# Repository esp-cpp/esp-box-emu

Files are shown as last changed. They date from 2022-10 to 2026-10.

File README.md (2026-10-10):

# esp-box-emu

<table style="padding:10px">
    <tr>
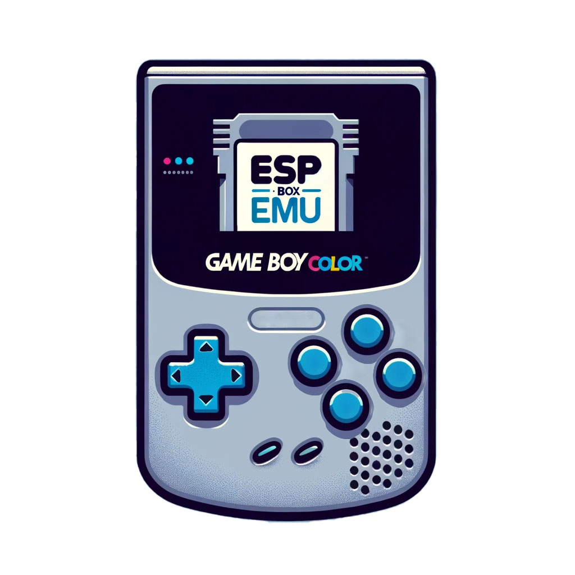
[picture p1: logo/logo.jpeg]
        <td></td>
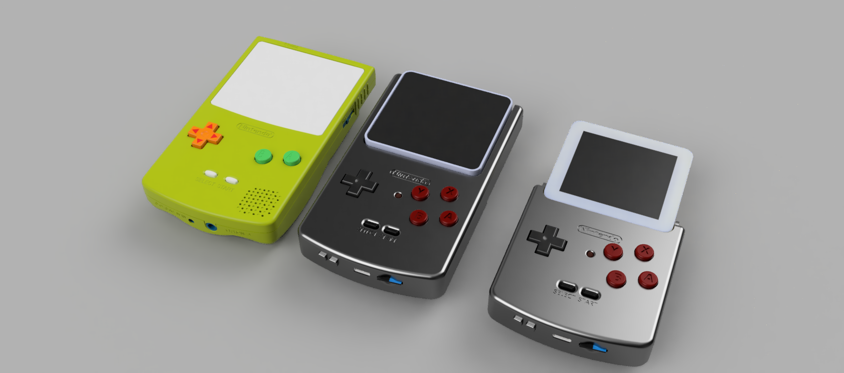
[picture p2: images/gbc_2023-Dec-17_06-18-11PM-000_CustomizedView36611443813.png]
Rendering
        <td></td>
    </tr>
</table>





> A pocket-sized, Game Boy-style retro **emulation handheld** built around the
> ESP32-S3-BOX. Drop in a micro-SD card of ROMs and play NES, Game Boy / Color,
> Sega, MSX, and Genesis games — plus a full-speed port of **Doom** — on hardware
> you can 3D print and build yourself.



https://github.com/user-attachments/assets/2d3da6ea-2e80-42c3-bbd6-5a2c59601201

<!-- markdown-toc start - Don't edit this section. Run M-x markdown-toc-refresh-toc -->
**Table of Contents**

- [esp-box-emu](#esp-box-emu)
  - [Overview](#overview)
  - [Emulators](#emulators)
  - [Gallery](#gallery)
  - [Quick Start — Play It](#quick-start--play-it)
  - [Build the Hardware](#build-the-hardware)
  - [Build the Firmware](#build-the-firmware)
  - [ROMs and SD Card Setup](#roms-and-sd-card-setup)
    - [Boxart images](#boxart-images)
    - [metadata.csv format](#metadatacsv-format)
  - [Features and Roadmap](#features-and-roadmap)
  - [References and Inspiration](#references-and-inspiration)
  - [License](#license)

<!-- markdown-toc end -->

## Overview

The ESP-BOX-EMU turns an [ESP32-S3-BOX or
ESP32-S3-BOX-3](https://github.com/espressif/esp-box) into a handheld retro game
console. A custom add-on board and 3D-printed shell wrap the BOX in a Game Boy
Color form factor — real d-pad and buttons, battery, haptics, and a micro-SD
slot — and the firmware runs a stack of emulators behind a polished LVGL
interface with boxart, save states, and settings.

**Highlights**

- 🎮 **Six systems + Doom** — NES, Game Boy / Color, Sega Master System / Game
  Gear, Sega Genesis, and MSX 1/2 emulators, plus a full-speed **Doom** port —
  all with sound.
- 🧬 **Full-speed Genesis** — a custom **dual-core** port of gwenesis splits the
  emulation across both of the ESP32-S3's cores (CPU + video on one, the sound
  unit on the other) for full-speed Sega Genesis / Mega Drive *with* audio.
- ⚡ **No reboots** — every core and game loads on demand right from the menu, so
  you can jump between titles and even different systems without ever restarting
  the device.
- 🕹️ **Real controls** — d-pad, A/B/X/Y, Start/Select and volume buttons in a
  familiar Game Boy Color layout; the emulator is auto-selected from the ROM
  file extension.
- 💾 **Load from SD** — keep ROMs, boxart, and save states on a micro-SD card,
  and mount the card over USB-C as a mass-storage drive (TinyUSB MSC).
- 💤 **Save anywhere** — up to 5 save slots per game, each with an
  auto-generated screenshot shown in the load menu.
- 🔋 **Portable** — 1000 mAh LiPo battery with USB-C charging.
- 📳 **Haptics** — LRA haptic feedback (DRV2605), including in-game effects in
  Doom (weapon fire, taking damage, pickups, and more).
- 🖼️ **Polished UI** — LVGL menus for ROM select (with boxart) and settings
  (sound, brightness, display scaling, haptics), designed in Squareline Studio.
- 🛠️ **Fully open hardware** — 3D-printable GBC-style case and an open PCB
  (Fusion/Eagle **and** [atopile](https://atopile.io) + [KiCad](https://kicad.org)),
  all included in this repo.

## Emulators

The right emulator is chosen automatically from each ROM's file extension, and
games load on demand **straight from the menu — no reboot required**. Pick a
title, play, then drop back to the menu and launch a different game (or a
completely different system) without ever restarting the device. Every core runs
with audio, and several offer an **Unlocked mode** (toggle with the **X** button)
that removes the frame-rate cap for maximum speed.

| System | Core | Unlocked mode | Notes |
| --- | --- | :---: | --- |
| NES | [nofrendo](https://github.com/espressif/esp32-nesemu) | ✅ | D-Pad / A / B / Start / Select |
| Game Boy / Color | [gnuboy](https://github.com/rofl0r/gnuboy) | ✅ | D-Pad / A / B / Start / Select |
| Sega Master System / Game Gear | [smsplus](https://github.com/ekeeke/smsplus-gx) | ✅ | D-Pad / A / B / Start / Select |
| Sega Genesis / Mega Drive | [gwenesis](https://github.com/bzhxx/gwenesis) | — | Full speed with sound; 6-button pad (A→B, B→A, C→Y) |
| MSX 1 / 2 | [fmsx](https://fms.komkon.org/fMSX/) | — | D-Pad / A / B / Start / Select |
| Doom | [prboom](https://prboom.sourceforge.net/) | — | Full speed with audio **and haptic feedback** |
| Dark Forces | [The Force Engine](https://theforceengine.github.io/) (via [BSzili's Amiga port](https://github.com/BSzili/TheForceEngine/tree/amiga)) | — | Software renderer, iMuse sound effects and OPL3 music; see [Dark Forces setup](#dark-forces-setup) |
| PICO-8 | [femto8](https://github.com/benbaker76/femto8) | — | `.p8` and `.p8.png` carts; D-Pad, A/Y = O, B/X = X, START = PICO-8 pause menu; save states; cartdata saves to `pico8/cdata/`; see [PICO-8 setup](#pico-8-setup) |

> 🧬 **Full-speed Genesis on the S3.** The Genesis core ships with a custom
> **dual-core** modification of gwenesis that spreads the workload across both of
> the ESP32-S3's CPU cores: **core 0** runs the 68000 CPU and VDP (video), while
> **core 1** runs the sound unit (Z80 + YM2612 FM synth + PSG). Sound-chip writes
> are queued and applied in order on core 1, which lets Genesis / Mega Drive
> games run at full speed *with* audio — something a single core can't keep up
> with.

<details>
<summary><strong>Doom controls and haptics</strong></summary>

**Controls:** **A** fire / enter · **B** strafe / backspace · **X** use ·
**Y** weapon toggle · **START** escape · **SELECT** map.

**Haptic feedback** is triggered when you fire a weapon (varies by weapon), take
damage (scaled to the health/armor lost), interact with something (e.g. a door),
or pick up a weapon, ammo, health, armor, a power-up, or a key / card.
</details>

<details>
<summary><strong>Dark Forces controls</strong></summary>

**In a mission:** **D-pad** move / turn · **A** fire · **B** jump · **X** use ·
**Y** next weapon · **START** escape menu. Hold **SELECT** as a modifier:
**SELECT + Left/Right** strafe · **SELECT + Down** crouch · **SELECT + Up**
automap · **SELECT + A** secondary fire · **SELECT + B** headlamp ·
**SELECT + X** gas mask · **SELECT + Y** previous weapon · **SELECT + START**
night vision. Running is always on.

**Menus, briefings and cutscenes:** the **D-pad** moves a virtual mouse cursor,
**A** clicks, **START** is Enter, **B** is Escape (skips cutscenes) and **Y** is
Space. Quitting from the game's escape menu returns to the emulator menu.

**Typing an agent name:** hold **SELECT**: **Right** adds a letter, **Up/Down**
change the last letter, **Left** deletes it; release SELECT and press **START**
to confirm.

The emulator's own pause menu (touch button or START+SELECT) still works for
video scaling and save slots; save slots only work while in a mission.
</details>

## Gallery







https://github.com/esp-cpp/esp-box-emu/assets/213467/3b77f6bd-4c42-417a-9eb7-a648f31b4008

https://github.com/esp-cpp/esp-box-emu/assets/213467/a3d18d03-c6a1-4911-89d1-e18119e8cc03

## Quick Start — Play It

Already have the add-on hardware (or an ESP32-S3-BOX you want to flash)? You
don't need to build anything from source — a prebuilt one-time **programmer** is
published with every release.

1. Download the `programmer` for your OS (`windows`, `macos`, or `linux`) from
   the latest [releases page](https://github.com/esp-cpp/esp-box-emu/releases).
2. Unzip it.
3. Run it: double-click the `.exe` on Windows, or run it from a terminal on
   macOS / Linux, e.g.:

   ```sh
   ./esp-box-emu_programmer_v1.0.0_macos.bin
   ```

   (The version in the filename matches the release you downloaded.)

Then [set up a micro-SD card](#roms-and-sd-card-setup) with your ROMs and you're
ready to play.

## Build the Hardware

The add-on is designed to match the Game Boy Color form factor and reuse GBC
button plastics and silicone membranes for an authentic feel. The shell is meant
to be 3D printed (PLA or PETG on a Prusa i3 mk3+) and assembled with M3 screws.

**Case / mechanical** — printable files are in [./mcad](./mcad) or on
[Printables](https://www.printables.com/model/396931-esp-box-emu). CAD is on
[Fusion 360 (free viewer)](https://a360.co/3le5oCQ):

Fusion 360 CAD (https://a360.co/3le5oCQ)

**Electronics** — schematic and layout files are in [./ecad](./ecad), provided
as both Fusion/Eagle files and [atopile](https://atopile.io) +
[KiCad](https://kicad.org) sources. You can also order the board directly:

<a href="https://www.pcbway.com/project/shareproject/ESP_BOX_EMU_92551d33.html">PCB from PCBWay</a>

**GBC replacement buttons / membranes** used for a good play feel:

- [Silicone pads for Game Boy Color (1)](https://funnyplaying.com/collections/product/products/gbc-replacement-silicone-pads)
- [Silicone pads for Game Boy Color (2)](https://www.retromodding.com/products/game-boy-color-silicone-pads)
- [Game Boy Color button plastics](https://funnyplaying.com/collections/product/products/cgb-custom-buttons?variant=39333911920701)

## Build the Firmware

This repo uses submodules, so clone it recursively:

```sh
git clone --recurse-submodules git@github.com:esp-cpp/esp-box-emu
```

If you already cloned it non-recursively (or forgot the flag), pull the
submodules with:

```sh
git submodule update --init --recursive
```

Then build, flash, and open the serial monitor with [ESP-IDF](https://docs.espressif.com/projects/esp-idf/en/latest/esp32s3/get-started/index.html):

```sh
idf.py -p PORT flash monitor
```

Replace `PORT` with your board's serial port. To exit the monitor, type
`Ctrl-]`.

## ROMs and SD Card Setup

Format a micro-SD card as **FAT** and add your ROMs (`.nes`, `.gb`, `.gbc`, …),
boxart images (`.jpg`), and a `metadata.csv` file (see the example
[metadata.csv](./metadata.csv)).

### Boxart images

Boxart displays best at 100 px wide. The
[./boxart/source/resize.bash](./boxart/source/resize.bash) script resizes every
`.jpg` in `boxart/source` to 100 px wide (preserving aspect ratio) and writes the
results to the `boxart` folder. Copy those onto the SD card and reference them
from your metadata file.

### Dark Forces setup

Dark Forces is played with the original (purchased) game data; the engine does
not include it. Copy the DOS install files onto the SD card into a single
folder, for example `darkforces/`:

```
darkforces/DARK.GOB
darkforces/SOUNDS.GOB
darkforces/SPRITES.GOB
darkforces/TEXTURES.GOB
darkforces/LFD/*.LFD       (menus, briefings and cutscenes)
```

Then reference `DARK.GOB` from `metadata.csv`:

```csv
darkforces/DARK.GOB, boxart/darkforces.jpg, Star Wars: Dark Forces
```

Settings (`settings.ini`) and agent / save files are written to the same folder.

### PICO-8 setup

PICO-8 carts are plain `.p8` text files or `.p8.png` cartridge images. Put them
in a folder on the card (for example `pico8/`) and reference them from
`metadata.csv`:

```csv
pico8/celeste.p8, boxart/celeste.jpg, Celeste Classic
```

Carts that use `cartdata()` save to `pico8/cdata/`. The 128x128 screen shows
1:1 in the "original" video mode and scaled to 240x240 in "fit". Multi-cart
games that `load("#id")` their other carts work when those carts sit in the
same folder as `id.p8.png` / `id.p8`.

What to expect: the Lua interpreter runs at roughly 1.3M instructions per
second on the S3 (its heap lives in PSRAM), enough for carts of Celeste's
weight at full speed, but CPU-heavy carts close to PICO-8's limit run at a
few frames per second. Save states work (the cart's Lua heap and PICO-8
RAM are snapshotted between frames); carts' own `cartdata()` saves are kept
separately; there is no mouse or keyboard.

### metadata.csv format

Each line maps a ROM to its boxart and display name:

```csv
<rom filename>, <rom boxart filename>, <rom display name>
```

Example:

```csv
mario.nes, boxart/mario.jpg, Mario Bros.
super_mario_1.nes, boxart/super_mario_bros_1.jpg, Super Mario Bros.
super_mario_3.nes, boxart/super_mario_bros_3.jpg, Super Mario Bros. 3
zelda.nes, boxart/zelda1.jpg, The Legend of Zelda
zelda_2.nes, boxart/zelda2.jpg, The Legend of Zelda 2: the Adventure of Link
mega_man.nes, boxart/megaman1.jpg, MegaMan
metroid.nes, boxart/metroid1.jpg, Metroid
pokemon_blue.gb, boxart/pokemon_blue.jpg, Pokemon Blue
pokemon_red.gb, boxart/pokemon_red.jpg, Pokemon Red
pokemon_yellow.gbc, boxart/pokemon_yellow.jpg, Pokemon Yellow
links_awakening.gb, boxart/tloz_links_awakening.jpg, The Legend of Zelda: Link's Awakening
links_awakening.gbc, boxart/tloz_links_awakening_dx.jpg, The Legend of Zelda: Link's Awakening DX
```

## Features and Roadmap

A checklist of what's implemented and what's still in progress.

**Emulation**

- [x] Auto-select emulator by ROM extension: NES, GB/GBC, SMS/GG, MSX, Genesis, Doom, Dark Forces, PICO-8
- [x] On-demand core loading — every emulator and game loads at runtime with no reboot needed to switch games or systems
- [x] Custom **dual-core Genesis** (gwenesis): 68000 + VDP on one ESP32-S3 core, sound unit (Z80 + YM2612 + PSG) on the other, for full-speed audio and gameplay
- [x] Doom haptic feedback :rocket:
- [x] Save state (with automatic save-screenshot creation to the SD card)
- [x] Load state — up to 5 slots per game, with save-screenshot previews
- [x] Shared-memory system so many emulators can be built in together while keeping their hot state in fast internal RAM
- [x] Dark Forces (The Force Engine port; software renderer with sound and music)
- [ ] SNES emulator (WIP)

**User interface**

- [x] LVGL ROM-select menu with boxart and title, navigable by controller
- [x] LVGL settings menu (volume, video, haptics) and in-game pause menu
- [x] GUI data (titles + boxart) loaded from the [metadata file](./metadata.csv)
- [x] Squareline Studio source for the LVGL boilerplate ([SLS files](./squareline), [generated files](./components/gui/generated))

**Video and audio**

- [x] Emulator framebuffers in SPIRAM, with queued screen transfers for maximum draw speed
- [x] Video scaling with ORIGINAL, FIT, and FILL display modes
- [x] Audio output over I2S via the es8311 codec ([codec component](./components/codec))
- [x] Mute button toggles audio while a ROM is running
- [x] Haptic feedback via a DRV2605-driven LRA
- [ ] Decorative graphics in the black borders during NES / GB/C emulation (WIP)

**Storage and input**

- [x] micro-SD (FAT) filesystem over SPI
- [x] TinyUSB MSC device to expose the SD card to an attached USB host
- [x] Memory-mapping of the selected ROM from storage into a raw data partition (SPI flash)
- [x] D-pad + A/B/X/Y + Start/Select input (MCP23x17 on v0 hardware, AW9523 on v1)
- [x] Touchscreen input ([tt21100 component](./components/tt21100))

**Hardware**

- [x] Control-board schematic / layout: joystick / d-pad / buttons (via I²C I/O expander + ADC), battery, charger, DRV2605 haptics, micro-SD, boost converter, and USB 2.0 passthrough from USB-C
- [x] Case CAD in the GBC footprint: USB-C port, micro-SD slot, Start/Select, ABXY, and D-pad in familiar locations

## References and Inspiration

**Other NES emulators**

* https://github.com/nesemu/NESemu
* https://github.com/NiwakaDev/NIWAKA_NES
* https://github.com/kanathan/plainNES
* https://github.com/blagalucianflorin/lbnes
* https://github.com/daniel5151/ANESE
* https://github.com/Grandduchy/YaNES

**Other Genesis emulators**

* https://github.com/h1romas4/m5stack-genplus
* https://github.com/libretro/blastem

**Useful background / information**

* https://github.com/alnacle/awesome-emulators
* https://www.zophar.net/nes.html
* https://yizhang82.dev/nes-emu-overview
* https://www.gridbugs.org/zelda-screen-transitions-are-undefined-behaviour/
* https://bgb.bircd.org/pandocs.htm
* https://github.com/pebri86/esplay-gb
* https://github.com/hex007/esp32-gnuboy
* https://github.com/rofl0r/gnuboy
* https://github.com/zid/gameboy
* https://github.com/Jean-MarcHarvengt/MCUME
* https://github.com/OtherCrashOverride/go-play
* [SNES signal reference](https://gamefaqs.gamespot.com/snes/916396-super-nintendo/faqs/5395)
* [NES signal reference](https://wiki.nesdev.com/w/index.php/Standard_controller)
* [Genesis signal reference](https://www.raspberryfield.life/2019/03/25/sega-mega-drive-genesis-6-button-xyz-controller/)
* [DIY Game Boy](https://learn.adafruit.com/pigrrl-raspberry-pi-gameboy/overview)

## License

This project is licensed under the terms in [LICENSE](./LICENSE).

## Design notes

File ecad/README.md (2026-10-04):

# ESP-BOX-EMU ecad

This folder contains the electronic design of the ESP-BOX-EMU.

The ESP-BOX-EMU contains a single circuit board with the following components:
- USB-C connector
- Conductive / Membrane switches for d-pad, abxy, and start/select buttons which mate with GBC membranes and buttons
- Tactile switches for Volume +/-
- RED LED for charging indication
- DRV2605L haptic driver
- JST-PH connector for the LiPo battery
- AW9523 I/O expander
- MCP73831 LiPo charger
- MAX17048 LiPo state-of-charge monitor (I2C)
- MicroSD card slot
- TPS63020 5V buck-boost converter (battery -> 5V for the box)

These features are supported in two different versions of the electronics, targeting:
- ESP32-S3-Box
- ESP32-S3-Box-3

## Layout of this folder

- `elec/src/` - atopile sources (modern atopile >= 0.15 syntax)
- `elec/src/parts/` - atomic parts (auto-generated from LCSC plus local
  custom parts for the GBC membranes/buttons, board outlines and edge fingers)
- `elec/layout/` - KiCad layouts, one folder per build (netlist-synced by
  `ato build`; placement/routing edits are preserved)
- `scripts/` - layout automation (MCAD position export, scripted placement,
  base/connector layout sync)
- `Box Electronics v*.sch/brd`, `Box-3 Electronics v*.sch/brd` - the
  Fusion 360 / Eagle design the boards were actually manufactured from

The pre-migration atopile 0.2 sources, the old shared footprint library and
the old routed KiCad-6 boards were removed after the 0.15 migration; they
are available in git history (pre-2026-07) if ever needed.

## Setup

``` sh
# one time steps on your machine (any of these; uv shown)
uv tool install --python 3.14 atopile
```

Dependencies (e.g. `atopile/ti-tps63020`) are fetched automatically into
`.ato/modules/` on first build; `ato add <package>` adds new ones.

## Build

``` sh
# build everything
ato build

# build for ESP32-S3-BOX
ato build -b box-emu

# build for ESP32-S3-BOX-3
ato build -b box-3-emu
```

### Offline build (atopile 0.16 service migration)

As part of atopile's 0.16 platform migration (services moving from
`*.atopileapi.com` / `packages.atopile.io` to `app.atopile.io`), the hosted
components-picker API used by the 0.15.x CLI
(`components.atopileapi.com`) was taken offline, and no public replacement
endpoint exists for the CLI yet. Until atopile publishes a CLI that speaks
to the new services, build via the local stand-in server, which answers
picker queries from the part data already pinned in this repo:

``` sh
scripts/ato-build-offline.sh                 # all targets
scripts/ato-build-offline.sh -b box-emu-base # one target
```

Two caveats:

- Footprints/symbols still come from `build/cache/parts/easyeda/` (or the
  still-alive EasyEDA API). If the cache is stale (>1 day old), refresh the
  `atopile_queried_at` stamps inside the cached `C*.json` files rather than
  hammering EasyEDA's rate limiter with re-downloads.
- The stand-in returns no part *attributes*, so builds rewrite the hidden
  parameter annotations in the layouts to the design constraints (e.g. a
  resistor annotated `10kΩ ±1%` from the real part data becomes `±5%` from
  the design). The picked LCSC parts, BOM and copper are unchanged; a
  normal online build will restore the exact annotations once the service
  returns.

## Continuous integration

`.github/workflows/atopile.yml` (official `atopile/setup-atopile@v2` action)
builds every target from the checked-in sources with
`ato build --keep-picked-parts --keep-net-names --keep-designators`, then
runs `scripts/canonicalize-boards.py --all` and fails if `git diff` shows
any change to `elec/layout` or `elec/src` -- i.e. the checked-in design
must be exactly reproducible. (We don't use `ato build --frozen`: atopile
0.15.x writes KiCad group member lists in nondeterministic order, which
makes frozen flaky; the canonicalize+diff check gives the same guarantee
robustly.) It then exports gerbers, pick & place, BOM, STEP, GLB and a
rendered PNG for `box-emu` and `box-3-emu` (`-t all -t 3d-image`), plus
top/bottom PDFs via the kicad-cli bundled in the atopile container.
Artifacts are uploaded per board and attached to releases as zips.

Two reproducibility rules this relies on:

- **Parts are pinned.** None of the part `.ato` files carry the
  `is_auto_generated` trait: atopile would otherwise re-download every
  picked part from the EasyEDA API on each build and *replace* the
  checked-in part directory whenever the API response differs (which it
  does between regions, over time, and during their frequent partial
  outages). Without the trait, atopile logs "not overwriting" and the
  repo stays the source of truth. To intentionally update a part, delete
  its directory and re-run `ato create part --search <LCSC>`.
- **After local layout sessions**, run `ato build` +
  `python3 scripts/canonicalize-boards.py --all` and commit the result,
  so CI's rebuild matches byte-for-byte.

The LCSC/EasyEDA API has multi-hour outages; build steps retry, but a
run during a hard outage will still fail at part picking -- just re-run
it later.

## Ordering / manufacturing notes

**Surface finish: order ENIG, not HASL.** The GBC button footprints expose
bare-copper interdigitated fingers that the carbon membrane pucks press
against. With HASL those fingers come back coated in solder (uneven, prone
to oxidation) and the buttons work poorly; with ENIG they come back flat
gold, which is the standard finish for carbon-contact keypads. This is a
per-order fab option (JLCPCB: "Surface Finish" -> "ENIG") and cannot be
enforced from the design files.

Related, already handled in the footprints: the buttons' four corner
connection pads are tented (copper-only, no paste, no mask opening), so
PCBA assembly applies no solder anywhere on the button contact areas. If
you regenerate or edit `GBC_*_BUTTON` footprints, keep the pads
`(layers "F.Cu")` only.

## Working on the KiCad layouts

Each build owns one board file: `elec/layout/<build>/<build>.kicad_pcb`
(KiCad 9+ format; there is no `.kicad_pro` — open the `.kicad_pcb` directly
in KiCad's PCB Editor). The `fp-lib-table` next to each board resolves all
footprints from the atomic parts in `elec/src/parts/`, so the boards are
self-contained as long as the repo layout is intact.

The `.ato` sources are the source of truth for everything electrical;
KiCad is only for placement and routing:

``` sh
# build a target and open its layout in KiCad in one step
ato build -b box-3-emu --open

# or open it manually
open "elec/layout/box-3-emu/box-3-emu.kicad_pcb"
```

The edit loop:

1. Change schematics by editing the `.ato` files (never add/remove
   components or change connectivity in KiCad — the next build will
   revert it).
2. Run `ato build -b <build>`. This syncs footprints and nets into the
   board file. Footprints are matched by their `atopile_address` property,
   so your existing placement and routing are preserved; new components
   appear stacked near the origin for you to place.
3. Place/route in KiCad and save. **Close the board (or at least save it)
   before the next `ato build`** — atopile rewrites the file on disk, and
   KiCad's PCB editor will not auto-reload; reopen the file after each
   build. A stale `~<name>.kicad_pcb.lck` file means KiCad still has it
   open.

Useful flags when iterating on layout: `--keep-designators`,
`--keep-net-names`, and `--keep-picked-parts` take those from the existing
PCB instead of regenerating them, and `--frozen` fails the build if the
PCB would change at all (good for CI).

Recovering from common accidents:

- **Deleted a footprint in KiCad?** Harmless to the design -- the `.ato`
  source is the source of truth, and the next `ato build -b <build>`
  re-adds it (near the origin; its placement is lost, its part gets
  re-picked). Restore known positions with `place-parts.py apply` if it
  was a mechanically-placed part. It's worth running
  `place-parts.py dump` into `positions.json` after every good layout
  session (and committing it) so *every* part's placement has a snapshot.
- **"Duplicate designators found in layout"?** Historical cause: the
  custom KiCad-6-era footprints carried hidden legacy
  `(fp_text reference "U5")` blocks, and KiCad 9 migrates those over the
  Reference field on every load -- so any save reset references to
  library defaults. Fixed 2026-07 by stripping the legacy blocks from all
  custom part footprints and boards. If it ever recurs (e.g. from a
  re-imported old footprint):
  `python3 scripts/fix-duplicate-refs.py <board.kicad_pcb>` then
  `ato build -b <build>` to renumber.
- **Deleted tracks** are only recoverable from git -- commit layout
  checkpoints often.

### Layout reuse (shared button clusters)

Every module instance becomes a KiCad *group* in the board, and the child
builds (`gbc-a-b`, `gbc-dpad`, ...) exist so their layouts can be reused by
the parents. When a parent build adds a sub-module group whose footprints
are all new, atopile pulls that group's placement from the child build's
board. So do the layouts bottom-up, running `ato build` between levels:

* box-3-emu / box-emu (top-level: connector position, final routing)
  * box-3-connector / box-connector
  * box-emu-base (most of the placement/routing work)
    * gbc-dpad
    * gbc-start-select
    * gbc-a-b-x-y
      * gbc-a-b

i.e. lay out `gbc-a-b` first, then `gbc-a-b-x-y` (which pulls the a-b
group), then the other button boards, then `box-emu-base`, and finally the
two top-level variants. The automatic pull only happens when the group
first appears in the parent, so later tweaks to a child layout are not
force-propagated over a parent you've already edited.

To re-pull an updated child layout into a parent on demand, either use the
"Pull Group" toolbar button in the PCB editor (select the group first;
atopile installs the plugin into `~/Documents/KiCad/<ver>/scripting/plugins/`
-- as of atopile 0.15.x only up to KiCad 9.0, so for KiCad 10 copy the
`atopile.py` loader from the `9.0` folder into `10.0` and Tools > External
Plugins > Refresh), or run the same thing from the CLI:

``` sh
ato kicad-ipc layout-sync --legacy \
    --board elec/layout/box-3-emu/box-3-emu.kicad_pcb \
    --include-group connector      # omit to just sync group membership
```

### Shared base layout across the two variants

`BoxEmuBase` is one module, so it is one group (`box`) in both top-level
boards, and its layout — placement *and* routing — lives in exactly one
place: `elec/layout/box-emu-base/box-emu-base.kicad_pcb`. The intended
workflow:

1. Place and route everything except the connector in the **box-emu-base**
   build (use `positions.json` + the placement script below for the
   mechanically-constrained parts, then route by hand).
2. Push it into both variants:

   ``` sh
   ./scripts/sync-base-layout.sh   # pulls groups "box" and "connector"
                                   # into box-emu and box-3-emu, then snaps
                                   # the connector group to the base group
                                   # so the two outline pieces close exactly
                                   # (scripts/align-base-connector.py)
   ```

3. In `box-emu` / `box-3-emu`, only route the connector-bound signals --
   group placement and outline closure are handled by the sync script.
   The relative outline offsets were calibrated by fitting all outline
   footprints against the Eagle board outlines (0.000 mm rms) and live in
   `scripts/align-base-connector.py`.

If you drag the `box` or `connector` group while editing a top-level board
(fine for repositioning on the sheet), the two outlines separate -- re-run
`python3 scripts/align-base-connector.py` (safe standalone; it snaps the
connector group back to the base group, prints an outline-closure
verification, and refuses to run while the board is open in KiCad so a
later KiCad save can't silently undo it). Reopen the board in KiCad after
running it.

The connector footprints themselves (TE dock connector on box-3, PMOD /
power edge fingers on box) are placed within their boards from the STEP
assemblies via `elec/layout/box-connector/cad_map.json` and
`elec/layout/box-3-connector/cad_map.json`, same flow as the base board
(export -> place-parts apply -> build). Note the box-3 dock connector's
r=180 is meaningful: it puts pad A1 on the side that mates with the box,
matching the manufactured Eagle board.

Pulls replace the contents of the pulled group, so keep variant-specific
routing (base-to-connector tracks) outside the `box` group — tracks you
draw in the parent are not group members by default, so this is the
natural behavior; just don't add them to the group.

### Scripted placement from MCAD

Mechanically-constrained parts (buttons, membranes, USB-C, uSD, battery
connector, volume switches) have known positions that come from the
enclosure CAD. Those live in `elec/layout/box-emu-base/positions.json`,
keyed by each footprint's stable `atopile_address` (e.g.
`dpad.up_button.btn`, `usb_c.conn`, `uSD.card`) so they survive rebuilds
and designator changes. When the MCAD/STEP changes, update the numbers and
re-apply:

``` sh
# apply positions to the board (position, rotation, front/back side)
python3 scripts/place-parts.py apply \
    elec/layout/box-emu-base/box-emu-base.kicad_pcb \
    elec/layout/box-emu-base/positions.json

ato build -b box-emu-base       # re-sync the board
./scripts/sync-base-layout.sh   # push into both variants
```

`scripts/place-parts.py dump <board>` regenerates the JSON from the
board's current state (useful to bootstrap the file or to capture manual
edits back into it). The optional `transform` block (`dx`/`dy`/`flip_y`)
converts CAD coordinates into KiCad's frame (KiCad y points down). Parts
not listed in the JSON are never touched.

### Generating positions.json from the Fusion 360 assembly

Instead of typing coordinates by hand, positions are extracted from the
STEP exports of the enclosure assemblies (`mcad/esp-box-emu.step` and
`mcad/esp-box-emu-3.step`; the PCB must be present as a component in the
assembly). After re-exporting from Fusion 360:

``` sh
# 1. discover occurrence names in the STEP (only needed when the
#    assembly structure / names change)
uv run scripts/export-positions-from-step.py list ../mcad/esp-box-emu.step

# 2. update elec/layout/box-emu-base/cad_map.json if needed:
#    - board.occurrence: the PCB component's name
#    - board.axes / kicad_origin: the CAD->KiCad frame (already calibrated)
#    - each part's "cad" name (+ one-time r_offset rotation calibration)

# 3. extract placements into positions.json
uv run scripts/export-positions-from-step.py export \
    ../mcad/esp-box-emu.step \
    elec/layout/box-emu-base/cad_map.json \
    elec/layout/box-emu-base/positions.json

# 4. apply / rebuild / propagate as usual
python3 scripts/place-parts.py apply \
    elec/layout/box-emu-base/box-emu-base.kicad_pcb \
    elec/layout/box-emu-base/positions.json
ato build -b box-emu-base
./scripts/sync-base-layout.sh
```

The script is self-contained (`uv run` fetches its OCP dependency on first
use). Front/back side is detected from the part's frame orientation and
can be overridden per entry with `"side"`; `"r_offset"` absorbs the
difference between footprint and CAD 0-degree orientations; `"offset"`
(anchor-frame mm) places bodiless parts relative to a CAD neighbor (used
for the a/b/x/y/start/select carbon pads, anchored to their membranes).
Re-run steps 3-4 whenever the MCAD changes.

All three `cad_map.json` files (box-emu-base, box-connector,
box-3-connector) are fully calibrated (2026-07): the Fusion board
components use the Eagle brd coordinate frames verbatim, all outline
footprints match the Eagle outlines exactly (0.000 mm rms), and the
anchor-convention differences between the old board parts and the new
LCSC parts (uSD, USB-C, battery JST, volume switches) are encoded in each
entry's `"offset"`/`"r_offset"`. Re-exports of the STEPs therefore produce
correct placements with no further calibration unless a part is swapped
for a different physical component.

### KiCad 10 file-format warning

atopile 0.15.x reads/writes the KiCad 9 board format (`version 20241229`).
**KiCad 10 silently upgrades any board it saves to `version 20260206`,
which atopile cannot parse** -- builds of that target fail and layout
pulls silently skip the group ("Group ... not found in layout maps").
Until atopile ships KiCad 10 support, after editing a board in KiCad 10
run:

``` sh
python3 scripts/downgrade-kicad10-pcb.py elec/layout/<build>/<build>.kicad_pcb
ato build -b <build>   # normalizes the file back to atopile's format
```

(or do layout work in KiCad 9, which reads and writes the format natively).

Note: the boards in `elec/layout/` were regenerated during the atopile
0.15 migration. Mechanically-constrained placement is scripted from the
MCAD STEP files (see above); routing must be redone by hand. The old
routed boards (atopile 0.2 era, KiCad 6 format) are in git history
(pre-2026-07) if a routing reference is ever wanted.

## Differences from the manufactured (Fusion 360) boards

The atopile design intentionally deviates from the Eagle/Fusion `v36`/`v11`
boards in a few places, mostly to reduce battery drain when the board sits
idle (see git history for details):

- battery sense divider is 1M + 1M with a 100nF sampling cap (was 10k + 10k,
  which drained ~200uA from the battery continuously)
- 5V rail comes from a TPS63020 buck-boost in power-save (PFM) mode with
  VINA/EN properly tied to VIN and PS/SYNC tied low
- DRV2605L gets its datasheet-required 1uF REG bypass and a VDD decoupler
- the AW9523 interrupt line is routed to the box (IO21) on both variants

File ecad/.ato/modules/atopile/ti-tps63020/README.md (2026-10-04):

# Texas Instruments TPS63020 High Efficiency Single Inductor Buck-boost Converter

## Overview

The TPS63020 is a high-efficiency, single-inductor buck-boost converter with 4-A switches. It provides a power supply solution with a 1.8V to 5.5V input voltage range and delivers output voltages between 1.2V to 5.5V. This makes it ideal for battery-powered applications where the input voltage can be above, below, or equal to the output voltage.

## Key Features

- Input voltage range: 1.8V to 5.5V
- Output voltage range: 1.2V to 5.5V (adjustable)
- Output current: up to 3A (buck mode), 2A (boost mode)
- Switching frequency: 2.4MHz typical
- Efficiency: up to 95%
- Small solution size with integrated switches
- Power good output

## Usage

```ato

import ElectricPower

from "atopile/ti-tps63020/ti-tps63020.ato" import TPS63020_driver

module Usage:
    """
    Example usage of the TPS63020 buck-boost converter
    """

    # Power rails
    power_in = new ElectricPower
    power_3v3 = new ElectricPower

    # Configure input power (e.g., from battery)
    assert power_in.voltage within 2.5V to 5V

    # Configure output power
    assert power_3v3.voltage within 3.3V +/- 5%

    # Create buck-boost converter
    converter = new TPS63020_driver

    # Connect power
    power_in ~> converter ~> power_3v3
```

## Implementation Details

This package includes:
- Automatic calculation of feedback resistor values
- Proper decoupling capacitors on input and output
- Inductor selection with appropriate current rating
- Power good pullup resistor
- Compensation network calculations

The module automatically handles:
- Right half-plane zero frequency verification for stable operation
- Peak inductor current calculations
- Proper component sizing based on voltage and current requirements

## Contributing

Contributions to this package are welcome via pull requests on the GitHub repository.

## License

This atopile package is provided under the [MIT License](https://opensource.org/license/mit/).

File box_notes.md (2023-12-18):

### ESP32 S3 Box Info:

It uses GPIO_NUM_46 to control power to the speaker, so if you do not set that
as output HIGH, then you will never hear anything T.T

The ESP32 S3 Box has two PMOD headers, PMOD1 and PMOD2, which have the following
pins:

* PMOD1
  * IO40 (I2C_SCL)
  * IO41 (I2C_SDA)
  * IO38
  * IO39
  * IO42
  * IO21
  * IO19 (USB_D-, U1RTS, ADC2_CH8)
  * IO20 (USB_D+, U1CTS, ADC2_CH9)
* PMOD2
  * IO09 (FSPIHD, TOUCH9, ADC1_CH8)
  * IO10 (FSPICS0, TOUCH10, ADC1_CH9)
  * IO11 (FSPID, TOUCH11, ADC2_CH0)
  * IO12 (FSPICLK, TOUCH12, ADC2_CH1)
  * IO13 (FSPIQ, TOUCH13, ADC2_CH2)
  * IO14 (FSPIWP, TOUCH14, ADC2_CH3)
  * IO44 (U0RXD)
  * IO43 (U0TXD)

#### LCD

The LCD is a ST7789 320x240 BGR display connected via SPI.

ESP32s3 LCD Pinout:

| LCD Function | ESP I/O Pin |
|---|---|
| Data / Command | 4 |
| Chip Select | 5 |
| Serial Data | 6 |
| Serial Clock | 7 |
| Reset | 48 |
| Backlight | 45 |

#### Touch

The ESP32S3 Box uses a capacitive touch controller connected via I2C. On the
ESP32-S3-BOX it is a TT21100, and on the ESP32-S3-BOX-3 it is a GT911.

#### Audio

The ESP32s3 Box has a few audio codec coprocessors connected simultaneously to
I2S (data) and I2C (configuration). It uses an encoder codec chip (ES7210) for
audio input from the multiple mics on-board, and a decoder chip (es8311) for
audio output to the speaker (output power controlled by GPIO 46). It also uses

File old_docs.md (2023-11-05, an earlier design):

# esp-box-emu
Emulator(s) running on ESP BOX with custom pcb and 3d printed enclosure :)

https://user-images.githubusercontent.com/213467/236730090-56c3bd64-86e4-4b9b-a909-0b363fab4fc6.mp4

https://user-images.githubusercontent.com/213467/220791336-eb24116d-0958-4ab7-88bd-f6a5bd6d7eb1.mp4

## Description

This project is a little retro game emulation system running on ESP32-S3-BOX. It
is built using the following:

- [ESPP](http://github.com/esp-cpp/espp)
- [LVGL](http://github.com/lvgl/lvgl)
- [Squareline Studio](http://squareline.io) (for designing and generating LVGL)
- Nofrendo (NES emulator)
- GNUBoy (GB / GBC emulator)

## Videos

### Gameboy Color

This video shows settings page (with audio control and video scaling control), and then Links Awakening DX. While running the ROMs, the video scaling can be toggled through the three options (Original, Fit, and Fill) using the BOOT button on the side of the ESP-S3-BOX and the audio output can be toggled on / off using the MUTE button on the top.

https://user-images.githubusercontent.com/213467/202577104-da104296-c888-47f4-bb69-e1dcac7f3a08.mp4

### NES (Super Mario Bros. and Zelda, turning audio up for zelda :) )

https://user-images.githubusercontent.com/213467/200666734-d5fdd27e-d335-462b-9f27-c93c5750de01.mp4

https://user-images.githubusercontent.com/213467/201548463-9870a1c1-886c-4540-b1c6-c7ed3b49d8a5.mp4

### Gameboy (Pokemon and Links Awakening)

https://user-images.githubusercontent.com/213467/200667103-71425aa6-3e77-41b1-83d1-c2072a1a0ecb.mp4

Older Videos:
* [heavily compressed](https://user-images.githubusercontent.com/213467/200664203-46058c44-3025-4e81-973f-27ada573d5d2.mp4)
* [just zelda](https://user-images.githubusercontent.com/213467/199843965-1bf38a5f-2cc6-4ff0-adba-bbd67b366bc3.mp4)

## Images

<table style="padding:10px">
    <tr>
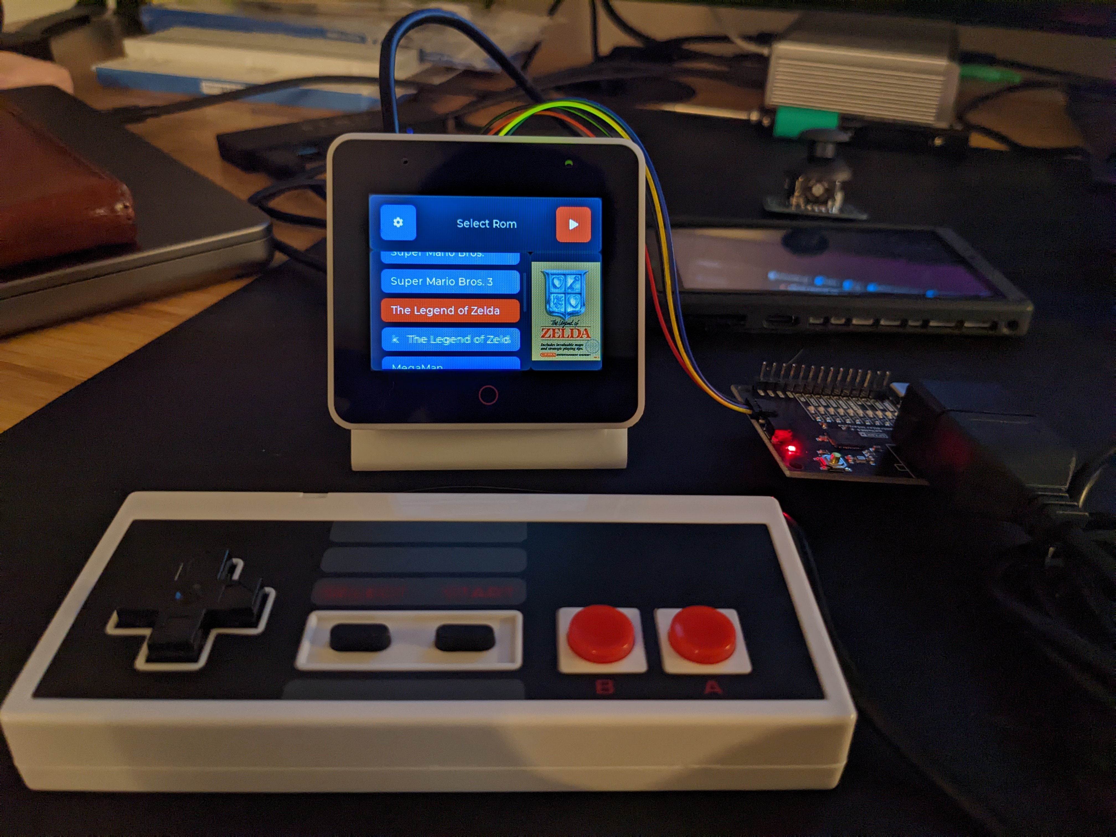
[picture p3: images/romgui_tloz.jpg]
Rom GUI: Zelda (NES)
        <td></td>
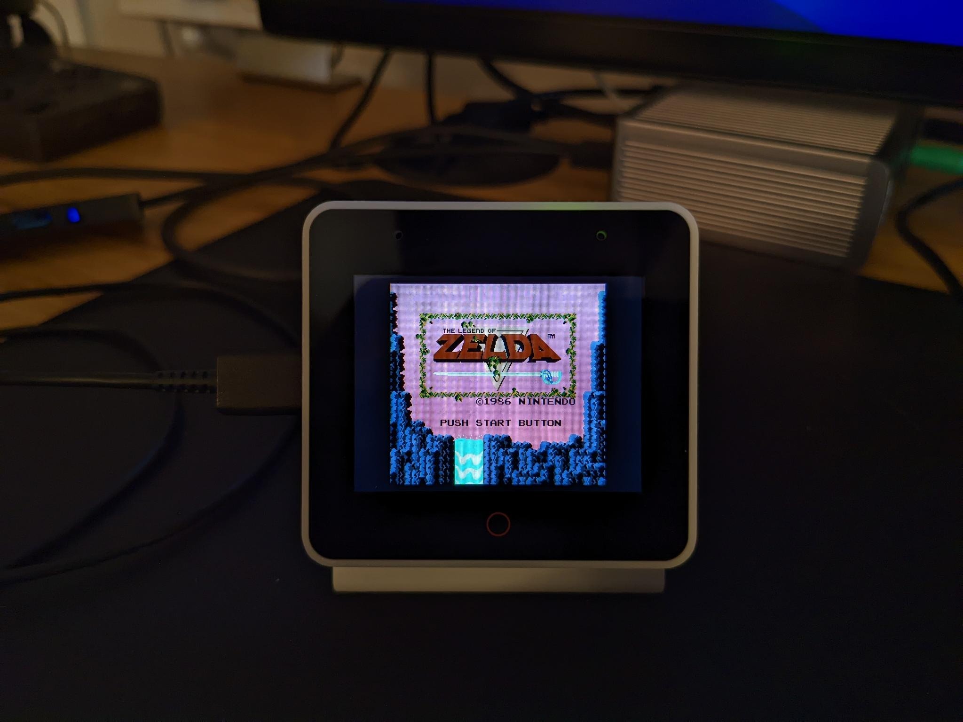
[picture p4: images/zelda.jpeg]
Zelda (NES) emulated
        <td></td>
    </tr>
    <tr>
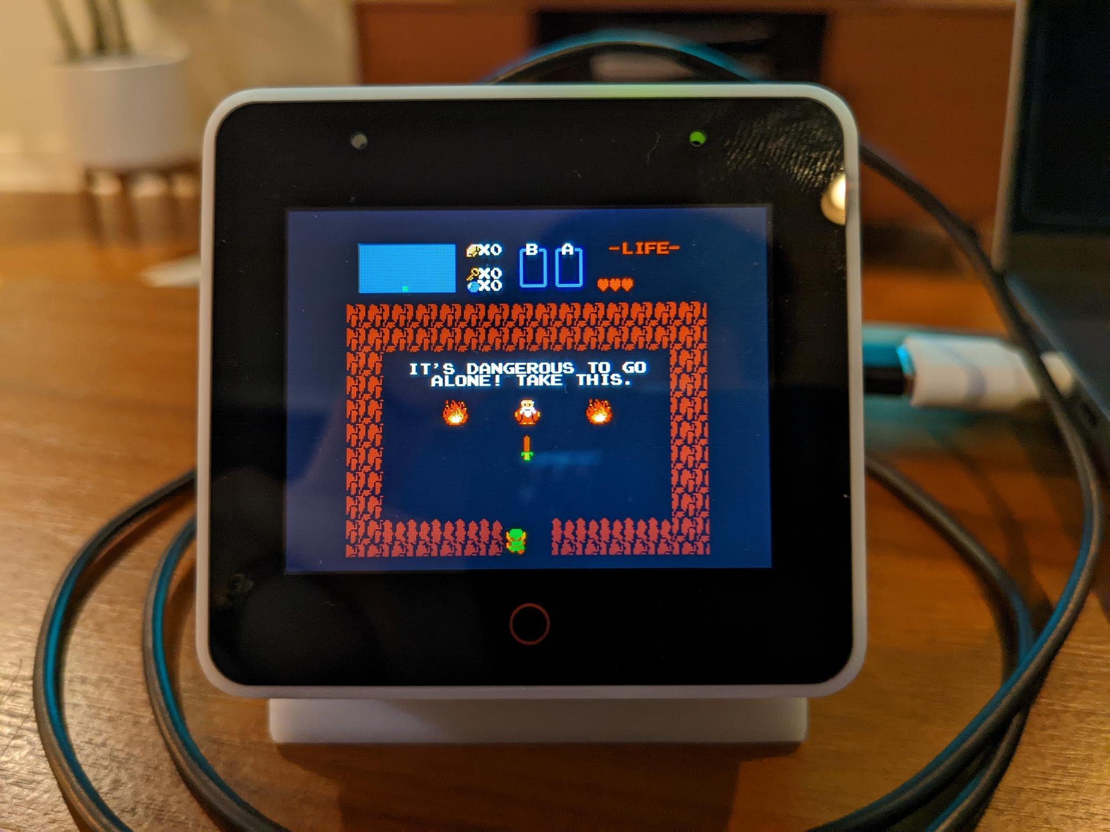
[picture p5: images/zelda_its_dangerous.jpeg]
It's Dangerous To Go Alone, Take This!
        <td></td>
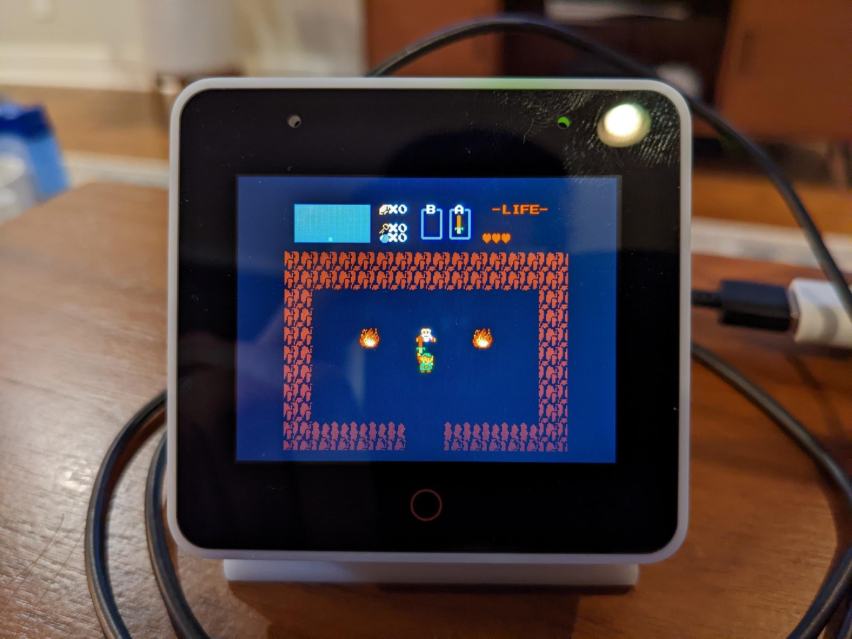
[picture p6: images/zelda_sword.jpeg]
Zelda (NES) Get Sword
        <td></td>
    </tr>
    <tr>
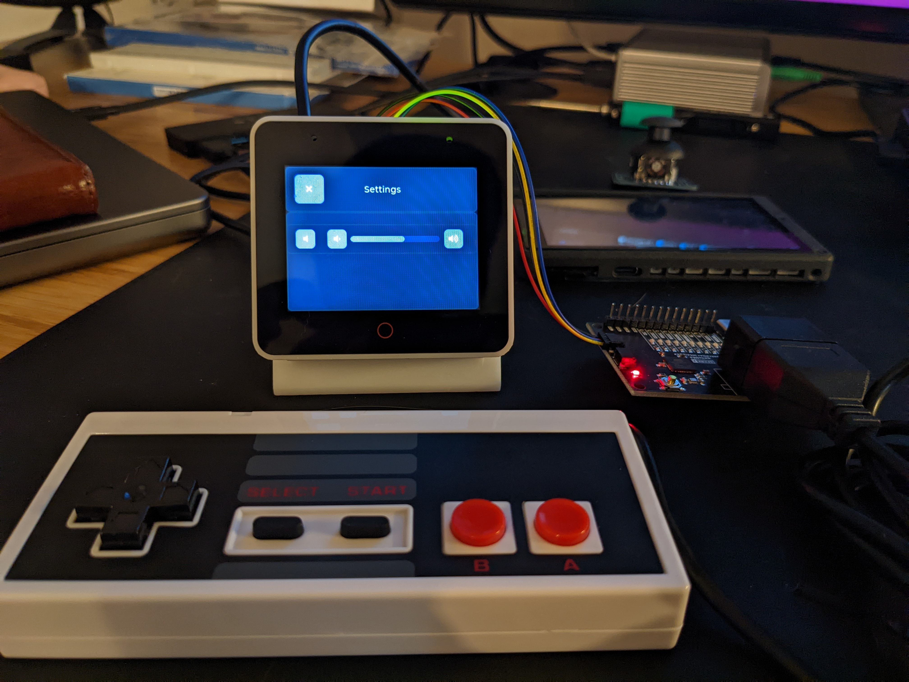
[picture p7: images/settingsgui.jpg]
Settings Screen (Audio Volume for now)
        <td></td>
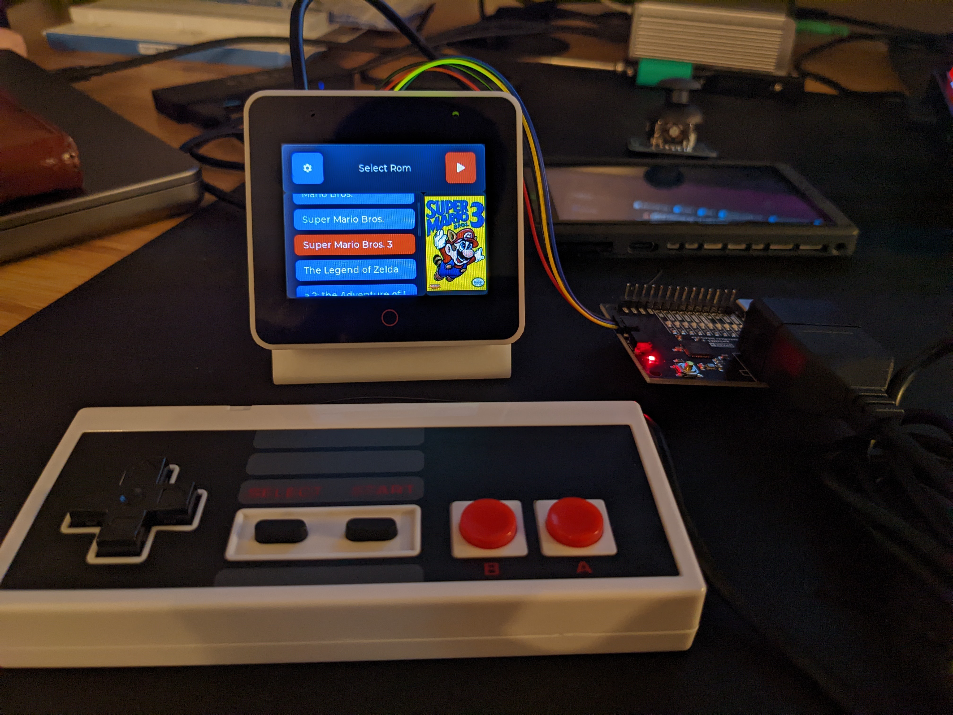
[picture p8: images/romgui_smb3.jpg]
Super Mario Bros. 3 (NES)
        <td></td>
    </tr>
    <tr>
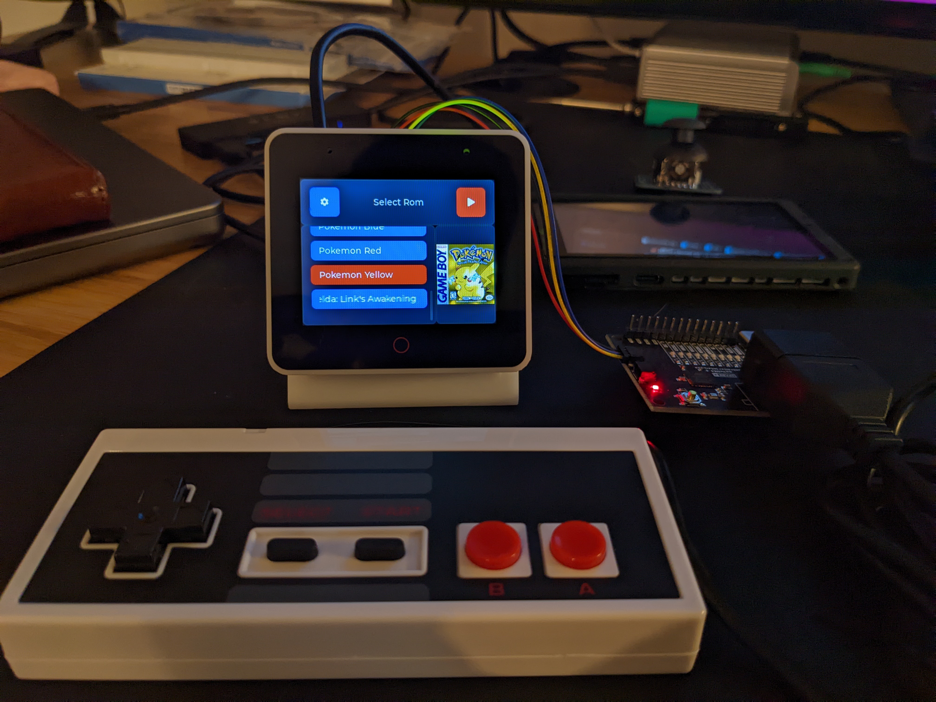
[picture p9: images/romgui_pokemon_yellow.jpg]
Pokemon Yellow (GBC)
        <td></td>
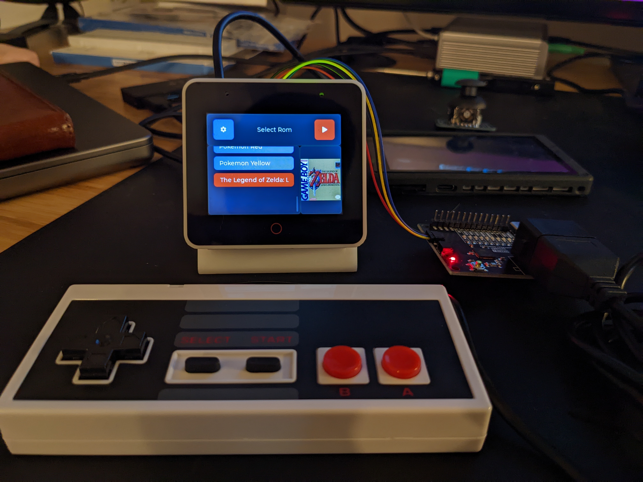
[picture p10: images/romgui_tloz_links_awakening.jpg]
Link's Awakening (GB)
        <td></td>
    </tr>
    <tr>
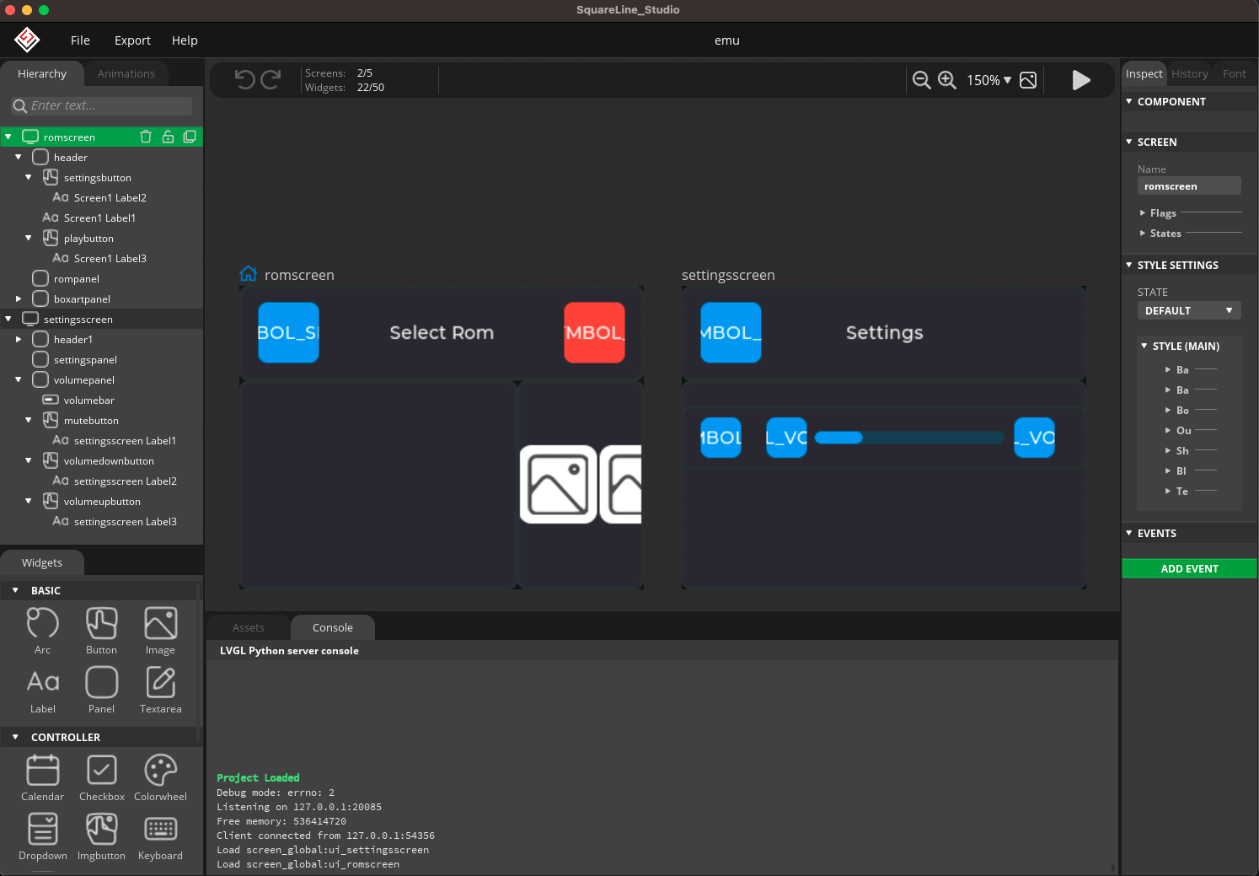
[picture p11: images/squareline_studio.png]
Squareline Studio Design
        <td></td>
    </tr>
</table>

## Features

Note: for the ECAD + MCAD I'm using the free version of Fusion360.
<table style="padding:10px">
    <tr>
        <td>Prototype</td>
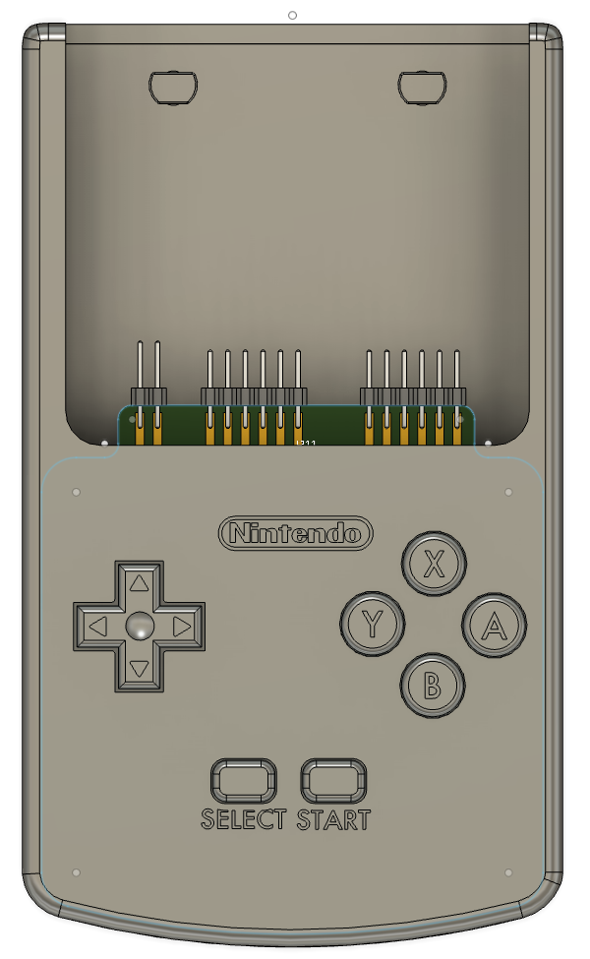
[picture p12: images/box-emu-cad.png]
CAD
        <td></td>
    </tr>
</table>

Link to Fusion 360 CAD:
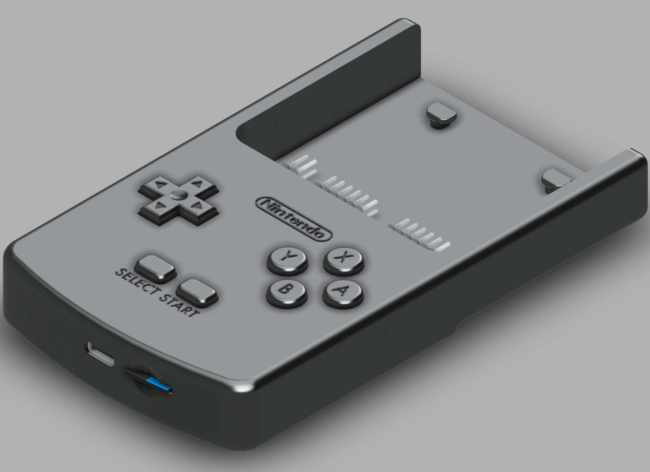
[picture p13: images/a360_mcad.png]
a360_mcad (https://a360.co/3le5oCQ)


The printable files can be found in the [./mcad](./mcad) folder or can be downloaded from [printables](https://www.printables.com/model/396931-esp-box-emu).

This project has the following features (still WIP): 

 - [x] Squareline Studio design files for generating boilerplate LVGL ([SQS files](./squareline), [Generated files](./components/gui/generated))
 - [x] LVGL gui for selecting emulators / roms (showing boxart and name)
 - [x] LVGL gui for controlling settings (such as volume) (using [gui component](./components/gui))
 - [x] Loading of gui data (rom titles and boxart) from metadata file (example [here](./metadata.csv))
 - [x] Audio output (using I2S + es8311 audio codec, [es8311 component](./components/codec))
 - [x] Interaction with [QwiicNes NES gamepad](https://www.sparkfun.com/products/18038)
 - [x] Interaction with analog joystick + buttons (using [controller component](./components/controller))
 - [x] Interaction with d-pad + buttons (using [controller component](./components/controller))
 - [x] Interaction with touchscreen (using [tt21100 component](./components/tt21100))
 - [x] Navigation of LVGL rom menu with controller (up,down,start)
 - [ ] Runnable emulators (automatically selected by rom extension):
   - [x] NES emulator (~100 FPS running Legend of Zelda)
   - [x] GB/GBC emulator (~100 FPS running Link's Awakening DX (GBC))
   - [ ] SNES emulator
   - [ ] SMS / Genesis emulator
 - [x] LittleFS file system for local storage of roms and metadata
 - [x] Support for uSD (FAT) filesystem over SPI
 - [x] Memory mapping of selected rom data from storage (littlefs or uSD) into
       raw data partition (SPIFLASH)
 - [X] Emulator framebuffers on SPIRAM 
 - [x] Some hacky support for BT Gamepad input (see note below regarding wifi use.) 
 - [x] Refactor to have a blit function which queues up transfers for screen into a task
 - [x] Scaling of GB/GBC display to support original, fit, and fill video scaling modes
 - [x] Scaling for NES display to support original (which is fit) and fill video scaling modes
 - [x] Use mute button to toggle volume output while running the roms
 - [x] Use boot button to switch between video scaling modes while running the roms
 - [x] Feedback through tiny haptic motor (DRV2605)
 - [x] Save state
 - [x] Load state
 - [ ] Feedback through BLDC haptic motor (see
       https://github.com/scottbez1/smartknob)
 - [x] State management (UI to select state when loading roms, ui/buttons for
       saving/loading states while running)
 - [ ] Favorites menu?
 - [ ] Recently played menu?
 - [ ] Show emulator with rom for easy sorting / finding
 - [ ] Graphics in black borders next to rom display during NES / GB/C emulation
 - [x] Schematic / Layout for control board peripheral containing
   - [x] joystick / D-Pad / Button inputs (via i2c I/O expander / ADC)
   - [x] Battery
   - [x] Charger circuit
   - [x] DRV2605 haptic motor (LRM / ECM)
   - [x] uSD card
   - [x] boost converter
   - [x] usb 2.0 passthrough from usb-c
   - [ ] TMC BLDC driver chip
   - [ ] ABI magnetic encoder chip
   - [ ] BLDC motor (haptics)
 - [x] CAD for control board peripheral case in the same footprint as GBC
   - [x] USB-C Port for programming / charging
   - [x] uSD card slot for roms
   - [x] start / select buttons (same location as GBC)
   - [x] ABXY buttons (basically same size / location as GBC)
   - [x] Directional Pad (same size / location as GBC)
 - [ ] Use same audio + video tasks for both NES and GB/C emulation
 - [ ] FTP Client for browsing remote FTP server of roms and displaying their
       data in LVGL
    
### Support for dynamically loading emulators (TBD)

 Down the line I'd like to add the ability to load the emulator cores from the
 FTP server (which would be pre-compiled ESP32 libraries) so that they wouldn't
 take up as much space on the ESP32 itself. Right now that's not a huge concern
 though because the ESP (S3 module in the ESP BOX especially) has more than
 enough flash for the emulators so assuming their RAM can be managed it won't be
 much of an issue.
 
 Info for loading elf files at runtime:
 https://github.com/niicoooo/esp32-elfloader.
 [Here](https://github.com/joltwallet/jolt_wallet/tree/master/jolt_os/jelf_loader)
 is another implementation.

## Filsystem / Storage

The emu-box supports both on-board FLASH storage through LittleFS (limited to
the 16 MB flash chip in the S3 in the box) as well as support for external FAT
filesystems on a uSD card connected via SPI (this is the DEFAULT option):

| uSD SPI | ESP32 GPIO (exposed via PMOD header) |
|---|---|
| CS | 10 |
| MOSI | 11 |
| MISO | 13 |
| SCLK | 12 |

The storage can be changed via `menuconfig`.

### Using LittleFS (Internal FLASH):

You will need to set up a `flash_data/` folder which contains your roms (.nes,
.gb, .gbc), images (.jpg), and metadata.csv. (See next section for more info
about Rom Images and the metadata file). The contents of this folder will be
flashed into the `littlefs` partition.

At least once, you'll need to update the
[./main/CMakeLists.txt](./main/CMakeLists.txt) to uncomment the line that has
`FLASH_IN_PROJECT` as part of the `littlefs_create_partition_image` command -
this will flash all files in your `flash_data/` folder onto the `littlefs`
partition on the embedded FLASH chip. Alternatively, you can use the
`esptool.py`, `parttool.py` as mentioned in [the SPIFFS
docs](https://docs.espressif.com/projects/esp-idf/en/latest/esp32/api-reference/storage/spiffs.html).

### Using FAT (external uSD card):

Format your uSD card as a FAT filesystem and add your roms (.nes, .gb, .gbc),
images (.jpg), and metadata.csv. (See next section for more info about Rom
Images and the metadata file). Make sure the uSD card is plugged into the socket
and the wires are properly connected to the pins (including 3.3V and GND) listed
above.

## ROM Images

For ease of use, there is a
[./boxart/source/resize.bash](./boxart/source/resize.bash) script which will
resize all `jpg` images in the `boxart/source` folder to be 100x px wide (keep
aspect ratio but make width 100 px) and put the resized versions in the `boxart`
folder. You can then copy them onto your sd card and update your metadata file
appropriately.

### Metadata.csv format

``` csv
<rom filename>, <rom boxart filename>, <rom display name>
```

Example:

``` csv
mario.nes, boxart/mario.jpg, Mario Bros.
super_mario_1.nes, boxart/super_mario_bros_1.jpg, Super Mario Bros.
super_mario_3.nes, boxart/super_mario_bros_3.jpg, Super Mario Bros. 3
zelda.nes, boxart/zelda1.jpg, The Legend of Zelda
zelda_2.nes, boxart/zelda2.jpg, The Legend of Zelda 2: the Adventure of Link
mega_man.nes, boxart/megaman1.jpg, MegaMan
metroid.nes, boxart/metroid1.jpg, Metroid
pokemon_blue.gb, boxart/pokemon_blue.jpg, Pokemon Blue
pokemon_red.gb, boxart/pokemon_red.jpg, Pokemon Red
pokemon_yellow.gbc, boxart/pokemon_yellow.jpg, Pokemon Yellow
links_awakening.gb, boxart/tloz_links_awakening.jpg, The Legend of Zelda: Link's Awakening
links_awakening.gbc, boxart/tloz_links_awakening_dx.jpg, The Legend of Zelda: Link's Awakening DX
```

## References and Inspiration:

### ESP32 S3 Box Info:

It uses GPIO_NUM_46 to control power to the speaker, so if you do not set that
as output HIGH, then you will never hear anything T.T

The ESP32 S3 Box has two PMOD headers, PMOD1 and PMOD2, which have the following
pins:

* PMOD1
  * IO40 (I2C_SCL)
  * IO41 (I2C_SDA)
  * IO38
  * IO39
  * IO42
  * IO21
  * IO19 (USB_D-, U1RTS, ADC2_CH8)
  * IO20 (USB_D+, U1CTS, ADC2_CH9)
* PMOD2
  * IO09 (FSPIHD, TOUCH9, ADC1_CH8)
  * IO10 (FSPICS0, TOUCH10, ADC1_CH9)
  * IO11 (FSPID, TOUCH11, ADC2_CH0)
  * IO12 (FSPICLK, TOUCH12, ADC2_CH1)
  * IO13 (FSPIQ, TOUCH13, ADC2_CH2)
  * IO14 (FSPIWP, TOUCH14, ADC2_CH3)
  * IO44 (U0RXD)
  * IO43 (U0TXD)

#### LCD

The LCD is a ST7789 320x240 BGR display connected via SPI.

ESP32s3 LCD Pinout:

| LCD Function | ESP I/O Pin |
|---|---|
| Data / Command | 4 |
| Chip Select | 5 |
| Serial Data | 6 |
| Serial Clock | 7 |
| Reset | 48 |
| Backlight | 45 |

#### Touch

The ESP32S3 Box uses a capacitive touch controller connected via I2C.

The touch driver can be either the TT21100 or Ft5x06 chip.

NOTE: it appears the one I have (regular ESP32 S3 BOX) which has the red circle
at the bottom of the display (the `HOME` button) uses the TT21100 chip.

#### Audio

The ESP32s3 Box has a few audio codec coprocessors connected simultaneously to
I2S (data) and I2C (configuration). It uses an encoder codec chip (ES7210) for
audio input from the multiple mics on-board, and a decoder chip (es8311) for
audio output to the speaker (output power controlled by GPIO 46).

ESP32s3 Audio Pinout:

| Audio Function | ESP I/O Pin |
|---|---|
| I2S MCLK | 2 |
| I2S SCLK | 17 |
| I2S LRCK | 47 |
| I2S Data Out | 15 |
| I2S Data In | 16 |
| Speaker Power  | 46 |
| Mute Button | 1 |

I2C Pinout (shared with touchscreen chip above):

| I2C Function | ESP I/O Pin |
|---|---|
| SCL | 18 |
| SDA | 8 |

### Controllers

#### Sparkfun QwiicNES

The Sparkfun QwiicNES ([product page](https://www.sparkfun.com/products/18038),
[library](https://github.com/sparkfun/SparkFun_QwiicNES_Arduino_Library)) is a
NES controller adapter that supports direct GPIO and I2C. The
[controller](./components/controller) component we have supports direct GPIO
configuration if you choose to use it (find the configuration in the
[./components/box-emu-hal/src/input.cpp](./components/box-emu-hal/src/input.cpp)).

It also however has a ATmega 32u4 which allows it to act as a USB gamepad and
exposes the NES gamepad over I2C as well. For ease of use, the I2C functionality
has been wrapped into a [qwiicnes component](./components/qwiicnes). There is an
example of using this qwiicnes component in the component's example folder.

#### Joy bonnet

The [joy bonnet](https://pinout.xyz/pinout/joy_bonnet) was designed as a
raspberry pi hat which has abxy, start/select, analog joystick, and player 1 /
player 2 buttons. It's useful for prototyping input / hardware and testing how
well the emulators run (by playing them of course ;) )

The joystick is routed out via an ADS1015 I2C ADC chip (addr 0x48), with the
__Y-axis__ mapped to __channel 0__, and the __X-axis__ mapped to __channel 1__.
[see
here](https://github.com/adafruit/Adafruit-Retrogame/blob/master/joyBonnet.py)

Pinout (pin number is w.r.t. header, not pi GPIO):

| Button  | Joy Bonnet Header Pin Number |
|---|---|
| A | 32 |
| B | 31 |
| X | 36 |
| Y | 33 |
| Start | 37 |
| Select  | 38 |
| Ground  | 6, 9, 14, 20, 25, 30, 34, 39 |
| 5V | 2, 4 |
| 3V3 | 1, 17 |
| I2C SDA | 3 |
| I2C SCL | 5 |

### Other NES Emulators
* https://github.com/nesemu/NESemu
* https://github.com/NiwakaDev/NIWAKA_NES
* https://github.com/kanathan/plainNES
* https://github.com/blagalucianflorin/lbnes
* https://github.com/daniel5151/ANESE
* https://github.com/Grandduchy/YaNES

### Useful Background / Information
* https://www.zophar.net/nes.html
* https://yizhang82.dev/nes-emu-overview
* https://www.gridbugs.org/zelda-screen-transitions-are-undefined-behaviour/
* https://bgb.bircd.org/pandocs.htm
* https://github.com/pebri86/esplay-gb
* https://github.com/hex007/esp32-gnuboy
* https://github.com/rofl0r/gnuboy
* https://github.com/zid/gameboy
* https://github.com/Jean-MarcHarvengt/MCUME
* https://github.com/OtherCrashOverride/go-play
* [SNES Signal Reference](https://gamefaqs.gamespot.com/snes/916396-super-nintendo/faqs/5395)
* [NES Signal Reference](https://wiki.nesdev.com/w/index.php/Standard_controller)
* [Genesis Signal Reference](https://www.raspberryfield.life/2019/03/25/sega-mega-drive-genesis-6-button-xyz-controller/)
* [DIY Gameboy](https://learn.adafruit.com/pigrrl-raspberry-pi-gameboy/overview)

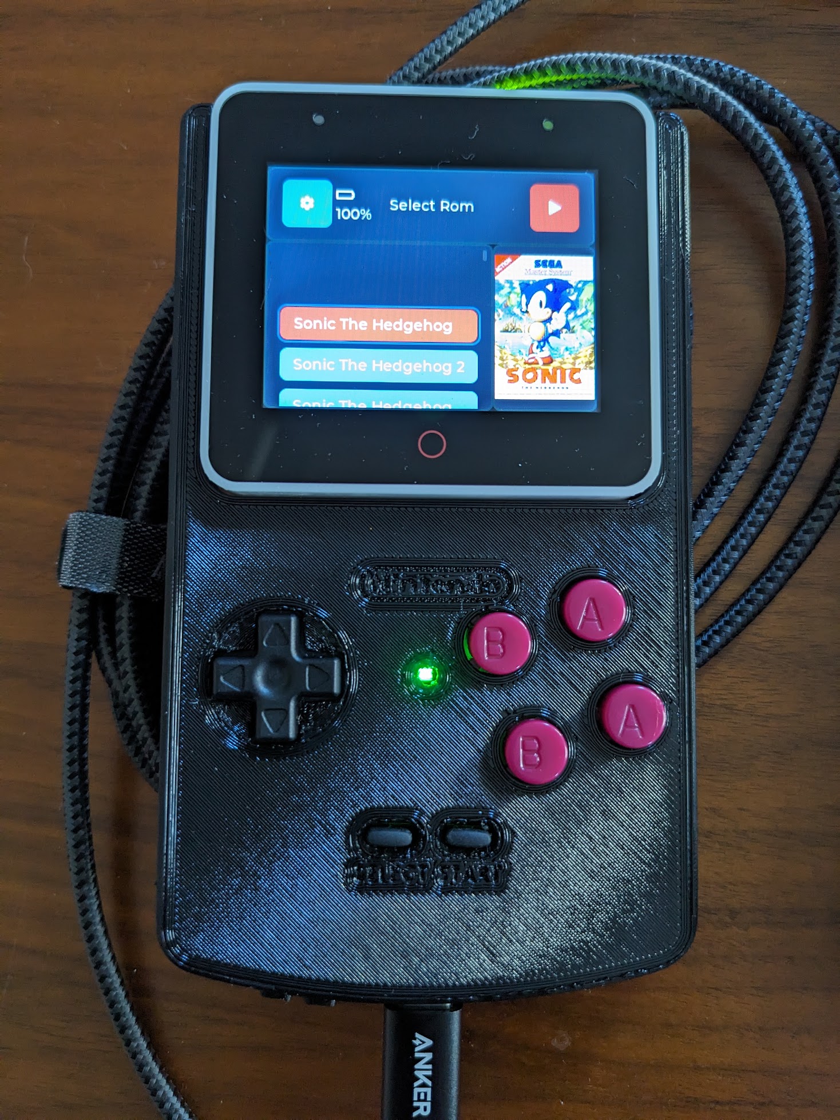
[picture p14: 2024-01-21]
images/electronics-2.jpg

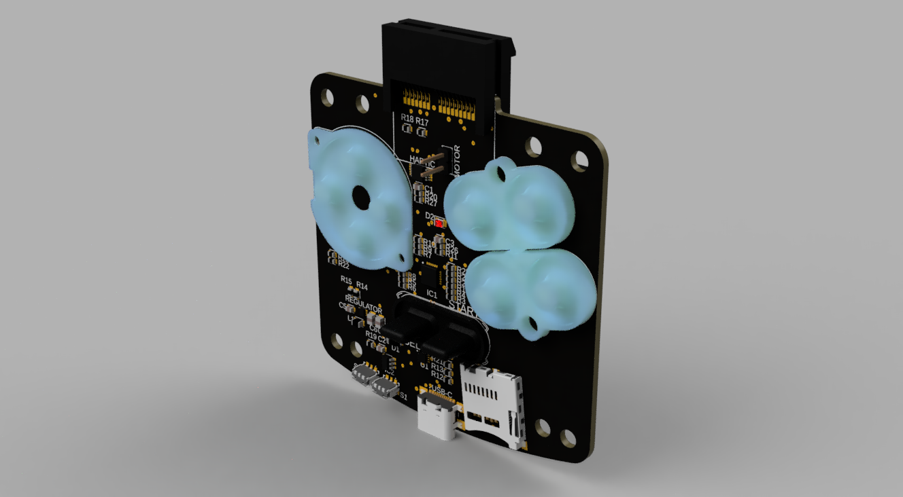
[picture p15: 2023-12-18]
images/Electronics_Design_for_BOX_2023-Dec-17_08-39-33PM-000_CustomizedView18198426044.png

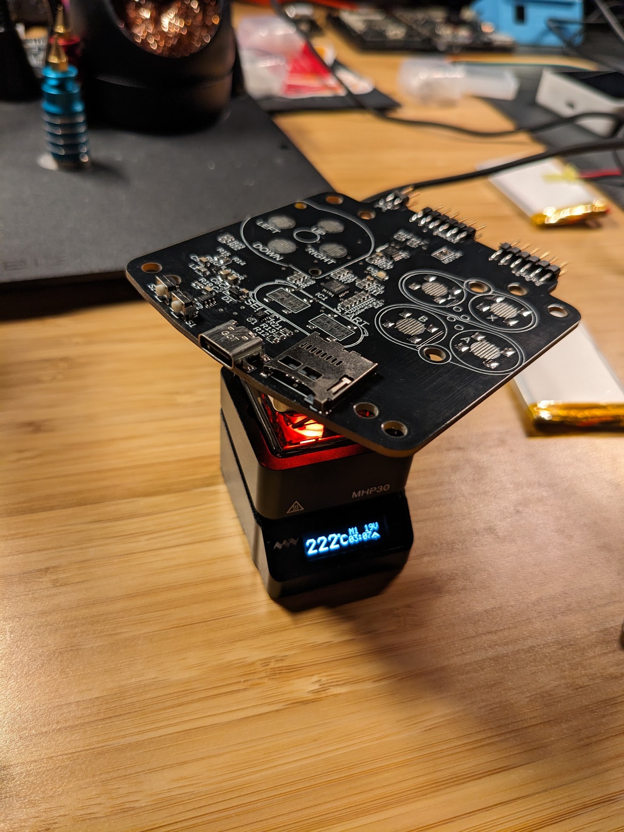
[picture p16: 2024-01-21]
images/electronics-3-reflow-max17048.jpg

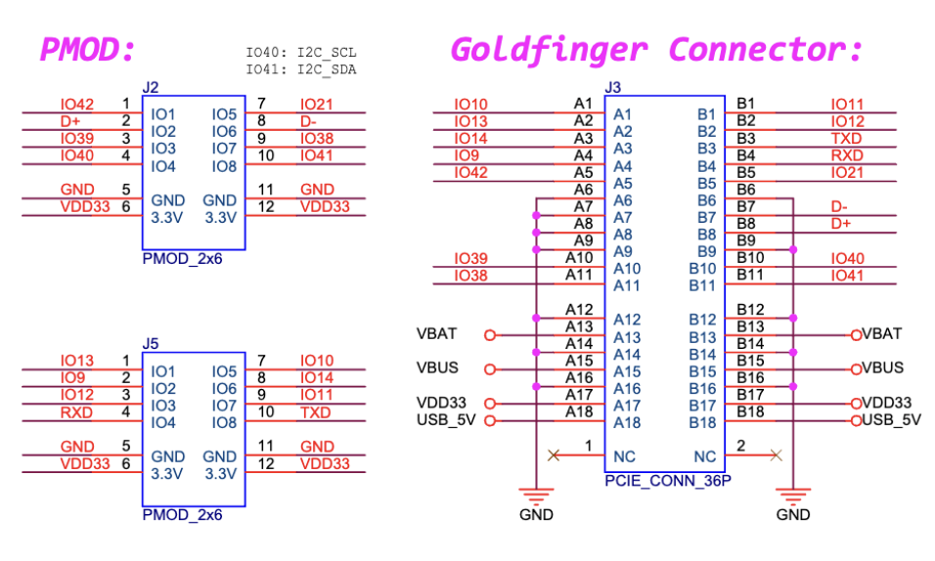
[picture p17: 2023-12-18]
images/esp32-s3-box-3-dock-connector-pinout.png

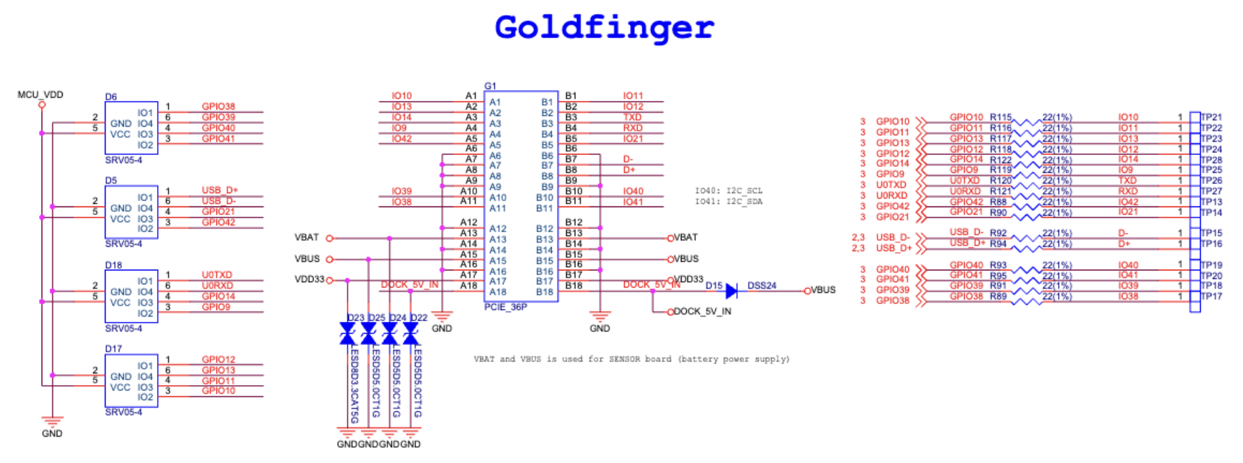
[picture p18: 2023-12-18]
images/esp32-s3-box-3-mb-connector-pinout.png

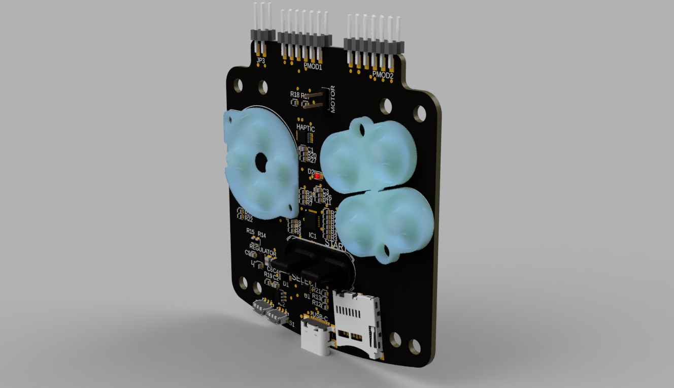
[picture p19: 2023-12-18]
images/Electronics_Design_for_BOX-3_2023-Dec-17_08-43-23PM-000_CustomizedView34032089160.png

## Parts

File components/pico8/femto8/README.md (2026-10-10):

# femto8

femto8 is an open-source reimplementation of the [PICO-8](https://www.lexaloffle.com/pico-8.php) fantasy console, designed specifically for embedded systems with smaller CPUs and less memory. It provides a platform to play PICO-8 games on devices with resource constraints, making it ideal for environments with limited hardware capabilities.

## Acknowledgment

This project has been significantly influenced by the work of [Jacopo Santoni](https://github.com/Jakz) on [retro8](https://github.com/Jakz/retro8), a PICO-8 emulator designed for desktop platforms. We would like to express our gratitude to Jacopo Santoni for his contributions and efforts on retro8, which has been an invaluable resource for the development of femto8.

## Key Features

- Written in C for optimal performance on embedded systems.
- Compact and resource-efficient design, suitable for devices with smaller CPUs and limited memory.

## Screenshots







## Building

To build femto8 (desktop):

1. Clone the repository: `git clone https://github.com/benbaker76/femto8.git`
2. Navigate to the femto8 directory: `cd femto8`
3. Install SDL2 development files for your platform:
	- Debian/Ubuntu: `sudo apt install libsdl2-dev pkg-config`
	- Fedora: `sudo dnf install SDL2-devel pkgconfig`
	- macOS (Homebrew): `brew install sdl2 pkg-config`
	- MSYS2 (Windows): install `mingw-w64-*-SDL2` and `pkgconf` via pacman
4. Build a local binary: `make`

## Credits

- [benbaker76](https://github.com/benbaker76) - Author and maintainer of [femto8](https://github.com/benbaker76/femto8)
- [Jacopo Santoni](https://github.com/Jakz) - Author of [retro8](https://github.com/Jakz/retro8)
- [Lexaloffle](https://www.lexaloffle.com/) - Creator of PICO-8
- [atomice1](https://github.com/atomice1) - For updates and improvements

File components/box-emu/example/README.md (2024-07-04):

# Box-Emu Example

This example shows how to use the `BoxEmu` component to initialize the hardware
for the BoxEmu, automatically detecting the version of the BoxEmu hardware and
initializing the appropriate hardware (sdcard, memory, gamepad, battery, video).
It uses the `espp::EspBox` component to similarly automatically detect the
version of the EspBox it is running on and intialize its hardware (display,
touch, audio) appropriately.

## How to use example

### Hardware Required

This example is designed to run on the ESP32-S3-BOX or ESP32-S3-BOX-3 in
conjunction with a BoxEmu V0 or BoxEmu V1 gamepad.

Note: Only BoxEmu V1 supports ESP32-S3-BOX-3 (referred to as EspBox-3 here).

### Build and Flash

Build the project and flash it to the board, then run monitor tool to view
serial output:

```
idf.py -p PORT flash monitor
```

(Replace PORT with the name of the serial port to use.)

(To exit the serial monitor, type ``Ctrl-]``.)

See the Getting Started Guide for full steps to configure and use ESP-IDF to build projects.

## Example Output

EspBox-3 BoxEmu V1:
CleanShot 2024-07-03 at 08 07 46

EspBox BoxEmu V1:
CleanShot 2024-07-03 at 08 10 53

EspBox BoxEmu V0:
CleanShot 2024-07-03 at 08 23 05

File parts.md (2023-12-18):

# Parts

These are the parts / sources I'm using for stock / replacement GBC membranes
and buttons.

- [Silicone pads for gameboy color (1)](https://funnyplaying.com/collections/product/products/gbc-replacement-silicone-pads)
- [Silicone pads for gameboy color (2)](https://www.retromodding.com/products/game-boy-color-silicone-pads)
- [Gameboy Color Button Plastics](https://funnyplaying.com/collections/product/products/cgb-custom-buttons?variant=39333911920701)

I found these parts (and others) on this excellent resource:
[List of places to get buttons and membranes
(consolemods.org)](https://consolemods.org/wiki/Game_Boy:Buttons_and_Membranes#GameBoy_Color_(CGB-001))

I Explored using Joycon buttons / membranes, but they are unfortunately too
short to match well with the height of the ESP32-S3-BOX and BOX-3:

- [Joycon ABXY Button switches](https://www.aliexpress.us/item/4001296524057.html)
- [Joycon R silicone membranes](https://handheldlegend.com/products/nintendo-switch-silicone-membranes-right-joy-con)

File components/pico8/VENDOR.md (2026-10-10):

# Vendored sources

`femto8/` is **femto8**, Ben Baker's PICO-8 reimplementation for embedded
systems (C, a fixed-point Lua 5.x fork, lodepng for `.p8.png` carts and the
Lexaloffle `.p8.png` code decompressor).

- Upstream: https://github.com/benbaker76/femto8 (MIT, `femto8/LICENSE`)
- Commit: `f9e5097c882d0c9203616689f3de5531e0597c43`
- Bundled: `src/lua` (Lua, MIT), `src/lodepng` (zlib, `lodepng/LICENSE`),
  `src/lexaloffle` (Lexaloffle Games, zlib-style notice in the files)

Everything under `femto8/src/` except `main.c` (the desktop/SDL entry point).

## Changes made for esp-box-emu

A third platform, `FEMTO8_ESPBOX`, next to upstream's SDL and Renesas
DA1470x (`__DA1470x__`) targets. The emulator supplies video, audio and input
through `src/platform/p8_espbox.h`, implemented in `src/pico8.cpp`:

- `p8_emu.h`: `FEMTO8_ESPBOX` selects `OS_FREERTOS` (FreeRTOS clock/sleep)
  and `ENABLE_AUDIO`; the DA1470x heap redirection no longer applies to every
  FreeRTOS target.
- `p8_emu.c`: FreeRTOS headers from `freertos/`; the generic renderer (the one
  the SDL build uses, with the screen transforms and high-colour modes) also
  serves the box, writing 5-bit palette indices into a frame the emulator
  provides (`p8_espbox_frame_begin/end`) instead of ARGB pixels; no on-screen
  fps counter; the LCD controller and DA1470x renderer are guarded.
- `p8_input.c`: buttons come from `p8_espbox_buttons()`; `p8_pump_events()`
  (femto8's Lua instruction hook) calls `p8_espbox_pump()`, where the emulator
  menu pauses the cart and a quit from the menu unwinds it through `p8_quit()`.
- `linker.lf`: femto8's statics go to PSRAM and are bracketed by SURROUND
  symbols so `src/pico8.cpp` can reset them between launches (femto8 was
  written to run once per process).
- `CARTDATA_PATH` / `DEFAULT_CARTS_PATH` are set to `/sdcard/pico8/...` at
  build time.
- PICO-8 compatibility (also fixed in the desktop build, which is the
  reference used to verify them): a cart that overrides `_ENV`
  (`for _ENV in all(objs) do circfill(...) end`, `function f(_ENV)`) still
  reaches the API through a fallback in `lua/lvm.c` (the same approach as
  fake-08's z8lua); `split()` accepts a non-string; `load("#bbs_id")`
  resolves to a sibling `bbs_id.p8.png` / `.p8` so multi-cart games work when
  their carts sit next to each other; `load()` resolves against the cart's
  own folder (no working directory on the ESP-IDF VFS); `p8_wait_for_any_key`
  accepts a gamepad button.
- Performance (`p8_lua_helper.h`): `sspr()` only walks the destination pixels
  inside the clip rectangle (a cart scaling a sprite to thousands of pixels
  looked hung); `circfill`/`ovalfill` draw each scanline once; `draw_hline`
  writes screen nibbles directly in the common case; `cls` is a memset. All
  verified pixel-identical against the previous code with a test cart.
- `p8_lua.c`: the Lua state uses the pooled allocator in
  `src/platform/p8_lua_alloc.c` (small objects from internal SRAM first, then
  PSRAM); `lvm`/`ltable`/`lstring` run from IRAM (`linker.lf`); a
  `PICO8_PROFILE` build wraps every API function with a cycle counter.

## Status and limits

Measured on the BOX-3: the interpreter executes ~1.3M Lua instructions/s
with its heap in PSRAM (GC ~1%, the drawing API ~5-15% of a frame), which
runs Celeste at its full 30 fps but leaves CPU-heavy carts near PICO-8's
limit (e.g. Cattle Crisis, Mossmoss) at a few fps. Known: Pico Ball shows a
blank screen in upstream femto8 as well; no mouse/keyboard.

## Save states

`src/platform/p8_state.c`: PICO-8 RAM, the overlay, the frame counters, the
audio channels and the cart's Lua heap. The heap is serialized with **Eris**
(`femto8/src/lua/eris.c`, MIT, Florian Nuecke; the Lua 5.2.4 version as
carried in fake-08's z8lua, with the fixed-point number I/O and the
`populateperms` helper for this Lua). Everything the cart created or
replaced in `_G` is persisted as a graph; the API functions and library
tables recorded before the cart ran (`p8_state_init`) are permanents
referenced by name, as are the registry, `_G` and the main thread. The
menu's request is carried out by the cart task at its next frame boundary
(`p8_espbox_frame_boundary()` in `p8_main_loop`), where no cart code is on
the Lua stack; the cart's own `cartdata()` file is untouched.

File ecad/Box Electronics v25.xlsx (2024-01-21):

Qty | Value | Device | Package | Parts | Description | Purchase Link | Alternate Part Number (PCBWay Preferred)
3 | .1uF | C_CHIP-0603(1608-METRIC) | CAPC1608X85 | C1, C3, C7 | Capacitor - Generic | https://www.mouser.com/ProductDetail/KYOCERA-AVX/06035C104KAT2A | 06035C104KAT2A
1 | 100k | R-US_CHIP-0603(1608-METRIC) | RESC1608X60 | R15 | Resistor Fixed - ANSI | https://www.mouser.com/ProductDetail/279-CRG0603F100K | CRG0603F100K
18 | 10k | R-US_CHIP-0603(1608-METRIC) | RESC1608X60 | R1, R2, R3, R4, R5, R6, R7, R8, R9, R10, R11, R20, R21, R22, R23, R24, R25, R26 | Resistor Fixed - ANSI | https://www.mouser.com/ProductDetail/603-RC0603FR-0710KL | RC0603FR-0710KL
2 | 10uF | C_CHIP-0603(1608-METRIC) | CAPC1608X85 | C2, C5 | Capacitor - Generic | https://www.mouser.com/ProductDetail/KYOCERA-AVX/06036D106MAT2A?qs=SnLCPPi%2FUkQWQ97wPZ%2F8XA%3D%3D | 06036D106MAT2A
2 | 1k | R-US_CHIP-0603(1608-METRIC) | RESC1608X60 | R17, R18 | Resistor Fixed - ANSI | https://www.mouser.com/ProductDetail/652-CR0603FX-1001ELF | CR0603-FX-1001ELF
1 | 1uH | L_CHIP-0805(2012-METRIC) | INDC2009X120 | L1 | Inductor Fixed - Generic | https://www.mouser.com/ProductDetail/TDK/MLZ2012N1R0LT000?qs=%2FPzWLGNeQ%252Biv0k32PagunQ%3D%3D | CMI201209U1R0KT, $0.134/pcs
1 | 2.0k | R-US_CHIP-0603(1608-METRIC) | RESC1608X60 | R19 | Resistor Fixed - ANSI | https://www.mouser.com/ProductDetail/603-RC0603FR-072KL | RC0603FR-072KL
2 | 22uF | C_CHIP-0805(2012-METRIC) | CAPC2012X110 | C4, C6 | Capacitor - Generic | https://www.mouser.com/ProductDetail/81-GRMJN7R61C206ME5D | CL21A226MQQNNNF
3 | 5.1k | R-US_CHIP-0603(1608-METRIC) | RESC1608X60 | R12, R13, R27 | Resistor Fixed - ANSI | https://www.mouser.com/ProductDetail/71-CRCW0603J-5.1K-E3 | CRCW06035K10JNEA
1 | 629722000214 | 629722000214SMD | USB4110GFA | USB-C | WR-COM USB 2.0 Type C Plug Vertical SMT | https://www.mouser.com/ProductDetail/640-USB4110-GF-A | USB4110-GF-A
1 | 732k | R-US_CHIP-0603(1608-METRIC) | RESC1608X60 | R14 | Resistor Fixed - ANSI | https://www.mouser.com/ProductDetail/603-AC0603FR-07732KL | AC0603FR-07732KL
1 | AW9523BTQR | AW9523BTQR | QFN50P400X400X80-25N | IC1 | 16 MULTI-FUNCTION LED DRIVER AND GPIO CONTROLLER WITH I2C INTERFACE
1 | DRV2605L | DRV2605L | VSSOP-10 | HAPTIC | TI DRV2605 Haptic Motor Driver | https://www.mouser.com/ProductDetail/Texas-Instruments/DRV2605LDGST?qs=asCBFxFfL1TjvcNdZsR2BA%3D%3D | DRV2605LDGST
1 | JSTPH2 | JSTPH2 | JSTPH2 | BATT | JST-PH 2-Pin Receptacle | https://www.mouser.com/ProductDetail/Adafruit/1769?qs=GURawfaeGuBbgoGtf2XstA%3D%3D | DNP
1 | LED_RED | CHIP-FLAT-R_0805 | LEDC2012X110N_FLAT-R | D2 | RED LED SMD | https://www.mouser.com/ProductDetail/Wurth-Elektronik/150080GS75000?qs=2kOmHSv6VfQRoTEZVk1mGA%3D%3D | 150080GS75000
1 | MAX17048G+T1021-0168E_T822-3_MXM | MAX17048G+T1021-0168E_T822-3_MXM | 21-0168E_T822-3_MXM | U1 | Battery Management 3 A 1-Cell/2-Cell Fuel Gauge with ModelGauge | https://www.mouser.com/ProductDetail/Analog-Devices-Maxim-Integrated/MAX17048G%2bT10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
1 | MBR0520LT1G | SCHOTTKY_MBR0520LT1GDO-219 | SODFL3718X115 | D1 | Schottky Diode - Popular parts | https://www.mouser.com/ProductDetail/833-MBR0520-TP
1 | MCP73831/OT | MCP73831/OT | SOT23-5L | IC2 | MCP73831/2 | https://www.mouser.com/ProductDetail/Microchip-Technology/MCP73831T-2ACI-OT?qs=yUQqVecv4qvbBQBGbHx0Mw%3D%3D | MCP73831T-2ACI/OT
1 | MICRO-SD_CARD_SOCKET | MICRO-SD_CARD_SOCKET | MICRO-SD-SOCKET | J2 | microSD Socket for Transflash | https://www.mouser.com/ProductDetail/GCT/MEM2051-00-195-00-A?qs=KUoIvG%2F9Ilat7yfJRNWXUQ%3D%3D | MEM2051-00-195-00-A
1 | PINHD-2X2REVERSED | PINHD-2X2REVERSED | 2X02/EDGE_REVERSED | JP3 | PIN HEADER | https://www.mouser.com/ProductDetail/Amphenol-FCI/77313-118-04LF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
2 | PINHD-2X6REVERSED | PINHD-2X6REVERSED | 2X06/EDGE_REVERSED | PMOD1, PMOD2 | PIN HEADER | https://www.mouser.com/ProductDetail/Amphenol-FCI/67997-212HLF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
2 | TL3340AF160QG | TL3340AF160QG | TL3340 | S1, S2 | E-SWITCH - TL3340AF160QG. - SWITCH, TACTILE SPST 50mA, SMD GULL WING | https://www.mouser.co.uk/ProductDetail/E-Switch/TL3340AF160QG?qs=Cv1v43EOJpo402rrfE5MlQ%3D%3D
1 | TPS61070 | TPS61023 | SOT563 | REGULATOR | Synchronous Boost Converter With 600-mA Switch | https://www.mouser.com/ProductDetail/595-TPS61023DRLT | TPS61023DRLR

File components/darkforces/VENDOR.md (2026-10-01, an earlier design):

# Vendored sources

`tfe/` is a subset of **The Force Engine** (TFE), taken from BSzili's Amiga port
branch, which had already stripped the desktop-only subsystems (OpenGL, SDL,
ImGui front end, editor, mods) and added low-spec code paths.

- Upstream: https://github.com/luciusDXL/TheForceEngine (GPL-2.0)
- Branch used: https://github.com/BSzili/TheForceEngine/tree/amiga
- Commit: `d116b7a9efc29e8c9223db19d5e5ad743c8f8372` (based on TFE v1.09.410)

The file list mirrors `Makefile.amiga` from that branch (minus the Amiga
platform files under `amiga/`). Changes made for the ESP32 port:

- `__AMIGA__` platform guards were renamed to `TFE_ESPBOX` (defined by the
  component's CMakeLists).
- `TFE_System/system.cpp` and `TFE_System/log.cpp` were rewritten for
  `esp_timer` / serial logging.
- `TFE_Jedi/Renderer/virtualFramebuffer.cpp`: the 320x200 8-bit framebuffer is
  supplied by the platform (`vfb_setPlatformBuffer()`).
- `TFE_Audio/*`: MIDI devices render 16-bit integer samples (`MidiSample`),
  `midiPlayer.cpp` sleeps between iMuse updates, and the AHI left/right channel
  swap in `imDigitalSound.cpp` was removed.
- `TFE_Jedi/Task/task.cpp`: smaller task context stacks (8KB x 16 per chunk).
- `TFE_FileSystem/fileutil-posix.cpp`: no cwd / executable directory.
- `TFE_Game/saveSystem.h`: save thumbnails disabled (4x4).
- `TFE_DarkForces/darkForcesMain.cpp`: state reset restored in `exitGame()`.
- Loaders (`level.cpp`, `rtexture.cpp`, `infSystem.cpp`, `spriteAsset_Jedi.cpp`,
  `modelAsset_jedi.cpp`, `vueAsset.cpp`): `espbox_free_*_scratch()` hooks release
  the static read buffers at shutdown.
- `TFE_Asset/modelAsset_jedi.cpp`: no GPU drawId free after the level region is cleared.
- `TFE_Game/saveSystem.cpp`: absolute save paths; buffers nulled on shutdown.
- `TFE_Jedi/Renderer/RClassic_Fixed/rclassicFixedSharedState.*`: the state is a
  platform allocated pointer instead of a 320KB static.
- Large statics (stream/parser/settings/save buffers, OPL3 chip, MIDI buffers,
  palettes, ...) are pointers allocated from BoxEmu's 4MB ROM block through
  per-file `espbox_shared_*()` hooks (`TFE_System/espboxShared.h`).
- Shutdown-only `espbox_release_*_caches()` hooks (settings, paths, MIDI player,
  renderer, 3D object, texture, sprite and model caches) release static STL
  container storage so nothing is left in the ROM block between sessions.
- `TFE_DarkForces/sound.cpp`: level sounds are registered at startup but read
  from the card the first time they play (`vocFileExists()` in `lsound.cpp`).
- `TFE_DarkForces/GameUI/escapeMenu.cpp`: the escape / confirmation menu frames
  are loaded when the menu opens and freed when it closes.
- `TFE_Archive/gobArchive.cpp`: directory reads are validated.
- `TFE_Audio/MidiSynth/opl3.c`: lookup tables placed in internal RAM (`DRAM_ATTR`).
- `TFE_System/parser.cpp`: `initFromFile()` parses through a 64KB sliding window
  of an open file (`FileStream::reselect()` makes the stream's archive entry
  current again before each refill); the level, objects, goals and INF loaders
  use it instead of reading the whole file into memory.
- `TFE_DarkForces/Landru/cutscene_player.cpp`: a scene's sounds are released
  when it ends (not only when skipped); `cutscenePlayer_abort()` stops a running
  sequence when a game is loaded.
- `TFE_DarkForces/GameUI/escapeMenu.cpp`: the confirmation frames load on demand
  and all frames are released whenever the menu closes.

All allocations made by this library go to the 4MB ROM block while the game
runs: see `../src/platform/esp_alloc.cpp` and `../alloc_redirect.syms`.

`SDL_endian.h` is the Amiga branch's little-endian shim for `TFE_System/endian.h`.

The ESP32 platform implementations live in `../src/platform/`.

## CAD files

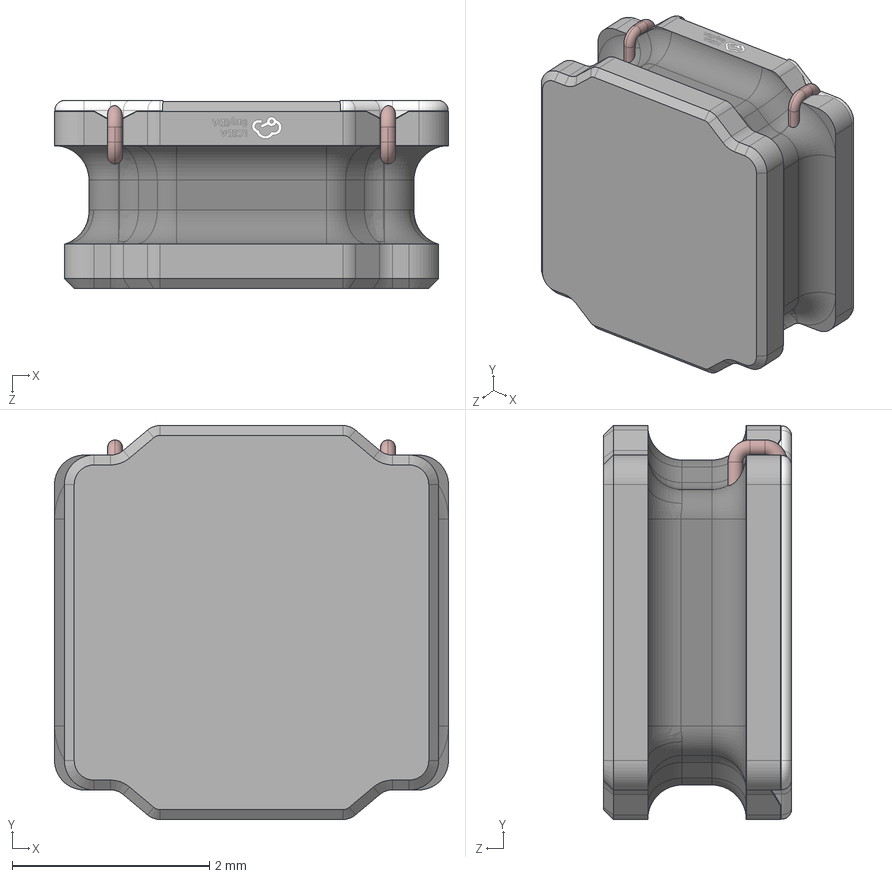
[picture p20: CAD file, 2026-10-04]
ecad/.ato/modules/atopile/ti-tps63020/parts/cjiang_FHD4020S_1R0MT/IND-SMD_L4.0-W4.0-H1.9.STEP
4.00 x 4.00 x 1.91 mm

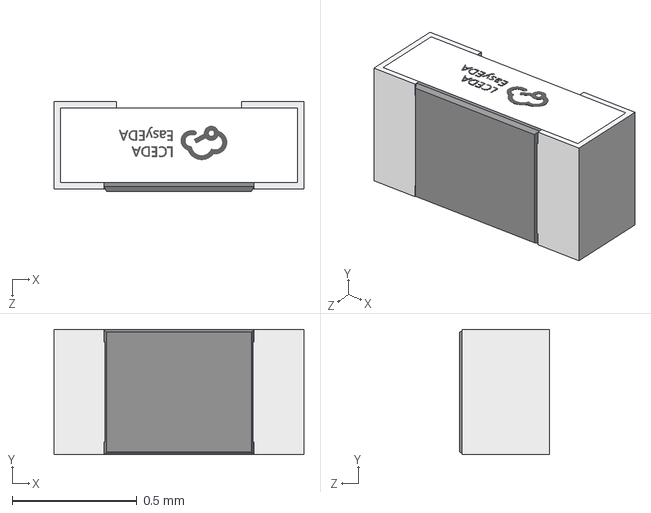
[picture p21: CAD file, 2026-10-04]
ecad/.ato/modules/atopile/ti-tps63020/parts/FOJAN_FRC0402F1023TS/R0402_L1.0-W0.5-H0.4.step
1.00 x 0.501 x 0.36 mm

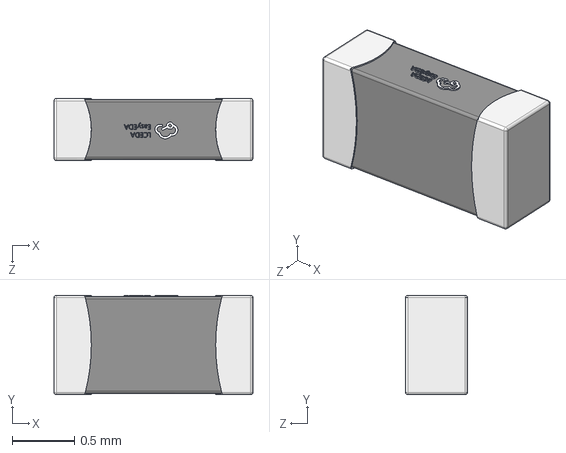
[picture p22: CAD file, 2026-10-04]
ecad/.ato/modules/atopile/ti-tps63020/parts/Murata_Electronics_LQM18FN100M00D/L0603_L1.6-W0.8-H0.5_BEAD.step
1.60 x 0.8 x 0.5 mm

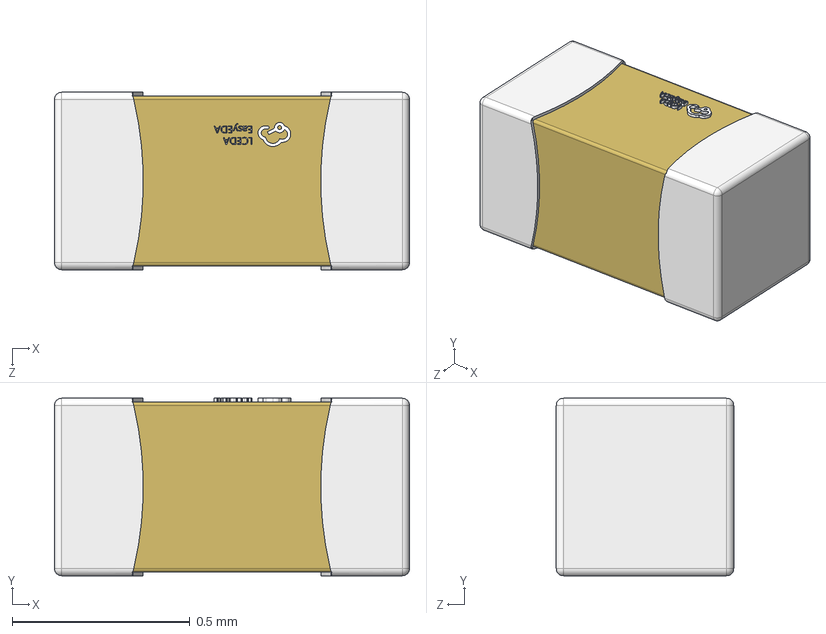
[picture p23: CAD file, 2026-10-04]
ecad/.ato/modules/atopile/ti-tps63020/parts/Samsung_Electro_Mechanics_CL05B104KO5NNNC/C0402_L1.0-W0.5-H0.5.step
1.00 x 0.5 x 0.5 mm

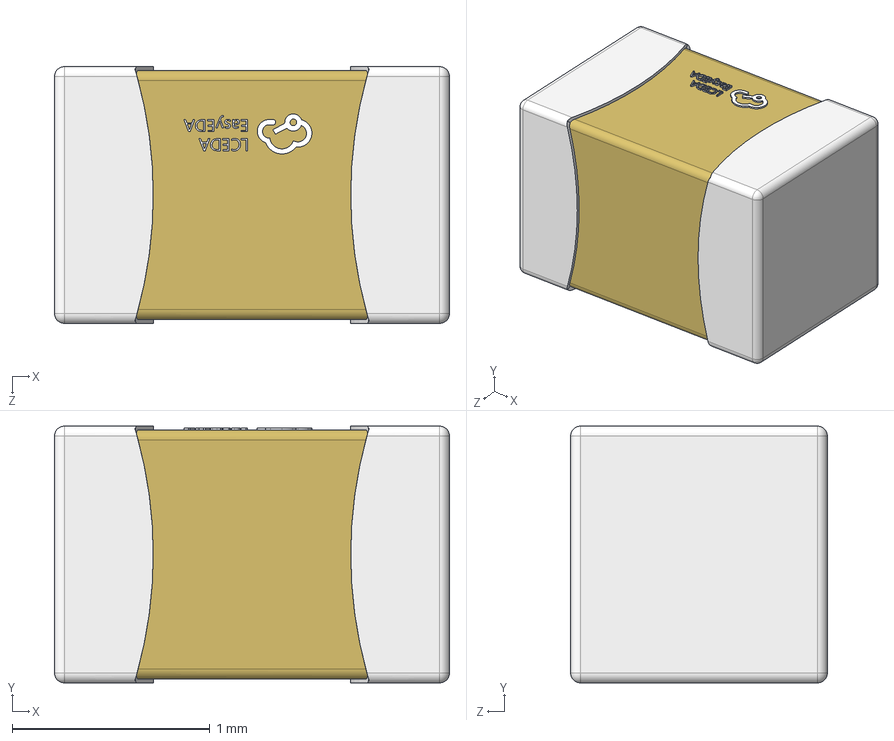
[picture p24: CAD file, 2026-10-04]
ecad/.ato/modules/atopile/ti-tps63020/parts/Samsung_Electro_Mechanics_CL21A106KAYNNNE/C0805_L2.0-W1.3-H1.3.step
2.00 x 1.30 x 1.30 mm

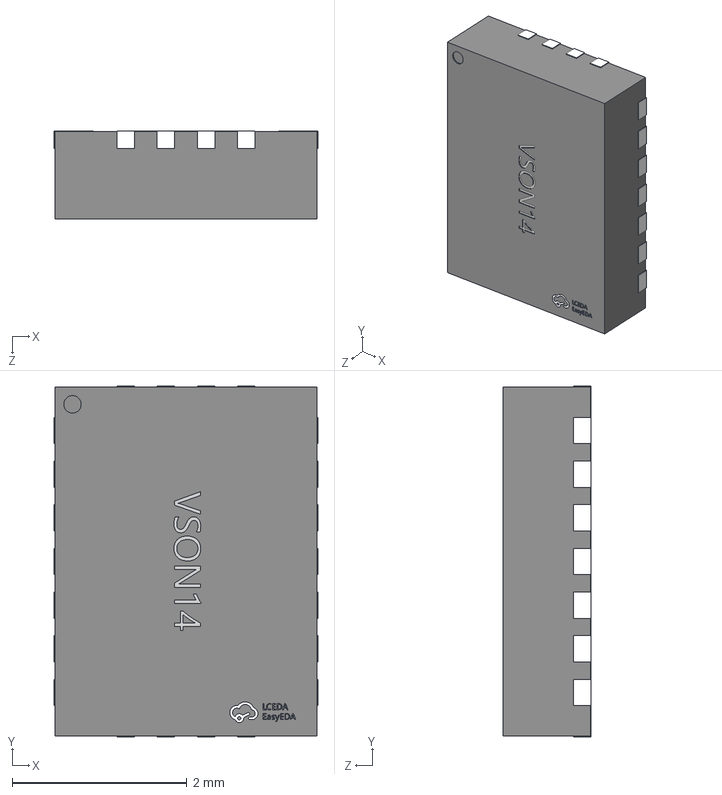
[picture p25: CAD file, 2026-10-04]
ecad/.ato/modules/atopile/ti-tps63020/parts/Texas_Instruments_TPS63020DSJR/VSON-14_L4.0-W3.0-H1.0-P0.50.step
3.02 x 4.02 x 1.01 mm

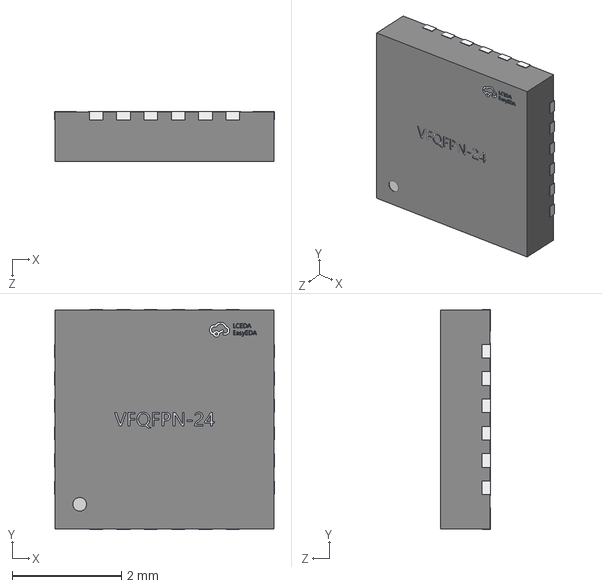
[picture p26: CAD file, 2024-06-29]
ecad/elec/src/parts/AWINIC_AW9523BTQR/VFQFPN-24_L4.0-W4.0-H0.9-P0.50.step
4.02 x 4.02 x 0.911 mm

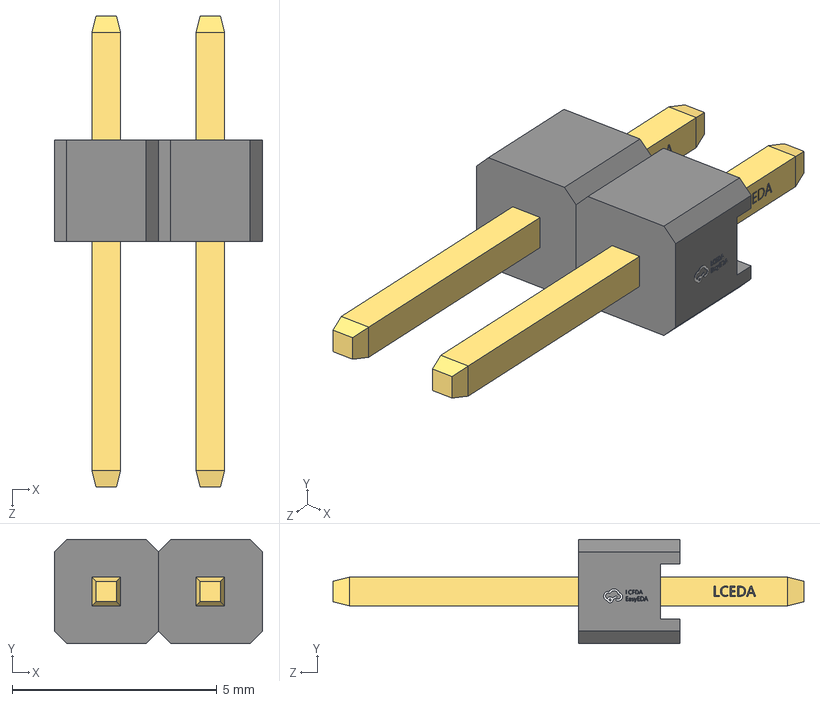
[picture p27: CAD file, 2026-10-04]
ecad/elec/src/parts/Ckmtw_B_2100S02P_A110/HDR-M-2.54_1X2.step
5.09 x 2.54 x 11.5 mm

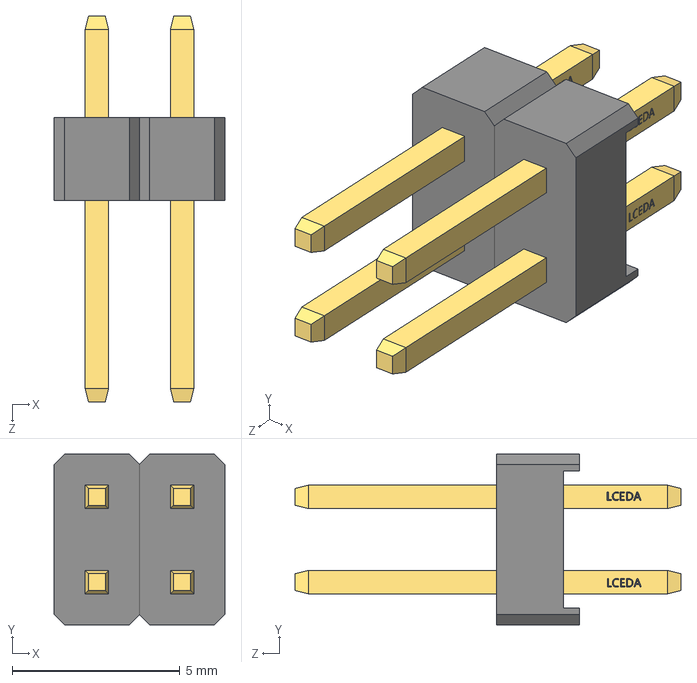
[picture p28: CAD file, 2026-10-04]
ecad/elec/src/parts/DEALON_DZ254R_22_04_63/HDR2.54-M-LI-2x2P.step
5.08 x 5.08 x 11.5 mm

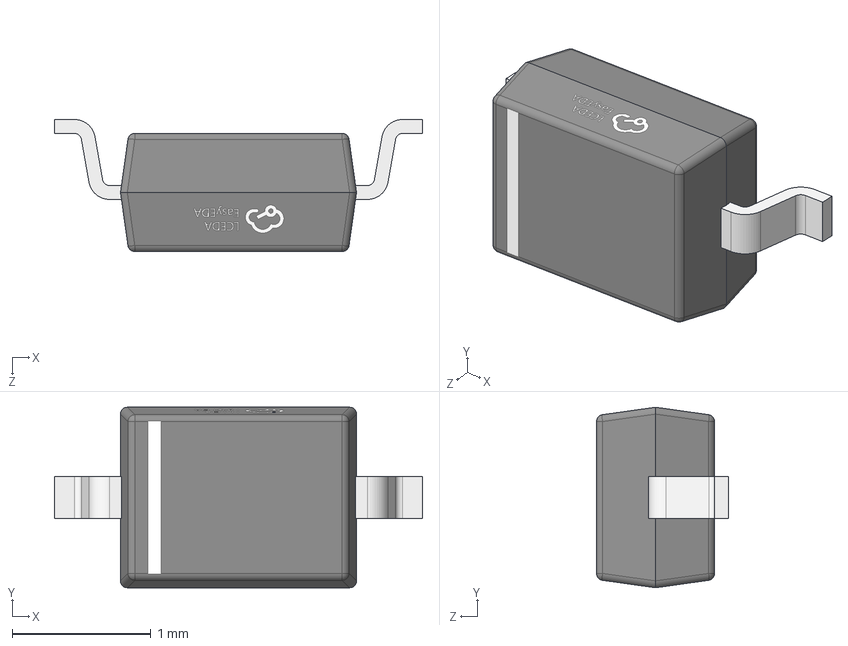
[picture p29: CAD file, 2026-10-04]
ecad/elec/src/parts/Guangdong_Hottech_1N5819WS/2.STEP
2.65 x 1.30 x 0.95 mm

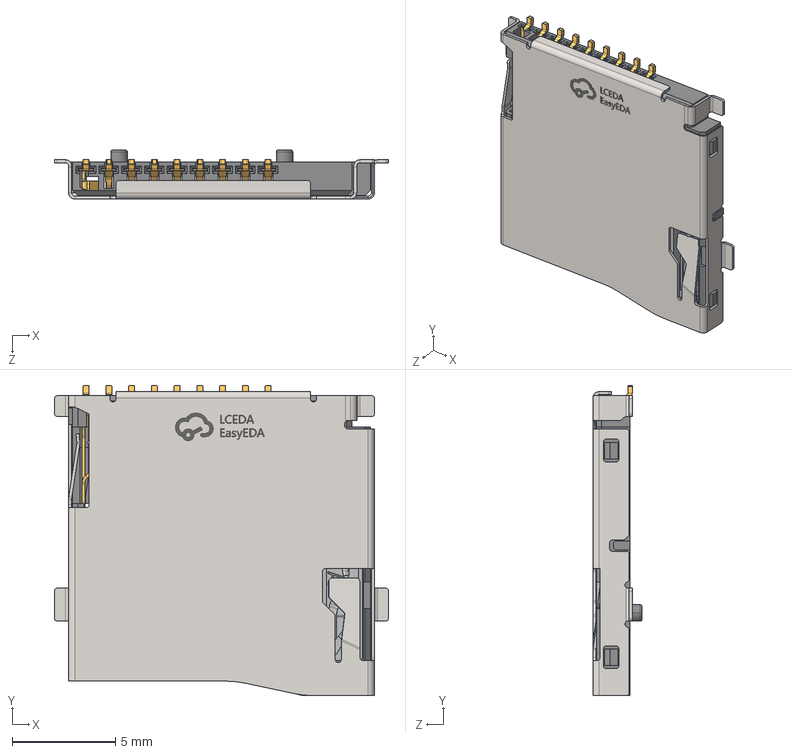
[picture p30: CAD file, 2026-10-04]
ecad/elec/src/parts/HOAUC_HYCW118_TF09_200B/SIM-SMD_C9900007362.STEP
16.2 x 15.0 x 2.39 mm

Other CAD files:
ecad/elec/src/parts/FOJAN_FRC0402F8203TS/R0402_L1.0-W0.5-H0.4.step
ecad/elec/src/parts/JST_Sales_America_S2B_PH_SM4_TB_LF__SN/CONN-SMD_P2.00_S2B-PH-SM4-TB-LF-SN.step
ecad/elec/src/parts/JST_Sales_America_SM04B_SRSS_TB_LF__SN/CONN-SMD_SR1.00-WS-4P.step
ecad/elec/src/parts/Maxim_Integrated_MAX17048G_T10/TDFN-8_L2.0-W2.0-P0.50-BL-EP1.2.STEP
ecad/elec/src/parts/Microchip_Tech_MCP73831T_2ACI_OT/SOT-23-5_L2.9-W1.6-H1.1-LS2.8-P0.95.step
ecad/elec/src/parts/SHOU_HAN_TS24CA/SW-SMD_2P-TS24CA.STEP
ecad/elec/src/parts/Samsung_Electro_Mechanics_CL05A105KA5NQNC/C0402_L1.0-W0.5-H0.5.step
ecad/elec/src/parts/Samsung_Electro_Mechanics_CL05A475KP5NRNC/C0402_L1.0-W0.5-H0.5.step
ecad/elec/src/parts/Samsung_Electro_Mechanics_CL05B104KO5NNNC/C0402_L1.0-W0.5-H0.5.step
ecad/elec/src/parts/Samsung_Electro_Mechanics_CL21A106KAYNNNE/C0805_L2.0-W1.3-H1.3.step
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

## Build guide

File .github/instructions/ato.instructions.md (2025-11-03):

---
description: ato is a declarative DSL to design electronics (PCBs) with.
applyTo: *.ato, ato.yaml
---

ato is a declarative DSL to design electronics (PCBs) with.
It is part of the atopile project.
Atopile is run by the vscode/cursor/windsurf extension.
The CLI (which is invoked by the extension) actually builds the project.

# Not available in ato

- if statements
- while loops
- functions (calls or definitions)
- classes
- objects
- exceptions
- generators

# Ato Syntax

ato sytax is heavily inspired by Python, but fully declarative.
ato thus has no procedural code, and no side effects.

## Examples of syntax

```ato
#pragma text
#pragma func("X")
# enable for loop syntax feature:
#pragma experiment("FOR_LOOP)

# --- Imports ---
# Standard import (newline terminated)
import ModuleName

# Import with multiple modules (newline terminated)
import Module1, Module2.Submodule

# Import from a specific file/source (newline terminated)
from "path/to/source.ato" import SpecificModule

# Multiple imports on one line (semicolon separated)
import AnotherModule; from "another/source.ato" import AnotherSpecific

# Deprecated import form (newline terminated)
# TODO: remove when unsupported
import DeprecatedModule from "other/source.ato"

# --- Top-level Definitions and Statements ---

pass
pass;

"docstring-like statement"
"docstring-like statement";

top_level_var = 123

# Compound statement
pass; another_var = 456; "another docstring"

# Block definitions
component MyComponent:
    # Simple statement inside block (newline terminated)
    pass

    # Multiple simple statements on one line (semicolon separated)
    pass; internal_flag = True

module AnotherBaseModule:
    pin base_pin
    base_param = 10

interface MyInterface:
    pin io

module DemoModule from AnotherBaseModule:
    # --- Declarations ---
    pin p1              # Pin declaration with name
    pin 1               # Pin declaration with number
    pin "GND"           # Pin declaration with string
    signal my_signal    # Signal definition
    a_field: AnotherBaseModule      # Field declaration with type hint

    # --- Assignments ---
    # Newline terminated:
    internal_variable = 123

    # Semicolon separated on one line:
    var_a = 1; var_b = "string"

    # Cumulative assignment (+=, -=) - Newline terminated
    value = 1
    value += 1; value -= 1

    # Set assignment (|=, &=) - Newline terminated
    flags |= 1; flags &= 2

    # --- Connections ---
    p1 ~ base_pin
    mif ~> bridge
    mif ~> bridge ~> bridge
    mif ~> bridge ~> bridge ~> mif
    bridge ~> mif
    mif <~ bridge
    mif <~ bridge <~ bridge
    mif <~ bridge <~ bridge <~ mif
    bridge <~ mif

    # Semicolon separated on one line:
    p_multi1 ~ my_signal; p_multi2 ~ sig_multi1

    # --- Retyping ---
    instance.x -> AnotherBaseModule

    # --- Instantiation ---
    instance = new MyComponent
    container = new MyComponent[10]
    templated_instance_a = new MyComponent
    templated_instance_b = new MyComponent<int_=1>
    templated_instance_c = new MyComponent<float_=2.5>
    templated_instance_d = new MyComponent<string_="hello">
    templated_instance_e = new MyComponent<int_=1, float_=2.5, string_="hello">
    templated_instance_f = new MyComponent<int_=1, float_=2.5, string_="hello", bool_=True>

    # Semicolon separated instantiations (via assignment):
    inst_a = new MyComponent; inst_b = new AnotherBaseModule

    # --- Traits ---
    trait trait_name
    trait trait_name<int_=1>
    trait trait_name<float_=2.5>
    trait trait_name<string_="hello">
    trait trait_name<bool_=True>
    trait trait_name::constructor
    trait trait_name::constructor<int_=1>

    # Semicolon separated on one line:
    trait TraitA; trait TraitB::constructor; trait TraitC<arg_=1>

    # --- Assertions ---
    assert x > 5V
    assert x < 10V
    assert 5V < x < 10V
    assert x >= 5V
    assert x <= 10V
    assert current within 1A +/- 10mA
    assert voltage within 1V +/- 10%
    assert resistance is 1kohm to 1.1kohm

    # Semicolon separated on one line:
    assert x is 1V; assert another_param is 2V

    # --- Loops ---
    for item in container:
        item ~ p1

    # For loop iterating over a slice
    for item in container[0:4]:
        pass
        item.value = 1; pass

    # For loop iterating over a list literal of field references
    for ref in [p1, x.1, x.GND]:
        pass

    # --- References and Indexing ---
    # Reference with array index assignment
    array_element = container[3]

    # --- Literals and Expressions ---
    # Integer
    int_val = 100
    neg_int_val = -50
    hex_val = 0xF1
    bin_val = 0b10
    oct_val = 0o10
    # Float
    float_val = 3.14
    # Physical quantities
    voltage: V = 5V
    resistance: ohm = 10kohm
    capacitance: F = 100nF
    # Bilateral tolerance
    tolerance_val = 1kohm +/- 10%
    tolerance_abs = 5V +/- 500mV
    tolerance_explicit_unit = 10A +/- 1A
    # Bounded quantity (range)
    voltage_range = 3V to 3.6V
    # Boolean
    is_enabled = True
    is_active = False
    # String
    message = "Hello inside module"

    # Arithmetic expressions
    sum_val = 1 + 2
    diff_val = 10 - 3ohm
    prod_val = 5 * 2mA
    div_val = 10V / 2kohm # Results in current
    power_val = 2**3
    complex_expr = (5 + 3) * 2 - 1
    flag_check = state | MASK_VALUE

    # Comparisons
    assert voltage within voltage_range
    assert length <= 5mm
    assert height >= 2mm

# --- Multi-line variations ---
pass; nested_var=1; another=2

complex_assignment = (
    voltage + resistance
    * capacitance
)

```

## G4 Grammar

```g4
parser grammar AtoParser;

options {
	superClass = AtoParserBase;
	tokenVocab = AtoLexer;
}

file_input: (NEWLINE | stmt)* EOF;

pragma_stmt: PRAGMA;

stmt: simple_stmts | compound_stmt | pragma_stmt;
simple_stmts:
	simple_stmt (SEMI_COLON simple_stmt)* SEMI_COLON? NEWLINE;
simple_stmt:
	import_stmt
	| dep_import_stmt
	| assign_stmt
	| cum_assign_stmt
	| set_assign_stmt
	| connect_stmt
	| directed_connect_stmt
	| retype_stmt
	| pin_declaration
	| signaldef_stmt
	| assert_stmt
	| declaration_stmt
	| string_stmt
	| pass_stmt
	| trait_stmt;

compound_stmt: blockdef | for_stmt;

blockdef: blocktype name blockdef_super? COLON block;
// TODO @v0.4 consider ()
blockdef_super: FROM type_reference;
// TODO @v0.4 consider removing component (or more explicit code-as-data)
blocktype: (COMPONENT | MODULE | INTERFACE);
block: simple_stmts | NEWLINE INDENT stmt+ DEDENT;

// TODO: @v0.4 remove the deprecated import form
dep_import_stmt: IMPORT type_reference FROM string;
import_stmt: (FROM string)? IMPORT type_reference (
		COMMA type_reference
	)*;

declaration_stmt: field_reference type_info;
field_reference_or_declaration:
	field_reference
	| declaration_stmt;
assign_stmt: field_reference_or_declaration '=' assignable;
cum_assign_stmt:
	field_reference_or_declaration cum_operator cum_assignable;
// TODO: consider sets cum operator
set_assign_stmt:
	field_reference_or_declaration (OR_ASSIGN | AND_ASSIGN) cum_assignable;
cum_operator: ADD_ASSIGN | SUB_ASSIGN;
cum_assignable: literal_physical | arithmetic_expression;

assignable:
	string
	| new_stmt
	| literal_physical
	| arithmetic_expression
	| boolean_;

retype_stmt: field_reference ARROW type_reference;

directed_connect_stmt
	: bridgeable ((SPERM | LSPERM) bridgeable)+; // only one type of SPERM per stmt allowed. both here for better error messages
connect_stmt: mif WIRE mif;
bridgeable: connectable;
mif: connectable;
connectable: field_reference | signaldef_stmt | pindef_stmt;

signaldef_stmt: SIGNAL name;
pindef_stmt: pin_stmt;
pin_declaration: pin_stmt;
pin_stmt: PIN (name | number_hint_natural | string);

new_stmt: NEW type_reference ('[' new_count ']')? template?;
new_count: number_hint_natural;

string_stmt:
	string; // the unbound string is a statement used to add doc-strings

pass_stmt:
	PASS; // the unbound string is a statement used to add doc-strings

list_literal_of_field_references:
	'[' (field_reference (COMMA field_reference)* COMMA?)? ']';

iterable_references:
	field_reference slice?
	| list_literal_of_field_references;

for_stmt: FOR name IN iterable_references COLON block;

assert_stmt: ASSERT comparison;

trait_stmt
	: TRAIT type_reference (DOUBLE_COLON constructor)? template?; // TODO: move namespacing to type_reference
constructor: name;
template: '<' (template_arg (COMMA template_arg)* COMMA?)? '>';
template_arg: name ASSIGN literal;

// Comparison operators --------------------
comparison: arithmetic_expression compare_op_pair+;

compare_op_pair:
	lt_arithmetic_or
	| gt_arithmetic_or
	| lt_eq_arithmetic_or
	| gt_eq_arithmetic_or
	| in_arithmetic_or
	| is_arithmetic_or;

lt_arithmetic_or: LESS_THAN arithmetic_expression;
gt_arithmetic_or: GREATER_THAN arithmetic_expression;
lt_eq_arithmetic_or: LT_EQ arithmetic_expression;
gt_eq_arithmetic_or: GT_EQ arithmetic_expression;
in_arithmetic_or: WITHIN arithmetic_expression;
is_arithmetic_or: IS arithmetic_expression;

// Arithmetic operators --------------------

arithmetic_expression:
	arithmetic_expression (OR_OP | AND_OP) sum
	| sum;

sum: sum (PLUS | MINUS) term | term;

term: term (STAR | DIV) power | power;

power: functional (POWER functional)?;

functional: bound | name '(' bound+ ')';

bound: atom;

// Primary elements ----------------

slice:
	'[' (slice_start? COLON slice_stop? (COLON slice_step?)?)? ']'
	// else [::step] wouldn't match
	| '[' ( DOUBLE_COLON slice_step?) ']';
slice_start: number_hint_integer;
slice_stop: number_hint_integer;
slice_step: number_hint_integer;

atom: field_reference | literal_physical | arithmetic_group;

arithmetic_group: '(' arithmetic_expression ')';

literal_physical:
	bound_quantity
	| bilateral_quantity
	| quantity;

bound_quantity: quantity TO quantity;
bilateral_quantity: quantity PLUS_OR_MINUS bilateral_tolerance;
quantity: number name?;
bilateral_tolerance: number_signless (PERCENT | name)?;

key: number_hint_integer;
array_index: '[' key ']';

// backwards compatibility for A.1
pin_reference_end: DOT number_hint_natural;
field_reference_part: name array_index?;
field_reference:
	field_reference_part (DOT field_reference_part)* pin_reference_end?;
type_reference: name (DOT name)*;
// TODO better unit
unit: name;
type_info: COLON unit;
name: NAME;

// Literals
literal: string | boolean_ | number;

string: STRING;
boolean_: TRUE | FALSE;
number_hint_natural: number_signless;
number_hint_integer: number;
number: (PLUS | MINUS)? number_signless;
number_signless: NUMBER;
```

# Most used library modules/interfaces (api of them)

```ato
interface Electrical:
    pass

interface ElectricPower:
    hv = new Electrical
    lv = new Electrical

module Resistor:
    resistance: ohm
    max_power: W
    max_voltage: V
    unnamed = new Electrical[2]

module Capacitor:
    capacitance: F
    max_voltage: V
    unnamed = new Electrical[2]

interface I2C:
    scl = new ElectricLogic
    sda = new ElectricLogic
    frequency: Hz
    address: dimensionless

interface ElectricLogic:
    line = new Electrical
    reference = new ElectricPower
```

For the rest use the atopile MCP server 
- `get_library_interfaces` to list interfaces
- `get_library_modules` to list modules
- `inspect_library_module_or_interface` to inspect the code

# Ato language features

## experimental features

Enable with `#pragma experiment("BRIDGE_CONNECT")`
BRIDGE_CONNECT: enables `p1 ~> resistor ~> p2` syntax
FOR_LOOP: enables `for item in container: pass` syntax
TRAITS: enables `trait trait_name` syntax
MODULE_TEMPLATING: enables `new MyComponent<param=literal>` syntax

## modules, interfaces, parameters, traits

A block is either a module, interface or component.
Components are just modules for code-as-data.
Interfaces describe a connectable interface (e.g Electrical, ElectricPower, I2C, etc).
A module is a block that can be instantiated.
Think of it as the ato equivalent of a class.
Parameters are variables for numbers and they work with constraints.
E.g `resistance: ohm` is a parameter.
Constrain with `assert resistance within 10kohm +/- 10%`.
It's very important to use toleranced values for parameters.
If you constrain a resistor.resistance to 10kohm there won't be a single part found because that's a tolerance of 0%.

Traits mark a module to have some kind of functionality that can be used in other modules.
E.g `trait has_designator_prefix` is the way to mark a module to have a specific designator prefix that will be used in the designator field in the footprint.

## connecting

You can only connect interfaces of the same type.
`resistor0.unnamed[0] ~ resistor0.unnamed[0]` is the way to connect two resistors in series.
If a module has the `can_bridge` trait you can use the sperm operator `~>` to bridge the module.
`led.anode ~> resistor ~> power.hv` connects the anode in series with the resistor and then the resistor in series with the high voltage power supply.

## for loop syntax

`for item in container: pass` is the way to iterate over a container.

# Ato CLI

## How to run

You run ato commands through the MCP tool.

## Packages

Packages can be found on the ato registry.
To install a package you need to run `ato add <PACKAGE_NAME>`.
e.g `ato install atopile/addressable-leds`
And then can be imported with `from "atopile/addressable-leds/sk6805-ec20.ato" import SK6805_EC20_driver`.
And used like this:

```ato
module MyModule:
    led = new SK6805_EC20_driver
```

## Footprints & Part picking

Footprint selection is done through the part choice (`ato create part` auto-generates ato code for the part).
The `pin` keyword is used to build footprint pinmaps so avoid using it outside of `component` blocks.
Preferrably use `Electrical` interface for electrical interfaces.
A lot of times it's actually `ElectricLogic` for things like GPIOs etc or `ElectricPower` for power supplies.

Passive modules (Resistors, Capacitors) are picked automatically by the constraints on their parameters.
To constrain the package do e.g `package = "0402"`.
To explictly pick a part for a module use `lcsc = "<LCSC_PART_NUMBER>"`.

# Creating a package

Package generation process:

Review structure of other pacakges.

1. Create new Directory in 'packages/packages' with naming convention '<vendor>-<device>' eg 'adi-adau145x'
2. create an ato.yaml file in the new directory with the following content:

```yaml
requires-atopile: '^0.9.0'

paths:
    src: '.'
    layout: ./layouts

builds:
    default:
        entry: <device>.ato:<device>_driver
    example:
        entry: <device>.ato:Example
```

3. Create part using tool call 'search_and_install_jlcpcb_part'
4. Import the part into the <device>.ato file
5. Read the datasheet for the device
6. Find common interfaces in the part eg I2C, I2S, SPI, Power

7. Create interfaces and connect them

power interfaces:
power*<name> = new ElectricPower
power*<name>.required = True # If critical to the device
assert power\*<name>.voltage within <minimum*operating_voltage>V to <maximum_operating_voltage>V
power*<name>.vcc ~ <device>.<vcc pin>
power\_<name>.gnd ~ <device>.<gnd pin>

i2c interfaces:
i2c = new I2C
i2c.scl.line ~ <device>.<i2c scl pin>
i2c.sda.line ~ <device>.<i2c sda pin>

spi interfaces:
spi = new SPI
spi.sclk.line ~ <device>.<spi sclk pin>
spi.mosi.line ~ <device>.<spi mosi pin>
spi.miso.line ~ <device>.<spi miso pin>

8. Add decoupling capacitors

looking at the datasheet, determine the required decoupling capacitors

eg: 2x 100nF 0402:

power_3v3 = new ElectricPower

# Decoupling power_3v3

power_3v3_caps = new Capacitor[2]
for capacitor in power_3v3_caps:
capacitor.capacitance = 100nF +/- 20%
capacitor.package = "0402"
power_3v3.hv ~> capacitor ~> power_3v3.lv

9. If device has pin configurable i2c addresses

If format is: <n x fixed address bits><m x pin configured address bits>
use addressor module:

- Use `Addressor<address_bits=N>` where **N = number of address pins**.
- Connect each `address_lines[i].line` to the corresponding pin, and its `.reference` to a local power rail.
- Set `addressor.base` to the lowest possible address and `assert addressor.address is i2c.address`.

10. Create a README.md

# <Manufacturer> <Manufacturer part number> <Short description>

## Usage

```ato
<copy in example>

```

## Contributing

Contributions to this package are welcome via pull requests on the GitHub repository.

## License

This atopile package is provided under the [MIT License](https://opensource.org/license/mit/).

11. Connect high level interfaces directly in example:

eg:

i2c = new I2C
power = new ElectricPower
sensor = new Sensor

i2c ~ sensor.i2c
power ~ sensor.power_3v3

# Additional Notes & Gotchas (generic)

- Multi-rail devices (VDD / VDDIO, AVDD / DVDD, etc.)

    - Model separate `ElectricPower` interfaces for each rail (e.g. `power_core`, `power_io`).
    - Mark each `.required = True` if the device cannot function without it, and add voltage assertions per datasheet.

- Optional interfaces (SPI vs I²C)

    - If the device supports multiple buses, pick one for the initial driver. Leave unused bus pins as `ElectricLogic` lines or expose a second interface module later.

- Decoupling guidance

    - If the datasheet shows multiple caps, model the **minimum required** set so the build passes; you can refine values/packages later.

- File / directory layout recap
    - `<vendor>-<device>/` – package root
    - `ato.yaml` – build manifest (include `default` **and** `example` targets)
    - `<device>.ato` – driver + optional example module
    - `parts/<MANUFACTURER_PARTNO>/` – atomic part + footprint/symbol/step files

These tips should prevent common "footprint not found", "pin X missing", and build-time path errors when you add new devices.

# Vibe coding a project

If the user gives you high level description of the project, use the following guide:

# How LLMs can design electronics:

#1 Rule: USE THE TOOLS. If the tools dont work, dont freak out, you are probably using them wrong. Ask for help if you get stuck.

Top level design

1. Research available packages relevant to the user requests using 'find_packages'
2. Inspect promising packages using 'inspect_package'
3. Propose packages to use for project and architucture to user, revise if needed
4. Install needed packages using 'install_package'
5. Import packages into main file
6. Create instances of packages in main module

## Power

1. Review for each package the required voltage and current (current may not be provided, use judement if nessesary)
2. Determine the power rails that need to be generated and a suitable tollerance (typically ~3-5% is acceptable)
3. Determine the input power source, typically a battery, USB connector or other power connector (eg XT30) and install relevant package
4. Find suitable regulators:
   a) if input voltage > required voltage and current is low, use an LDO package
   b) if input voltage > required voltage and current is high, use buck converter
   c) if input votlage < required voltage, use a boost converter
   d) if input voltage can be both less than or greater than input voltage, use buck boost (eg battery powered device that needs 3v3)
5. If battery powered, add charger package

Typical power architucture example with LDO:

- USB input power
- Low current output (eg microcontroller)

from "atopile/ti-tlv75901/ti-tlv75901.ato" import TLV75901_driver
from "atopile/usb-connectors/usb-connectors.ato" import USBCConn

module App:

    # Rails
    power_5v = new Power
    power_3v3 = new Power

    # Components
    ldo = new TLV75901_driver
    usb_connector = new USBCConn

    # Connections
    usb_connector.power ~ power_vbus
    power_vbus ~> ldo ~> power_3v3

## Communicaions

1. Review packages required interfaces, typically i2c, spi or ElectricLogics
2. Find suitable pins on the controller, typically a microcontroller or Linux SOC
3. Connect interfaces eg micro.i2c[0] ~ sensor.i2c

## Development process notes

- After making changes, be sure to use 'build_project' to update the PCB
- Builds will often generate errors/warnings, these should be reviewed and fixed
- Prioritize pacakges from 'atopile' over other packages

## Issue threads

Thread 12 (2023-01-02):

GBC video task (SPI transmit) failure after NES emulation

finger563, 2023-01-02:
**Describe the bug**
<!-- A clear and concise description of what the bug is. -->
If the GBC emulator is not the first run (e.g. if NES is run first), then when the GBC emulator is run, the video task cannot transmit via SPI (queued transmit) with a failure about out of memory.

However, if the GBC is first to run, then it works just fine (and you can then load NES just fine, and then go back to GBC just fine).

**To Reproduce**
Steps to reproduce the behavior:
1. Load NES ROM (e.g. 'Super Mario Bros.')
2. Leave NES ROM
3. Load GBC ROM (e.g. 'Link's Awakening DX')
4. See error (emulation / sound is running, but video is black; console prints out logs showing out of memory)

**Expected behavior**
<!-- A clear and concise description of what you expected to happen. -->
The emulators can be run in any order without issue.

**Screenshots / Images**
<!-- If applicable, add screenshots and / or images to help explain your problem. -->

**Additional context**
<!-- Add any other context about the problem here. -->
It seems that if the NES emulator runs first, then perhaps some memory used by the video / SPI subsystem is not able to be allocated internally (fast DMA) - however, both GBC and NES emulators use the same video / SPI memory - so will need to see what's going on here...

Closed 2023-05-08.

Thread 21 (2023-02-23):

Physical Volume controls

finger563, 2023-02-23:
## Is your feature request related to a problem? Please describe.
<!-- A clear and concise description of what the problem is. Ex. I'm always frustrated when [...] -->
Now that we have custom hardware (and can have more buttons) being able to do more than just mute / unmute the audio output would be nice while the game is playing.

## Describe the solution you'd like
<!-- A clear and concise description of what you want to happen. -->
Add 2 GPIO (or an analog attached to a potentiometer) for controlling volume, ideally on the side of the device.

## Describe alternatives you've considered
<!-- A clear and concise description of any alternative solutions or features you've considered. -->
Creating menus you can access while you're in game (probably will do that, but it will take a while)

## Additional context
<!-- Add any other context or screenshots about the feature request here. -->
Sound is nice

finger563, 2023-11-12:
Note: menus to control volume level while in game were added as part of #25

Closed 2023-12-18.

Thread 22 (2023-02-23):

Charging indication

finger563, 2023-02-23:
## Is your feature request related to a problem? Please describe.
<!-- A clear and concise description of what the problem is. Ex. I'm always frustrated when [...] -->
Right now we cannot know if the battery is charging when the USB-C cable is plugged in, and we don't know when the battery is charged.

## Describe the solution you'd like
<!-- A clear and concise description of what you want to happen. -->
Use the STAT pins on the charger IC to wire an LED for indication.

## Describe alternatives you've considered
<!-- A clear and concise description of any alternative solutions or features you've considered. -->
Continuing to guess?

## Additional context
<!-- Add any other context or screenshots about the feature request here. -->

Closed 2023-12-18.

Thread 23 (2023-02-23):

Battery status measurement

finger563, 2023-02-23:
## Is your feature request related to a problem? Please describe.
<!-- A clear and concise description of what the problem is. Ex. I'm always frustrated when [...] -->
Right now the processor has no way to determine what the battery level is, so it has no information to show the user.

## Describe the solution you'd like
<!-- A clear and concise description of what you want to happen. -->
Add battery level measurement (e.g. via ADC expander) to the hardware, measuring the battery SoC.

## Describe alternatives you've considered
<!-- A clear and concise description of any alternative solutions or features you've considered. -->
Continuing to guess?

## Additional context
<!-- Add any other context or screenshots about the feature request here. -->
Related to #22

Closed 2023-12-18.

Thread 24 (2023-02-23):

Show battery SoC / status in UI

finger563, 2023-02-23:
## Is your feature request related to a problem? Please describe.
<!-- A clear and concise description of what the problem is. Ex. I'm always frustrated when [...] -->
Even if #23 and #22 get implemented, the user will have no way to know what percentage state of charge (SoC) the battery is at, and will have no idea how much that will last them.

## Describe the solution you'd like
<!-- A clear and concise description of what you want to happen. -->
Monitor (after calibration) the SoC of the battery and show it in the main menu. Probably also show if it's charging or not as well?

## Describe alternatives you've considered
<!-- A clear and concise description of any alternative solutions or features you've considered. -->
Just using an icon (battery icons exist in LVGL).

## Additional context
<!-- Add any other context or screenshots about the feature request here. -->
#23 #22

Closed 2023-12-28.

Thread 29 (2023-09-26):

Adapt to the new BOX-3

LHYhorion, 2023-09-26:
### Is your feature request related to a problem?

The new BOX-3 has replaced its screen and uses the gt911 driver. In the current open-source project, the tt21100 driver is used, so the touchscreen cannot be driven.

### Describe the solution you'd like.

Can you provide a solution that supports the gt911? So that I can initialize the touchscreen properly.

### Describe alternatives you've considered.

_No response_

### Additional context.

_No response_

finger563, 2023-09-26:
Hi @LHYhorion I don't have a BOX-3 for testing, but I do have a LILYGO T-Deck which also has a GT911 touchscreen driver. I'm currently working on a barebones implementation for that driver over on https://github.com/esp-cpp/wireless-debug-display/pull/2. When I get it working there it should then not bee too much trouble to port here, but I won't be able to test it on a BOX-3 in case any other hardware or pin assignments have changed.

LHYhorion, 2023-09-26:
The currently available BOX-3 still uses the TT21100 driver, while the upcoming BOX-3 will use the GT911 driver. I have already adapted the pins for the currently available BOX-3 (you can refer to the BOX-3 BSP, with only two pins modified). If possible, you can port the GT911 driver to this project, and I can test the modifications.

finger563, 2023-09-27:
> The currently available BOX-3 still uses the TT21100 driver, while the upcoming BOX-3 will use the GT911 driver. I have already adapted the pins for the currently available BOX-3 (you can refer to the BOX-3 BSP, with only two pins modified). If possible, you can port the GT911 driver to this project, and I can test the modifications.

@LHYhorion I've gotten the gt911 driver working on that other repo, so next week when I've got some time, I'll add it on a branch of this repo and you can test it. You're welcome to make your own branch and a PR for it if you want to try before I can get around to it :)

LHYhorion, 2023-09-27:
OK, no problem.

LHYhorion, 2023-11-08:
Hi, perhaps you already have ESP-BOX-3, and you've made some hardware modifications to it. I've also made some adaptations to your project to accommodate these changes. However, because the modifications were substantial, I didn't submit a pull request. Here, I'd like to offer a suggestion. Maybe you could consider using Espressif's official drivers (Espressif has provided a proprietary BSP for BOX). This way, you can achieve compatibility across the entire BOX series and reduce maintenance costs.

finger563, 2023-11-08:
Hi @LHYhorion I actually just received it on Monday so I'm starting work on it. I've actually started testing the new components and such over on another project (https://github.com/esp-cpp/wireless-debug-display). I've found a couple of differences (e.g. the change to the backlight pin) and am working through them but I'd rather use the components I already have and make / update anything on my own rather than using the provided BSPs. The main reason is because I enjoy writing code :) but also If in the future I want to make my own versions of these devices I'll already have a base of code to build on. From what I can tell, it won't be too bad to make it support multiple devices (the wireless debug display project has a better architecture for how i support 4 devices), so I think I can continue down this route.

Out of curiosity - can you tell me the significant modifications you needed to make? Judging by the schematics and the Box 3's BSP, there shouldn't be too many changes required - though for some reason I've not had luck using the config in the Box 3's BSP (e.g. the screen doesn't respond as either an Ili9341 or a ST7789 display, and the I2C bus does not show either the TT21100 or the GT911 on the bus).

LHYhorion, 2023-11-08:
> Hi @LHYhorion I actually just received it on Monday so I'm starting work on it. I've actually started testing the new components and such over on another project (https://github.com/esp-cpp/wireless-debug-display). I've found a couple of differences (e.g. the change to the backlight pin) and am working through them but I'd rather use the components I already have and make / update anything on my own rather than using the provided BSPs. The main reason is because I enjoy writing code :) but also If in the future I want to make my own versions of these devices I'll already have a base of code to build on. From what I can tell, it won't be too bad to make it support multiple devices (the wireless debug display project has a better architecture for how i support 4 devices), so I think I can continue down this route.
>
> Out of curiosity - can you tell me the significant modifications you needed to make? Judging by the schematics and the Box 3's BSP, there shouldn't be too many changes required - though for some reason I've not had luck using the config in the Box 3's BSP (e.g. the screen doesn't respond as either an Ili9341 or a ST7789 display, and the I2C bus does not show either the TT21100 or the GT911 on the bus).

You're right, the BOX-3 only had three modified pins compared to the BOX, but there was actually a beta version of the BOX-3 before its release that used the TT21100. I chose to use the official BSP of Espressif (as I am more comfortable with their official drivers) to be compatible with the full range of BOX products, which would disrupt your original code structure. I also made some adjustments to some features, so I didn't submit a PR. Your project is excellent, thank you for your contributions.

finger563, 2023-11-08:
@LHYhorion Ah I see - and that makes complete sense. I did figure out the issue I was having with my Box-3 (turns out the LCD/Touch reset pin polarity changed between BOX and BOX-3) and now that I've figured that out I have it working in the other project. When I get some time this weekend I'll start getting this project working on the BOX-3. It'll take some time to get new circuit designs made and tested, but I should be able to get the code working and tested quickly.

LHYhorion, 2023-11-09:
> @LHYhorion Ah I see - and that makes complete sense. I did figure out the issue I was having with my Box-3 (turns out the LCD/Touch reset pin polarity changed between BOX and BOX-3) and now that I've figured that out I have it working in the other project. When I get some time this weekend I'll start getting this project working on the BOX-3. It'll take some time to get new circuit designs made and tested, but I should be able to get the code working and tested quickly.

That's correct, the polarity of the LCD reset pin has been changed, and two pins have been swapped. You can refer to the official BSP for BOX-3 for the specific changes, or feel free to reach out to me anytime for more information.

Closed 2023-11-10.

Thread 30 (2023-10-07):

When running the game, there are bugs and the sound has static noise

LHYhorion, 2023-10-07:
### Answers checklist.

- [X] I have read the documentation and the issue is not addressed there.
- [X] I have searched the issue tracker for a similar issue and not found a similar issue.

### General issue report

An error occurred while running the game：
E (78032) spi_master: check_trans_valid(796): trans tx_buffer should be NULL and SPI_TRANS_USE_TXDATA should be cleared to skip MOSI phase.
Couldn't queue trans: 258 'ESP_ERR_INVALID_ARG'
Additionally, it has been noticed that there is static noise while playing the background sound of the game.

LHYhorion, 2023-10-09:
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

The sound of the NES emulator isn't very good, but I found that removing the 32-bit conversion and retaining the 16-bit sound makes it sound better. Regarding the error issue, I found that sometimes the 'length' is calculated as 0. Assigning a non-zero value when it's calculated as 0 will prevent the error.

finger563, 2023-10-10:
Thanks for the tip about the sound conversion potentially being the root cause. I'll make the change and test if that improves the quality of the output sound on my side as well.

Regarding the length issue on the SPI transaction - in the transmit function i'm doing a length check on the data being sent so a length of 0 shouldn't be an issue.  Regarding your comment of `assigning a non-zero value when its calculated as 0` - what part of the code are you talking about here? Within the box-emu's `hal` component, the `nes` component, or within the `espp/display_drivers` component which is the main place the length is calculated for the SPI transaction data.

Closed 2023-10-13.

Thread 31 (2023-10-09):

Changing the scaling of the GB/C emulation no longer works

finger563, 2023-10-09:
### Answers checklist.

- [X] I have read the documentation [ESP-IDF Programming Guide](https://docs.espressif.com/projects/esp-idf/en/latest/) and the issue is not addressed there.
- [X] I have searched the issue tracker for a similar issue and not found a similar issue.

### What is the expected behavior?

You can change the scaling of the GB/C emulation either in the settings menu or at run-time and the emulation will work.

### What is the actual behavior?

If the video scaling is not set to original, then the gb/c emulation crashes the program. This occurs if you change it in the pause menu and then unpause or if you start the emulation after changing it in the top level settings menu.

### Steps to reproduce.

1. Start GB/C emulation
2. Pause the emulation
3. change the video scaling setting to something other than original.
4. See that the program crashes / device resets.

### Build or installation Logs.

_No response_

### More Information.

This used to work (prior to the cart refactor).

Closed 2023-10-19.

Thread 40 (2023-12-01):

Brightness controls in the Menu

finger563, 2023-12-01:
### Is your feature request related to a problem?

Right now the screen is always at max brightness. It would be nice (for eyes and battery) to be able to lower / raise it as the player wishes.

### Describe the solution you'd like.

Additional slider in menu (main and emulation) for controlling brightness of the screen.

### Describe alternatives you've considered.

_No response_

### Additional context.

_No response_

Closed 2023-12-12.

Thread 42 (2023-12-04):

DMA capable memory decreasing over time

finger563, 2023-12-04:
### Answers checklist.

- [X] I have read the documentation [ESP-IDF Programming Guide](https://docs.espressif.com/projects/esp-idf/en/latest/) and the issue is not addressed there.
- [X] I have searched the issue tracker for a similar issue and not found a similar issue.

### What is the expected behavior?

We do not leak memory and do not run out of DMA-capable memory (needed for LCD SPI).

### What is the actual behavior?

Running Nofrendo (NES) emluation seems to decrease DMA-capable memory:

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

### Steps to reproduce.

1. Run GBC rom
2. Run NES rom
3. Run another NES rom
4. Run GBC rom
5. Run another GBC rom

See that DMA decreases between steps 1->2 and steps 2->3, but not 3->4 or 4->5.

### Build or installation Logs.

_No response_

### More Information.

This may be related to `nofrendo` itself (and the modiciations I've made to it), or it could be more general and associated with one of the following:

1. How the screen is communicated with (e.g. emulators use DMA capable memory, but the menu/gui and clearing commands use non-dma capable memory)
2. Somewhere in the emulator(s) which is using stack that's not clearing for some reason
3. Somewhere in the emulator(s) which are using mallocs but not freeing the memory
4. Perhaps the internal allocation of dma-capable memory in the spi transaction in ESP-IDF is leaking memory during the cases when non-dma capable memory is being passed in?

I don't have hard data for it yet, but I believe the memory leak is worse when the steps include loading save states in the emulators.
6. Something else entirely?

finger563, 2023-12-04:
I've added some logging to `spi_master.c` and seen that there are cases where it is attempting to free memory that was not allocated. This happens during a timeout when trying to get the trans_result. Possibly related ESP-IDF issue here: https://github.com/espressif/esp-idf/issues/10066

Closed 2024-01-07.

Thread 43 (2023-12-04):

Move FPS logging from console to emulation menu (so that recent FPS is visible when paused)

finger563, 2023-12-04:
### Is your feature request related to a problem?

It's nice to know how much performance you're getting and how it differs between games or parts of games without having to be connected to a computer.

### Describe the solution you'd like.

In the top (or bottom) of the emulation paused menu, show the recent FPS as text.

### Describe alternatives you've considered.

Trying to show it as an optional overlay during emulation.

### Additional context.

_No response_

Closed 2023-12-12.

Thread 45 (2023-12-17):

Firmware support for Version 1

finger563, 2023-12-17:
### Is your feature request related to a problem?

Once the boards come in for #44, the gamepad will stop working and the new features will not be supported

### Describe the solution you'd like.

- Update code to use Aw9523 component
- Add MAX17048 component
- Update to handle volume buttons
- ADC on vbat line for monitoring battery voltage

### Describe alternatives you've considered.

Not improving anything ever? :/

### Additional context.

Related to #24 (which after we add the ADC and the MAX17048 component we'll be able to show meaningful information)

Closed 2024-01-17.

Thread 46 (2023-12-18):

USB Mass Storage Class (MSC) for managing Roms when plugged in over USB

finger563, 2023-12-18:
### Is your feature request related to a problem?

Right now the only way to update the roms is to pull the uSD card out and put it into my computer. That's annoying.

### Describe the solution you'd like.

Either by default or via the settings menu, provide USB MSC functionality. Will have to
1. Make sure the user does not write / modify files that are being read
2. We actually update the rom list / metadata if it changes
3. We don't allow USB MSC while playing games (for performance and to minimize bugs)

### Describe alternatives you've considered.

Using WiFi and hosting an FTP Server

### Additional context.

https://github.com/espressif/esp-idf/blob/master/examples/peripherals/usb/device/tusb_msc/README.md

Closed 2023-12-27.

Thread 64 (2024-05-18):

SMS / Game Gear Save / Load doesn't work

finger563, 2024-05-18:
### Answers checklist.

- [X] I have read the documentation [ESP-IDF Programming Guide](https://docs.espressif.com/projects/esp-idf/en/latest/) and the issue is not addressed there.
- [X] I have searched the issue tracker for a similar issue and not found a similar issue.

### What is the expected behavior?

Save states should be able to load.

### What is the actual behavior?

It pretends like it loads, but it doesnt.

### Steps to reproduce.

1. Load SMS ROM
2. Do something and save state
3. Load the state
4. See that the rom resets.

### Build or installation Logs.

_No response_

### More Information.

_No response_

Closed 2024-05-18.

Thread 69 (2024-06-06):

gitmodules file needs to be updated for the dependencies #188

n-92, 2024-06-06:
### Answers checklist.

- [X] I have read the documentation and the issue is not addressed there.
- [X] I have searched the issue tracker for a similar issue and not found a similar issue.

### General issue report

Hello,

Github does not allow cloning anymore over non https. Could it be possible to make changes in gitmodules file so that the submodule cloning works?

finger563, 2024-06-06:
It appears it's the espp repo which has a non-ssh submodule so both need to be updated.

finger563, 2024-06-08:
Can you provide the issue you're seeing? Clones over https still seem to work for me.

Closed 2024-06-19.

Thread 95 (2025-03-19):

How to change display sd card and input?

kazz2020, 2025-03-19:
hello how excactly change pins for display sd card and change input method. for example T-Deck Plus?

finger563, 2025-03-19:
Hey @kazz2020, the way you'd want to do that is to modify the `box-emu` component in `components/box-emu` to use the `espp::TDeck` component instead of the `espp::EspBox` component.

Some notes:
* I've not configured / exposed the audio codec on the TDeck yet, so you'd have to do that yourself to get audio on the TDeck for now.
* There are (unfortunately) some other places in the code which use the `EspBox` for some simple things:
  * Emulators:
    * Get / use the framebuffers. I'll make a quick PR to update the relevant emulators to get the framebuffers from the `box-emu` component, which would then make your life a little easier.
    * Get / set volume and mute state. I can similarly have this use the box-emu component, but again, the TDeck doesn't currently support audio, so you'd need to add that for these to work.
  * Menu
    * Also gets / sets the volume / mute state
    * Gets / sets the brightness of the display
  * Gui
    * Also gets / sets the volume / mute state
    * Gets / sets the brightness of the display

Today or tomorrow I'll make a PR to replace the access of the `EspBox` methods from the emulators and menu/gui components so that they instead simply use the `box-emu` component. Then if you update the `box-emu` component to use the `TDeck`, it should work relatively well.

Feel free to make a fork for this work and I can help you out as needed. I've got a T-Deck, but haven't spent much time setting it up to work with the esp-box-emu project, but I'm willing to help debug on my local hardware.

Is your plan to use the keyboard for the gamepad inputs? If so, you may need to update the C3 firmware on the T-Deck to support multiple button presses, since IIRC the keyboard driver only supports a single key at a time.

finger563, 2025-03-20:
@kazz2020 I've made PR #96 which means the only code you should need to change is now the `box-emu` component. You'd likely want to update the underlying `espp::TDeck` to support audio, but that's not too bad. Once you've done that, you can modify the implementation of the `box-emu` component to use it and to replace the communications with the custom gamepad with use of the keyboard or whatever you want.

If that sounds good, please close this issue. If you have additional questions or would like additional support, please open a discussion. This will ensure that others can benefit from the discussion since it will be more visible than closed issues :)

kazz2020, 2025-03-20:
> I've made PR [#96](https://github.com/esp-cpp/esp-box-emu/pull/96) which means the only code you should need to change is now the `box-emu` component. You'd likely want to update the underlying `espp::TDeck` to support audio, but that's not too bad. Once you've done that, you can modify the implementation of the `box-emu` component to use it and to replace the communications with the custom gamepad with use of the keyboard or whatever you want.
>
> If that sounds good, please close this issue. If you have additional questions or would like additional support, please open a discussion. This will ensure that others can benefit from the discussion since it will be more visible than closed issues :)

so when i change to TDeck what are the input methods? keyboard will work? Only sound doesnt work? can you guide me how to implement sound? where to start? official repo t-deck will help or look something else? maybe You have some resources for this?

kazz2020, 2025-03-20:
this is on 5.4  and when i only change to TDeckonly

`C:/Users/lukaszt/Desktop/Elektryk/esp-box-emu/components/jpegdec/src/jpeg.inl:2263:19: warning: unused variable 'ucColMask' [-Wunused-variable]
 2263 |     unsigned char ucColMask;
      |                   ^~~~~~~~~
[1284/1449] Building C object esp-idf/gbc/CMakeFiles/__idf_gbc.dir/gnuboy/src/emu.c.obj
cc1.exe: warning: command-line option '-Wno-deprecated-enum-enum-conversion' is valid for C++/ObjC++ but not for C
[1285/1449] Building C object esp-idf/gbc/CMakeFiles/__idf_gbc.dir/gnuboy/src/cpu.c.obj
cc1.exe: warning: command-line option '-Wno-deprecated-enum-enum-conversion' is valid for C++/ObjC++ but not for C
[1286/1449] Building C object esp-idf/gbc/CMakeFiles/__idf_gbc.dir/gnuboy/src/fastmem.c.obj
cc1.exe: warning: command-line option '-Wno-deprecated-enum-enum-conversion' is valid for C++/ObjC++ but not for C
[1287/1449] Building C object esp-idf/gbc/CMakeFiles/__idf_gbc.dir/gnuboy/src/hw.c.obj
cc1.exe: warning: command-line option '-Wno-deprecated-enum-enum-conversion' is valid for C++/ObjC++ but not for C
[1288/1449] Building C object esp-idf/gbc/CMakeFiles/__idf_gbc.dir/gnuboy/src/lcd.c.obj
cc1.exe: warning: command-line option '-Wno-deprecated-enum-enum-conversion' is valid for C++/ObjC++ but not for C
[1289/1449] Building C object esp-idf/gbc/CMakeFiles/__idf_gbc.dir/gnuboy/src/lcdc.c.obj
cc1.exe: warning: command-line option '-Wno-deprecated-enum-enum-conversion' is valid for C++/ObjC++ but not for C
[1291/1449] Building C object esp-idf/gbc/CMakeFiles/__idf_gbc.dir/gnuboy/src/mem.c.obj
cc1.exe: warning: command-line option '-Wno-deprecated-enum-enum-conversion' is valid for C++/ObjC++ but not for C
[1292/1449] Building C object esp-idf/gbc/CMakeFiles/__idf_gbc.dir/gnuboy/src/rtc.c.obj
cc1.exe: warning: command-line option '-Wno-deprecated-enum-enum-conversion' is valid for C++/ObjC++ but not for C
[1293/1449] Building C object esp-idf/gbc/CMakeFiles/__idf_gbc.dir/gnuboy/src/save.c.obj
cc1.exe: warning: command-line option '-Wno-deprecated-enum-enum-conversion' is valid for C++/ObjC++ but not for C
[1294/1449] Building C object esp-idf/gbc/CMakeFiles/__idf_gbc.dir/gnuboy/src/loader.c.obj
cc1.exe: warning: command-line option '-Wno-deprecated-enum-enum-conversion' is valid for C++/ObjC++ but not for C
[1295/1449] Building C object esp-idf/gbc/CMakeFiles/__idf_gbc.dir/gnuboy/src/sound.c.obj
cc1.exe: warning: command-line option '-Wno-deprecated-enum-enum-conversion' is valid for C++/ObjC++ but not for C
[1296/1449] Building C object esp-idf/genesis/CMakeFiles/__idf_genesis.dir/gwenesis/src/cpus/Z80/Debug.c.obj
cc1.exe: warning: command-line option '-Wno-deprecated-enum-enum-conversion' is valid for C++/ObjC++ but not for C
[1297/1449] Building C object esp-idf/genesis/CMakeFiles/__idf_genesis.dir/gwenesis/src/cpus/Z80/ConDebug.c.obj
cc1.exe: warning: command-line option '-Wno-deprecated-enum-enum-conversion' is valid for C++/ObjC++ but not for C
[1298/1449] Building C object esp-idf/genesis/CMakeFiles/__idf_genesis.dir/gwenesis/src/cpus/Z80/Z80.c.obj
cc1.exe: warning: command-line option '-Wno-deprecated-enum-enum-conversion' is valid for C++/ObjC++ but not for C
[1299/1449] Building C object esp-idf/genesis/CMakeFiles/__idf_genesis.dir/gwenesis/src/bus/gwenesis_bus.c.obj
cc1.exe: warning: command-line option '-Wno-deprecated-enum-enum-conversion' is valid for C++/ObjC++ but not for C
[1300/1449] Building C object esp-idf/genesis/CMakeFiles/__idf_genesis.dir/gwenesis/src/cpus/M68K/m68kcpu.c.obj
cc1.exe: warning: command-line option '-Wno-deprecated-enum-enum-conversion' is valid for C++/ObjC++ but not for C
[1303/1449] Building C object esp-idf/genesis/CMakeFiles/__idf_genesis.dir/gwenesis/src/io/gwenesis_io.c.obj
cc1.exe: warning: command-line option '-Wno-deprecated-enum-enum-conversion' is valid for C++/ObjC++ but not for C
[1304/1449] Building C object esp-idf/genesis/CMakeFiles/_...enesis.dir/gwenesis/src/savestate/gwenesis_savestate.c.obj
cc1.exe: warning: command-line option '-Wno-deprecated-enum-enum-conversion' is valid for C++/ObjC++ but not for C
[1305/1449] Building C object esp-idf/genesis/CMakeFiles/__idf_genesis.dir/gwenesis/src/sound/z80inst.c.obj
cc1.exe: warning: command-line option '-Wno-deprecated-enum-enum-conversion' is valid for C++/ObjC++ but not for C
[1306/1449] Building C object esp-idf/genesis/CMakeFiles/__idf_genesis.dir/gwenesis/src/sound/ym2612.c.obj
cc1.exe: warning: command-line option '-Wno-deprecated-enum-enum-conversion' is valid for C++/ObjC++ but not for C
[1307/1449] Building C object esp-idf/genesis/CMakeFiles/__idf_genesis.dir/gwenesis/src/sound/gwenesis_sn76489.c.obj
cc1.exe: warning: command-line option '-Wno-deprecated-enum-enum-conversion' is valid for C++/ObjC++ but not for C
[1308/1449] Building C object esp-idf/genesis/CMakeFiles/__idf_genesis.dir/gwenesis/src/vdp/gwenesis_vdp_gfx.c.obj
cc1.exe: warning: command-line option '-Wno-deprecated-enum-enum-conversion' is valid for C++/ObjC++ but not for C
C:/Users/lukaszt/Desktop/Elektryk/esp-box-emu/components/genesis/gwenesis/src/vdp/gwenesis_vdp_gfx.c:975:1: warning: 'blit_4to5_line' defined but not used [-Wunused-function]
  975 | blit_4to5_line(uint16_t *in, uint16_t *out) {
      | ^~~~~~~~~~~~~~
[1309/1449] Building C object esp-idf/genesis/CMakeFiles/__idf_genesis.dir/gwenesis/src/vdp/gwenesis_vdp_mem.c.obj
cc1.exe: warning: command-line option '-Wno-deprecated-enum-enum-conversion' is valid for C++/ObjC++ but not for C
[1311/1449] Building C object esp-idf/gui/CMakeFiles/__idf_gui.dir/generated/ui.c.obj
cc1.exe: warning: command-line option '-Wno-deprecated-enum-enum-conversion' is valid for C++/ObjC++ but not for C
C:/Users/lukaszt/Desktop/Elektryk/esp-box-emu/components/gui/generated/ui.c: In function 'ui_event_settingsbutton':
C:/Users/lukaszt/Desktop/Elektryk/esp-box-emu/components/gui/generated/ui.c:84:66: warning: unused variable 'target' [-Wunused-variable]
   84 |     lv_event_code_t event_code = lv_event_get_code(e);lv_obj_t * target = lv_event_get_target(e);
      |                                                                  ^~~~~~
C:/Users/lukaszt/Desktop/Elektryk/esp-box-emu/components/gui/generated/ui.c: In function 'ui_event_closebutton':
C:/Users/lukaszt/Desktop/Elektryk/esp-box-emu/components/gui/generated/ui.c:90:66: warning: unused variable 'target' [-Wunused-variable]
   90 |     lv_event_code_t event_code = lv_event_get_code(e);lv_obj_t * target = lv_event_get_target(e);
      |                                                                  ^~~~~~
[1312/1449] Building C object esp-idf/gui/CMakeFiles/__idf_gui.dir/generated/ui_comp.c.obj
cc1.exe: warning: command-line option '-Wno-deprecated-enum-enum-conversion' is valid for C++/ObjC++ but not for C
[1313/1449] Building C object esp-idf/gui/CMakeFiles/__idf_gui.dir/generated/components/ui_comp_hook.c.obj
cc1.exe: warning: command-line option '-Wno-deprecated-enum-enum-conversion' is valid for C++/ObjC++ but not for C
[1314/1449] Building C object esp-idf/gui/CMakeFiles/__idf_gui.dir/generated/ui_helpers.c.obj
cc1.exe: warning: command-line option '-Wno-deprecated-enum-enum-conversion' is valid for C++/ObjC++ but not for C
[1315/1449] Building C object esp-idf/gui/CMakeFiles/__idf_gui.dir/generated/screens/ui_romscreen.c.obj
cc1.exe: warning: command-line option '-Wno-deprecated-enum-enum-conversion' is valid for C++/ObjC++ but not for C
[1316/1449] Building C object esp-idf/gui/CMakeFiles/__idf_gui.dir/generated/screens/ui_settingsscreen.c.obj
cc1.exe: warning: command-line option '-Wno-deprecated-enum-enum-conversion' is valid for C++/ObjC++ but not for C
[1317/1449] Building C object esp-idf/gui/CMakeFiles/__idf_gui.dir/generated/images/ui_temporary_image.c.obj
cc1.exe: warning: command-line option '-Wno-deprecated-enum-enum-conversion' is valid for C++/ObjC++ but not for C
[1318/1449] Building C object esp-idf/menu/CMakeFiles/__idf_menu.dir/generated/components/ui_comp_hook.c.obj
cc1.exe: warning: command-line option '-Wno-deprecated-enum-enum-conversion' is valid for C++/ObjC++ but not for C
[1319/1449] Building C object esp-idf/menu/CMakeFiles/__idf_menu.dir/generated/ui.c.obj
cc1.exe: warning: command-line option '-Wno-deprecated-enum-enum-conversion' is valid for C++/ObjC++ but not for C
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

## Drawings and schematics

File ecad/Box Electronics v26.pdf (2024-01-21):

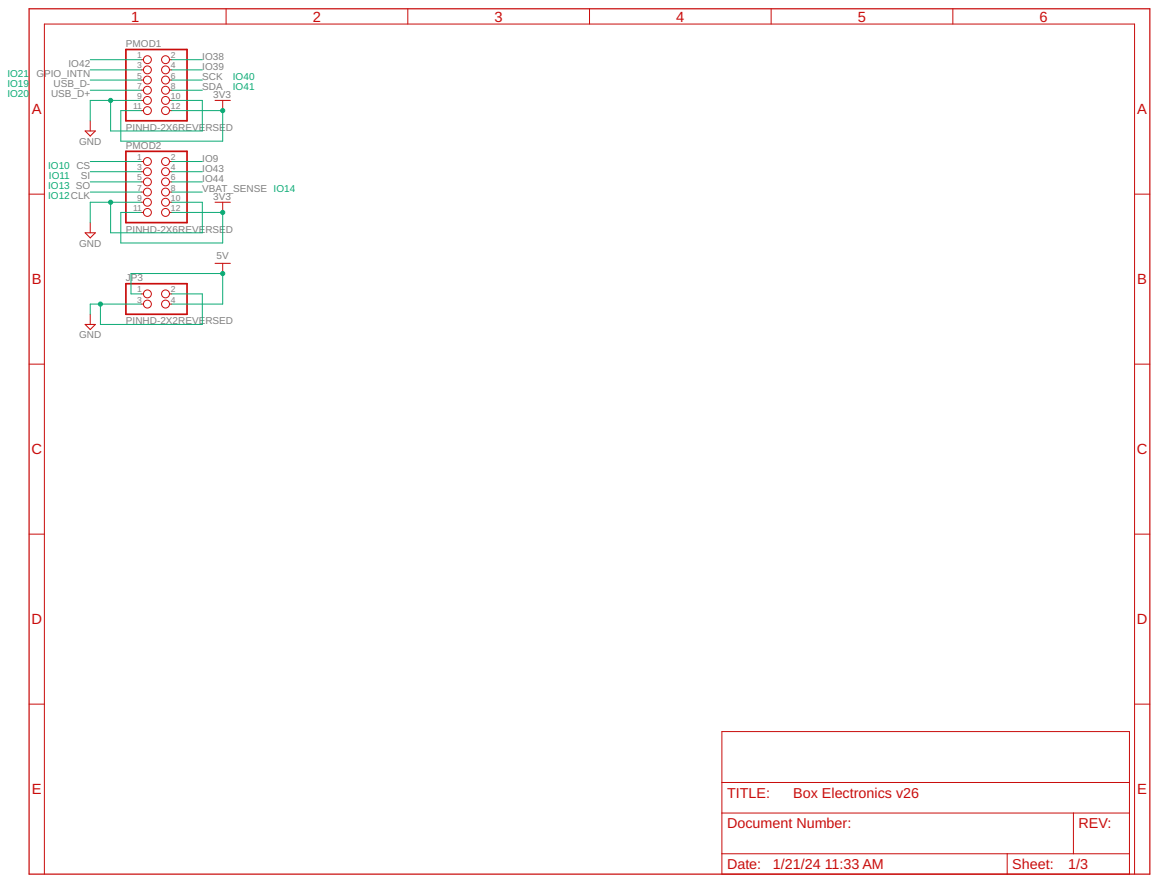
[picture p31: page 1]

Document Number: | REV:

Date: 1/21/24 11:33 AM | Sheet: 1/3

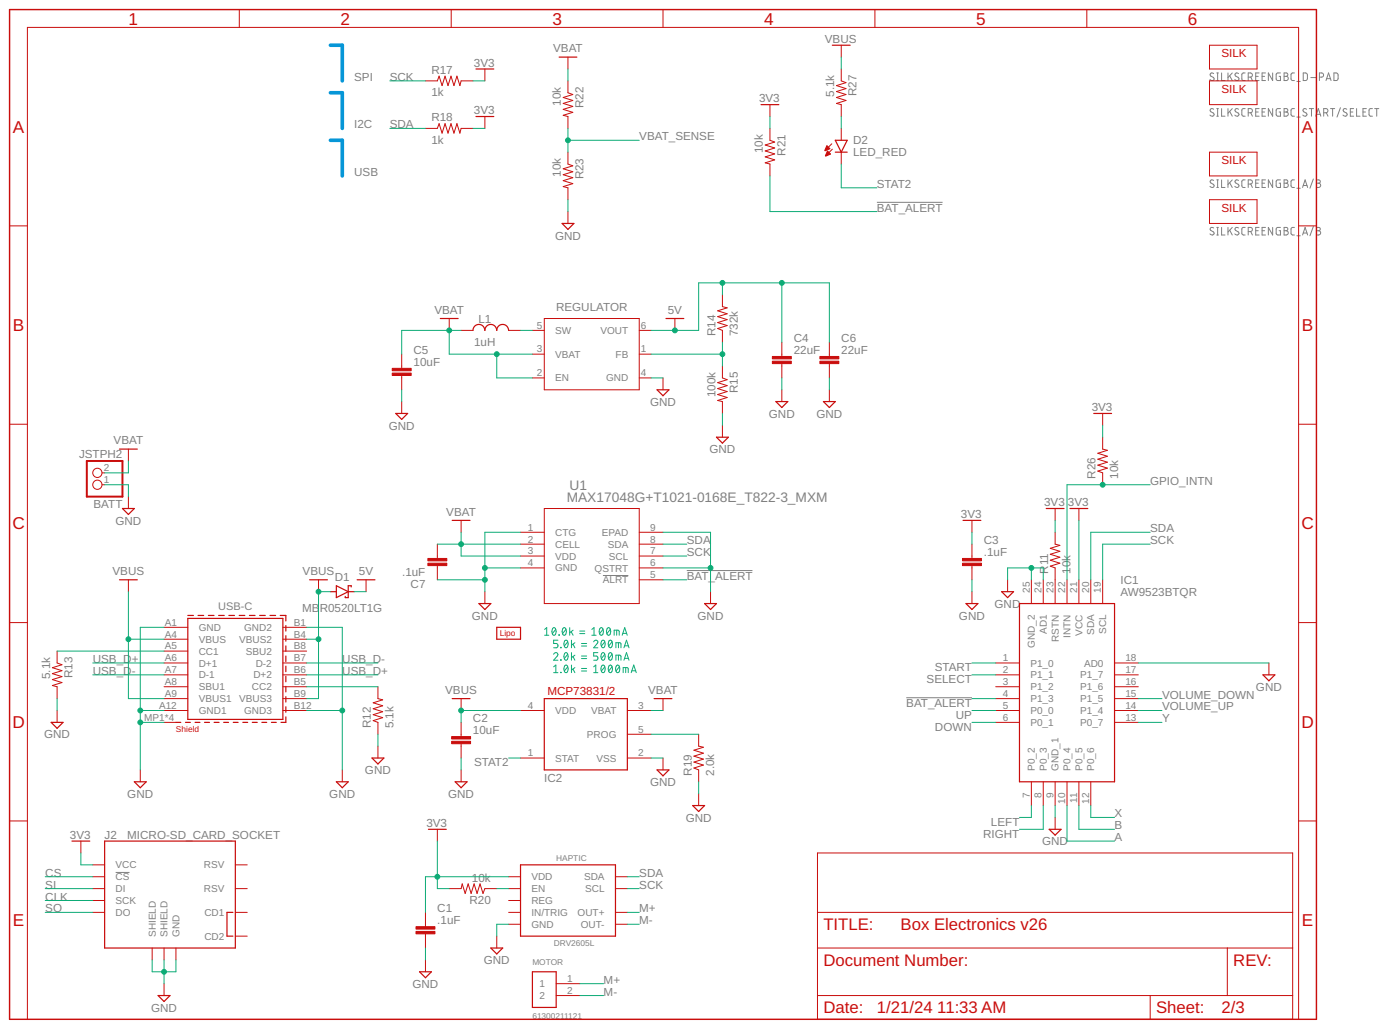
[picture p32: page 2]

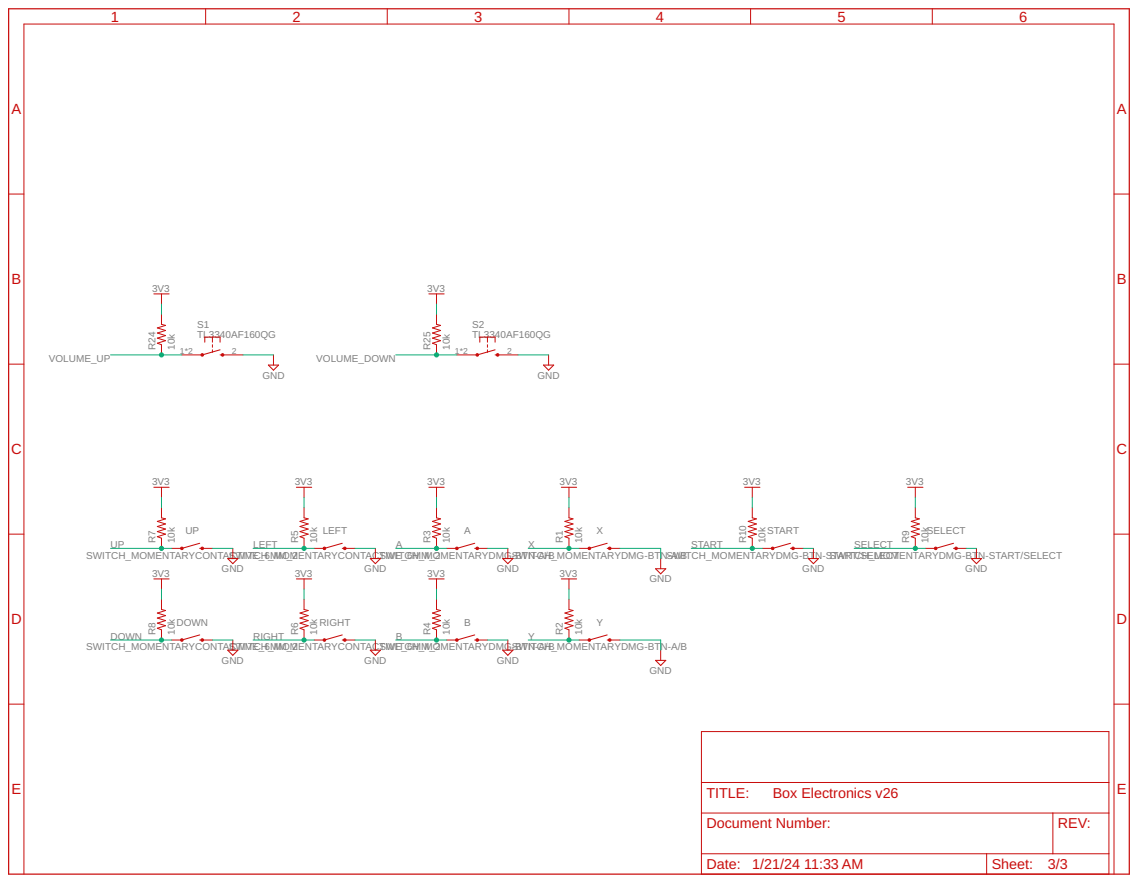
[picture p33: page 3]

SWITCH_MOMENTARYDMG-BTN-SSTWARITTC/SHE_LMEOCMTENTARYDMG-BTN-START/SELECT

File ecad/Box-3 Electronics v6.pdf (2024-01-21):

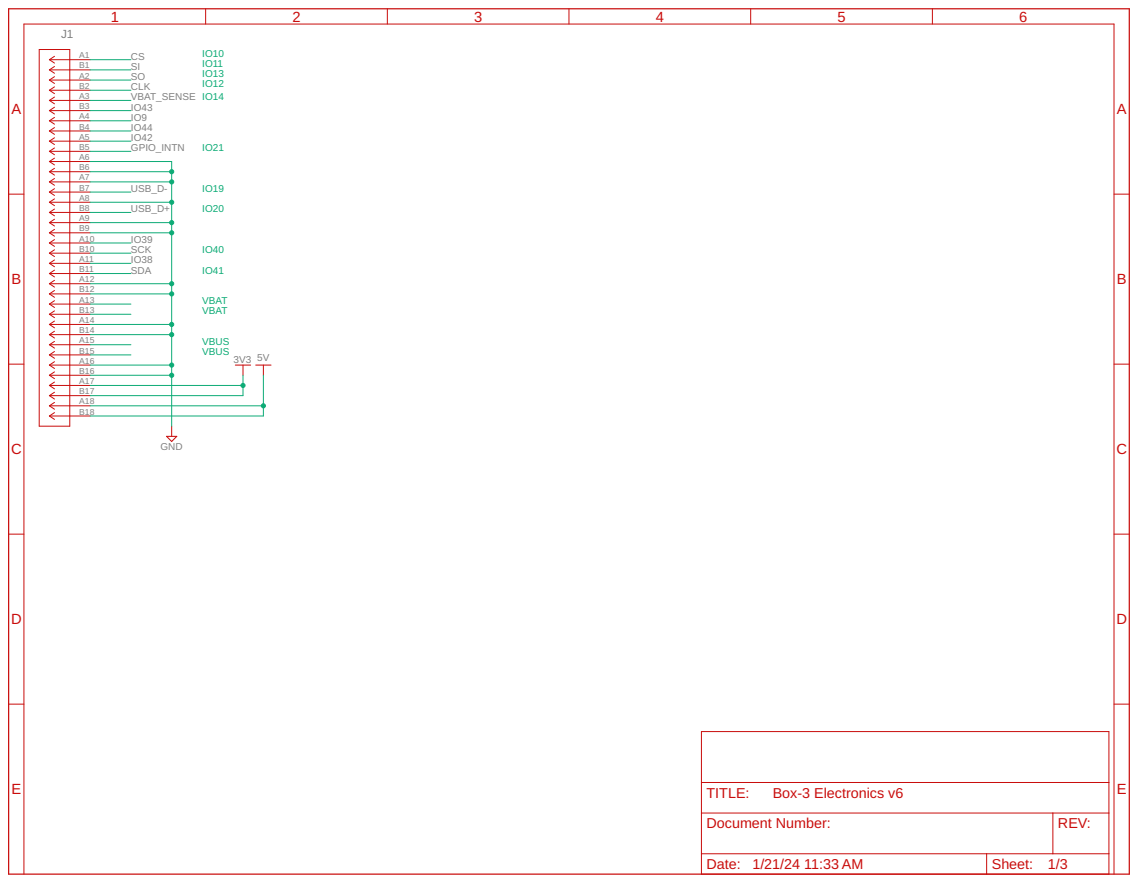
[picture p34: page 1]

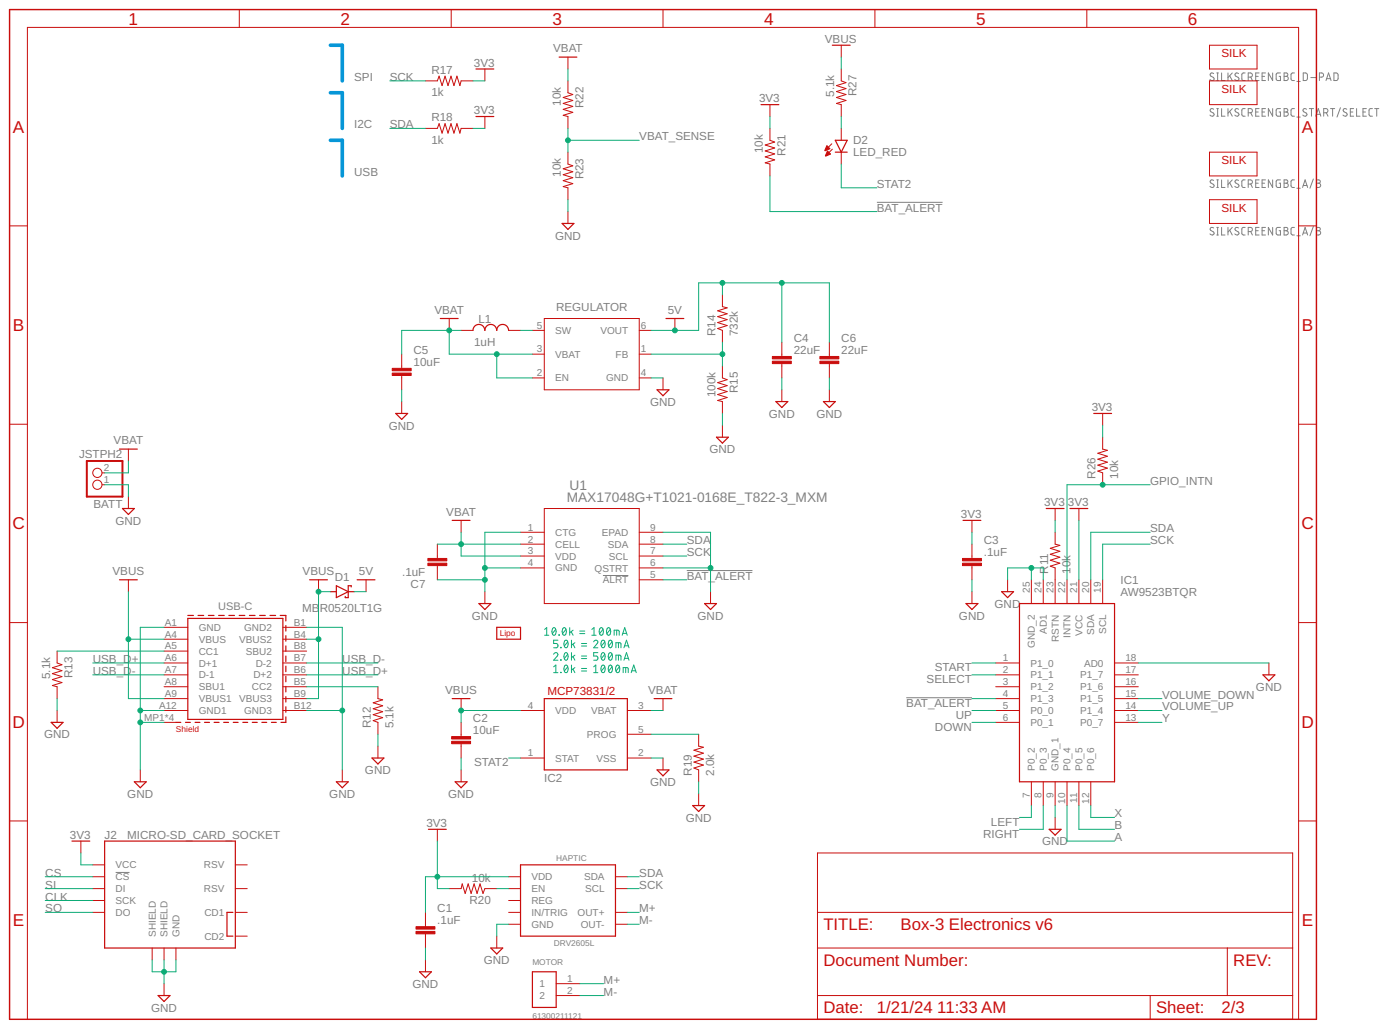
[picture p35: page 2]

VBUS

Document Number: | REV:

Date: 1/21/24 11:33 AM | Sheet: 2/3

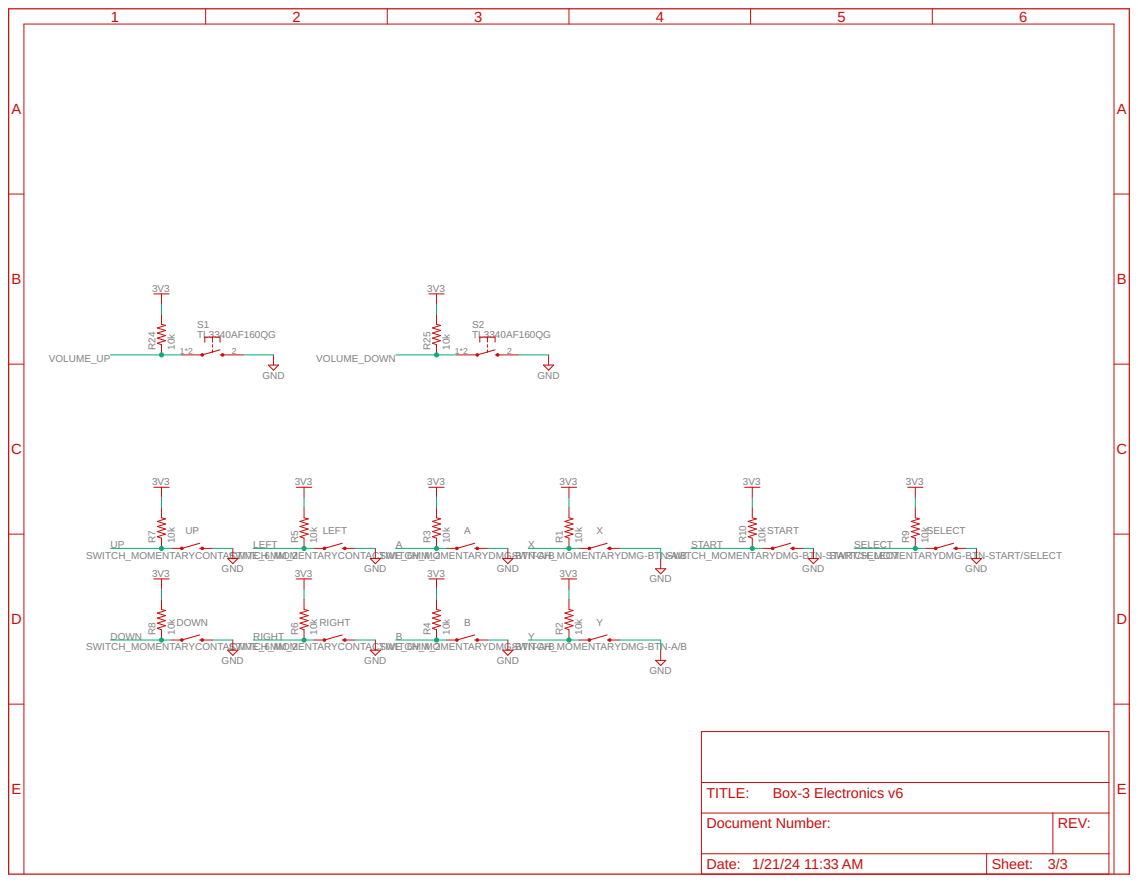
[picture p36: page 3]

SWITCH_MOMENTARYDMG-BTN-SSTWARITTC/SHE_LMEOCMTENTARYDMG-BTN-START/SELECT

Document Number: | REV:

Date: 1/21/24 11:33 AM | Sheet: 3/3

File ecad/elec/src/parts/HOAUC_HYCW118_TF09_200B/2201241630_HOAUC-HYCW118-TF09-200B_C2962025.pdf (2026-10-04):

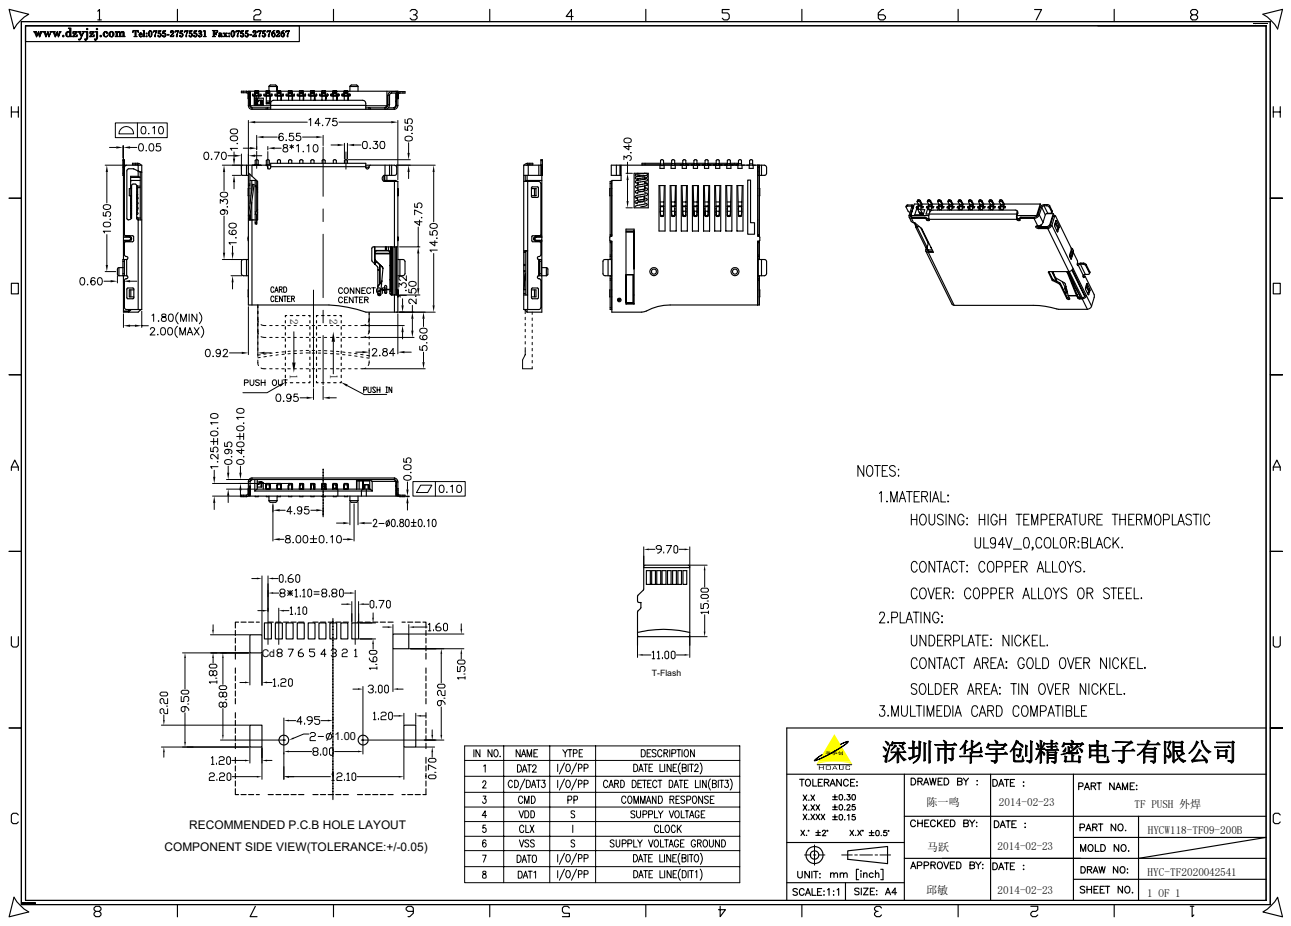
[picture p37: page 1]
HYCW118-TF09-200B; HYC-TF2020042541; 陈一鸣; 2014-02-23 T-Flash Cd; 1.00 RECOMMENDED P.C.B HOLE LAYOUT COMPONENT SIDE VIEW(TOLERANCE:+/-0.05) ¹

TF PUSH 外焊

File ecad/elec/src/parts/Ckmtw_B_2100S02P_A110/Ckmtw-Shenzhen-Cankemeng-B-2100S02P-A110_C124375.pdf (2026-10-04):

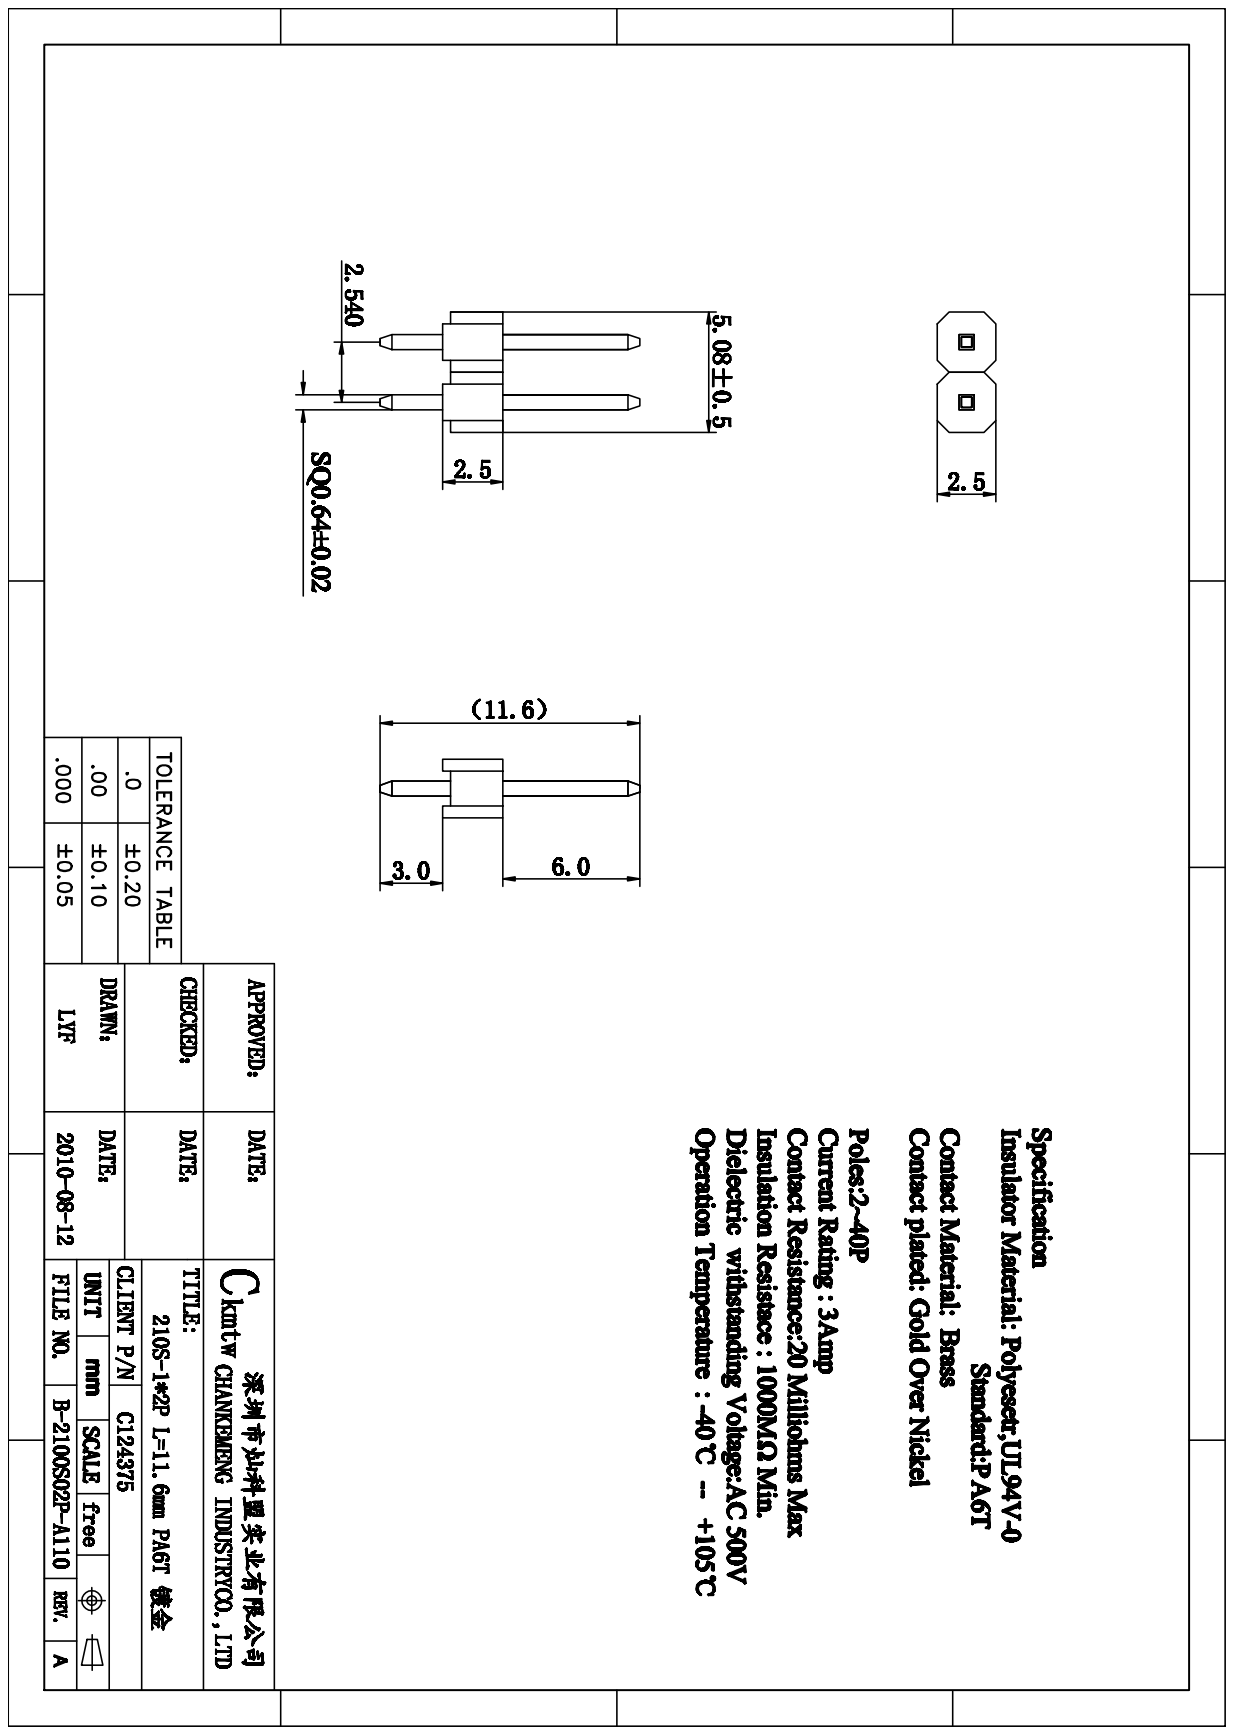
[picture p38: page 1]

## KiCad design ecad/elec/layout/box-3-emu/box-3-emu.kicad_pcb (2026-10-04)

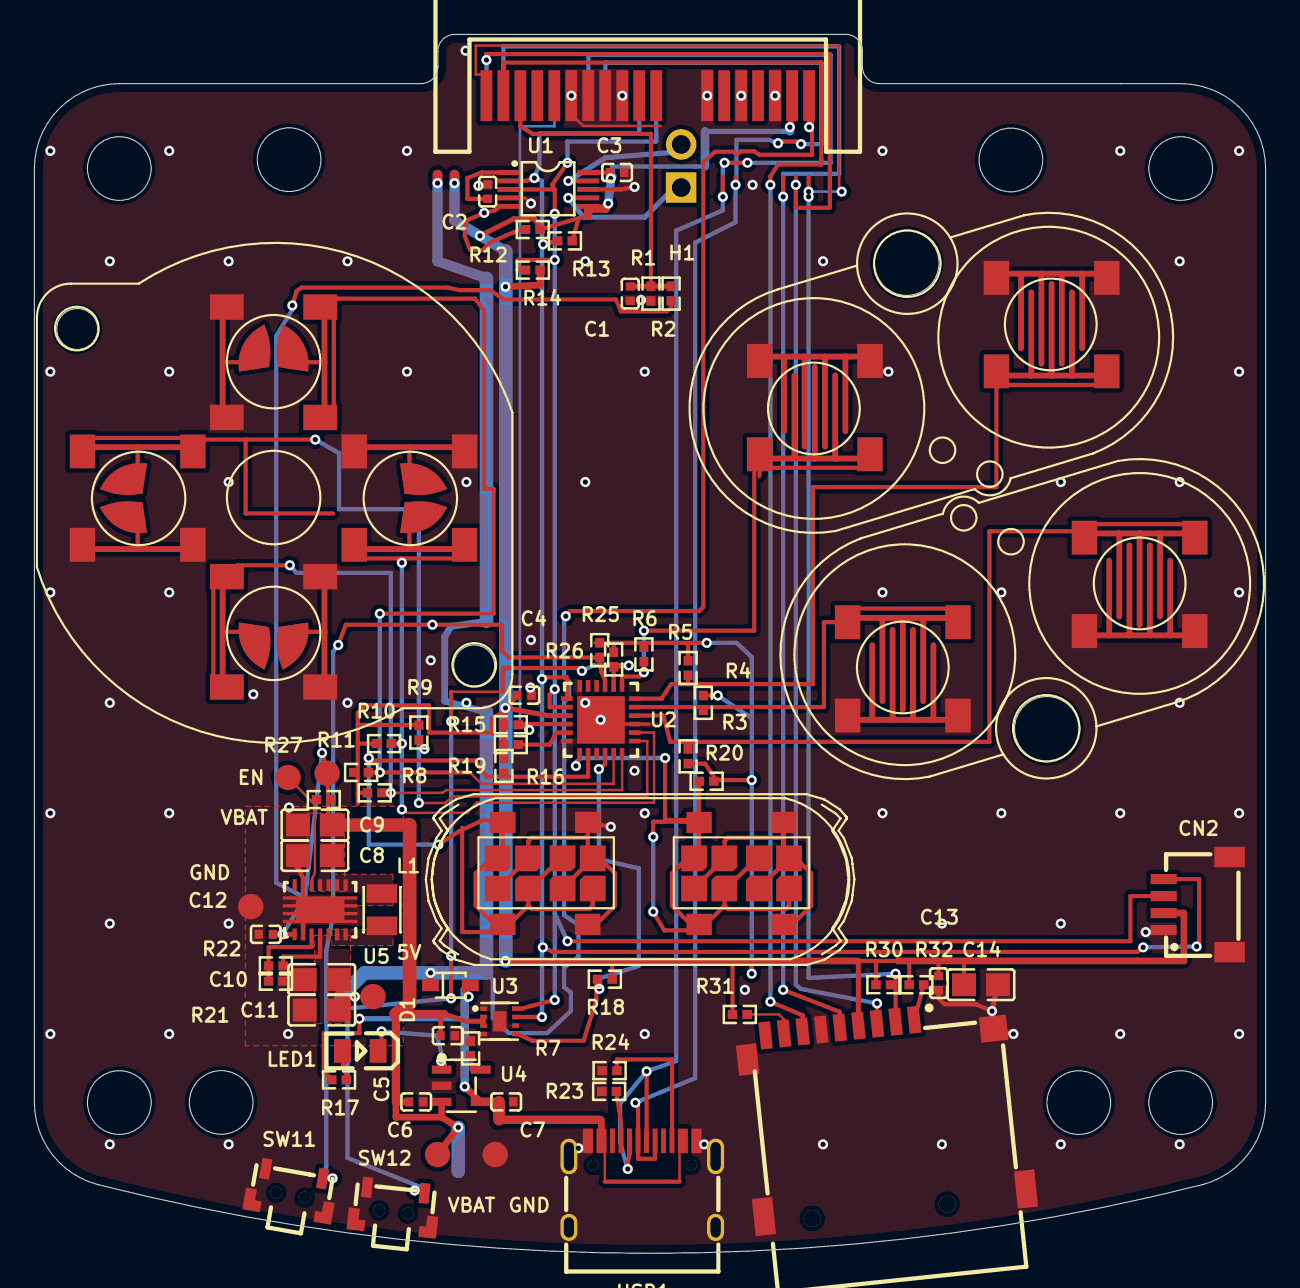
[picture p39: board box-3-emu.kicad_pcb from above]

Board: 2 copper layers, 72.5 x 71.8 mm, 81 parts (1 on the bottom side), 44 nets.

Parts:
C1, C3, C4, C5, C13: 100nF ±10%; C0402
C2: 1µF ±20%; C0402
C6, C7: 4.7µF ±10%; C0402
C8, C9: 10µF ±20%; C0805
C10, C11, C14: 22µF ±20%; C0805
C12: 100nF ±20%; C0402
CN1: CONN-SMD_P2.00_S2B-PH-SM4-TB-LF-SN
CN2: CONN-SMD_4P-P1.00_SM04B-SRSS-TB-LF-SN
CN3: CONN-SMD_5-1734857-1
D1: SOD-323_L1.8-W1.3-LS2.5-RD
H1: HDR-TH_2P-P2.54-V-M-1
L1: IND-SMD_L2.5-W2.0_WPN252012H
LED1: LED0805-R-RD
MECH1, MECH2: GAMEBOY_COLOR_A_B_BUTTON_MEMBRANE
MECH3: BOX_3_EMU
R1, R2: 1MΩ ±1%; R0402
R3, R4, R5, R6, R8, R9, R10, R11, R12, R13, R14, R15, R16, R18, R19, R20, R25, R26, R27, R30, R31, R32: 10kΩ ±5%; R0402
R7: 2kΩ ±5%; R0402
R17, R23, R24: 5.1kΩ ±5%; R0402
R21: 91kΩ ±1%; R0402
R22: 820kΩ ±1%; R0402
SW1, SW2, SW3, SW4: GBC_A_B_BUTTON
SW5, SW6, SW7, SW8: GBC_DPAD_BUTTON
SW9, SW10: GBC_START_SELECT_BUTTON
SW11, SW12: SW-SMD_2P-TS24CA
TP1, TP2, TP3, TP4, TP5, TP6: TESTPOINT
U1: VSSOP-10_L3.0-W3.0-P0.50-LS4.9-BL
U2: VFQFPN-24_L4.0-W4.0-P0.50-BL-EP2.8
U3: TDFN-8_L2.0-W2.0-P0.50-BL-EP1.2
U4: SOT-23-5_L3.0-W1.7-P0.95-LS2.8-BL
U5: VSON-14_L4.0-W3.0-P0.50-BL-EP_TI_DSJ
U6: SIM-SMD_C9900007362
U$1: GAMEBOY_COLOR_DPAD_MEMBRANE
U$2: GAMEBOY_COLOR_START_SELECT_MEMBRANE
USB1: USB-C-SMD_TYPE-611-T3-W

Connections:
1: L1.1, U5.8, U5.9
2: L1.2, U5.6, U5.7
A5: R23.1, USB1.A5
B5: R24.1, USB1.B5
DATA_N: CN3.B7, USB1.A7, USB1.B7
DATA_P: CN3.B8, USB1.A6, USB1.B6
EN: R12.1, U1.5
FB: R21.1, R22.2, U5.3
INTN: CN3.B5, R15.2, U2.22
MISO: CN3.A2, U6.7
MOSI: CN3.B1, U6.3
PROG: R7.1, U4.5
RSTN: R16.2, U2.23
SCL: CN2.4, CN3.B10, R13.2, U1.2, U2.19, U3.7
SCLK: CN3.B2, U6.5
SDA: CN2.3, CN3.B11, R14.2, U1.3, U2.20, U3.8
STAT: LED1.2, U4.1
a: H1.1, U1.7
b: H1.2, U1.9
battery_measurement: C1.1, CN3.A3, R1.1, R2.2
boost_en: R27.2, TP2.1, U5.12
buttons_abxy-b-line: R4.2, SW2.1, SW2.3, U2.11
down: R8.2, SW5.1, SW5.3, U2.6
gnd: C1.2, C2.2, C3.2, C4.2, C5.2, C6.2, C7.2, C8.2, C9.2, C10.2, C11.2, C12.2, C13.2, C14.2, CN1.2, CN1.3, CN1.4, CN2.1, CN2.5, CN2.6, CN3.A6, CN3.A7, CN3.A8, CN3.A9, CN3.A12, CN3.A14, CN3.A16, CN3.B6, CN3.B9, CN3.B12, CN3.B14, CN3.B16, R1.2, R7.2, R21.2, R23.2, R24.2, SW1.2, SW1.4, SW2.2, SW2.4, SW3.2, SW3.4, SW4.2, SW4.4, SW5.2, SW5.4, SW6.2, SW6.4, SW7.2, SW7.4, SW8.2, SW8.4, SW9.2, SW9.4, SW10.2, SW10.4, SW11.2, SW11.3, SW11.4, SW12.2, SW12.3, SW12.4, TP3.1, TP5.1, U1.4, U1.8, U2.9, U2.18, U2.24, U2.25, U3.1, U3.4, U3.6, U3.9, U4.2, U5.2, U5.13, U5.15, U6.6, U6.G, USB1.17, USB1.18, USB1.19, USB1.20, USB1.A1B12, USB1.B1A12
hv: C2.1, U1.1
io9: R31.2, U6.8
io10: CN3.A1, R30.2, U6.2
io44: R32.2, U6.1
left: R9.2, SW6.1, SW6.3, U2.7
line: R3.2, SW1.1, SW1.3, U2.10
nALRT: R18.1, U2.4, U3.5
pos: LED1.1, R17.2
right: R10.2, SW7.1, SW7.3, U2.8
select: R19.2, SW9.1, SW9.3, U2.2
start: R20.2, SW10.1, SW10.3, U2.1
up: R11.2, SW8.1, SW8.3, U2.5
vbat: C5.1, C6.1, C8.1, C9.1, C12.1, CN1.1, R2.1, R27.1, TP4.1, TP6.1, U3.2, U3.3, U4.3, U5.1, U5.10, U5.11
vbus: C7.1, D1.2, R17.1, U4.4, USB1.A4B9, USB1.A9B4
vcc_3v3: C3.1, C4.1, C13.1, C14.1, CN2.2, CN3.A17, CN3.B17, R3.1, R4.1, R5.1, R6.1, R8.1, R9.1, R10.1, R11.1, R12.2, R13.1, R14.1, R15.1, R16.1, R18.2, R19.1, R20.1, R25.1, R26.1, R30.1, R31.1, R32.1, U1.6, U1.10, U2.21, U6.4
vcc_5v: C10.1, C11.1, CN3.A18, CN3.B18, D1.1, R22.1, TP1.1, U5.4, U5.5
vol_down: R25.2, SW11.1, U2.15
vol_up: R26.2, SW12.1, U2.14
x_y_btns-a-line: R5.2, SW3.1, SW3.3, U2.12
x_y_btns-b-line: R6.2, SW4.1, SW4.3, U2.13

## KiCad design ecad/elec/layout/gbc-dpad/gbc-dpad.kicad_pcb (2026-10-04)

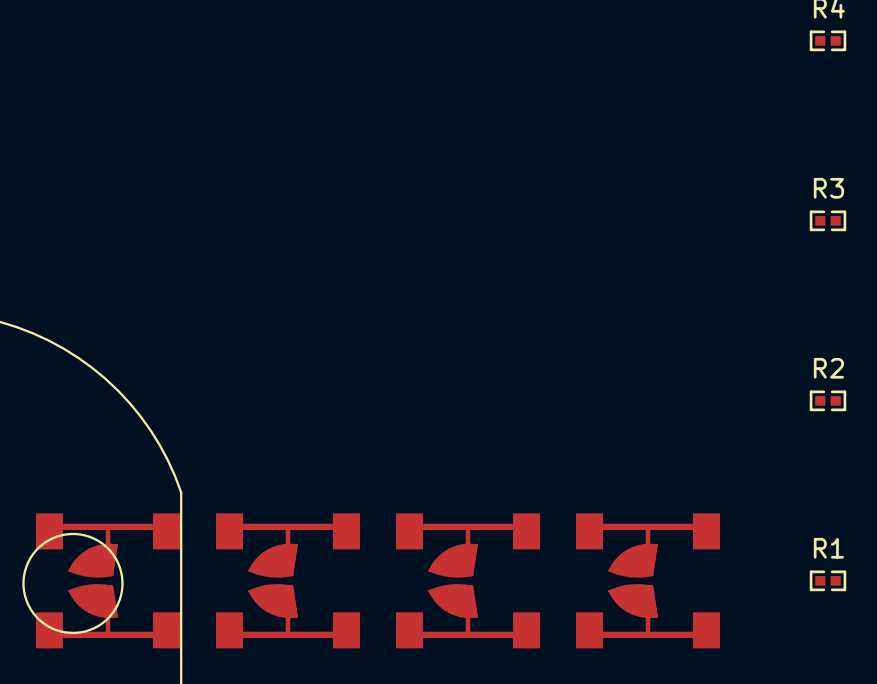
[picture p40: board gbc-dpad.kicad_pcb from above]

Board: 2 copper layers, 9 parts (0 on the bottom side), 6 nets, no tracks yet.

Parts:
MECH1: GAMEBOY_COLOR_DPAD_MEMBRANE
R1, R2, R3, R4: 10kΩ ±5%; R0402
SW1, SW2, SW3, SW4: GBC_DPAD_BUTTON

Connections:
contact_in: R1.2, SW1.1, SW1.3
hv: R1.1, R2.1, R3.1, R4.1
left_button-out-contact_in: R2.2, SW2.1, SW2.3
lv: SW1.2, SW1.4, SW2.2, SW2.4, SW3.2, SW3.4, SW4.2, SW4.4
right_button-out-contact_in: R3.2, SW3.1, SW3.3
up_button-out-contact_in: R4.2, SW4.1, SW4.3

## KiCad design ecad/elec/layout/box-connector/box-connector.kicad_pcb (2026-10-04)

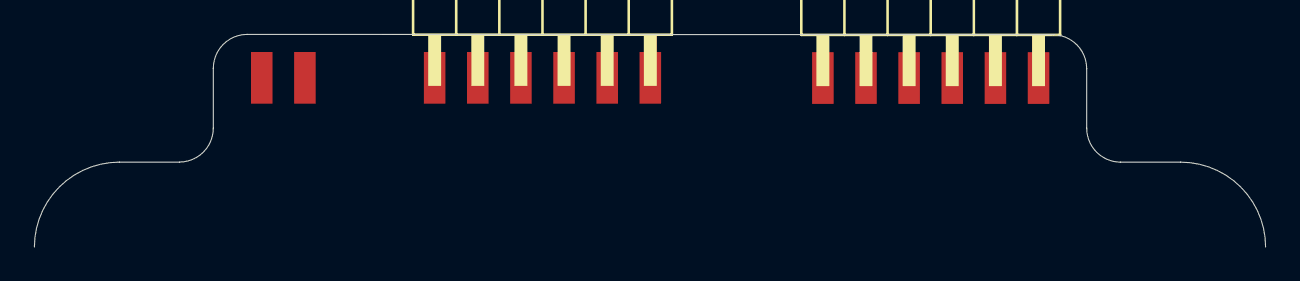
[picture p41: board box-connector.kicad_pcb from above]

Board: 2 copper layers, 3 parts (1 on the bottom side), 3 nets, no tracks yet.

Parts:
J1, J2: 2X06_EDGE_REVERSED
U4: 2X02_EDGE_REVERSED

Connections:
hv: J1.11, J1.12, J2.11, J2.12
lv: J1.9, J1.10, J2.9, J2.10, U4.2, U4.3
power_5v-hv: U4.1, U4.4

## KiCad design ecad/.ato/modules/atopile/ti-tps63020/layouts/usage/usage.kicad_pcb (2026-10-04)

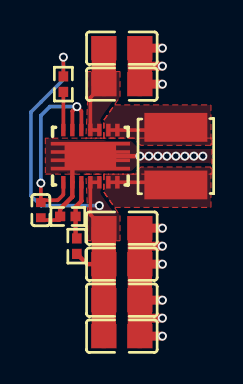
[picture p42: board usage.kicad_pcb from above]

Board: 2 copper layers, 12 parts (0 on the bottom side), 9 nets.

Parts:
C1, C2: 10µF ±10%; C0805
C3, C4, C5, C6: 22µF ±20%; C0805
C7: 100nF ±10%; C0402
L1: L 1µH ±20%; IND-SMD_L4.0-W4.0
R1: 107kΩ ±1%; R0402
R2: 19.1kΩ ±1%; R0402
R3: 1MΩ ±1%; R0402
U1: VSON-14_L4.0-W3.0-P0.50-BL-EP_TI_DSJ

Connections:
6: L1.2, U1.6, U1.7
8: L1.1, U1.8, U1.9
PG: R3.1, U1.14
hv: C7.1, U1.1, U1.12, U1.13
input_decoupling_capacitor[1]-power-hv: C1.1, C2.1, U1.10, U1.11
input_decoupling_capacitor[1]-power-lv: C1.2, C2.2, U1.2, U1.15
output_decoupling_capacitor[3]-power-hv: C3.1, C4.1, C5.1, C6.1, R1.1, R3.2, U1.4, U1.5
output_decoupling_capacitor[3]-power-lv: C3.2, C4.2, C5.2, C6.2, R2.2
ref_out-hv: R1.2, R2.1, U1.3

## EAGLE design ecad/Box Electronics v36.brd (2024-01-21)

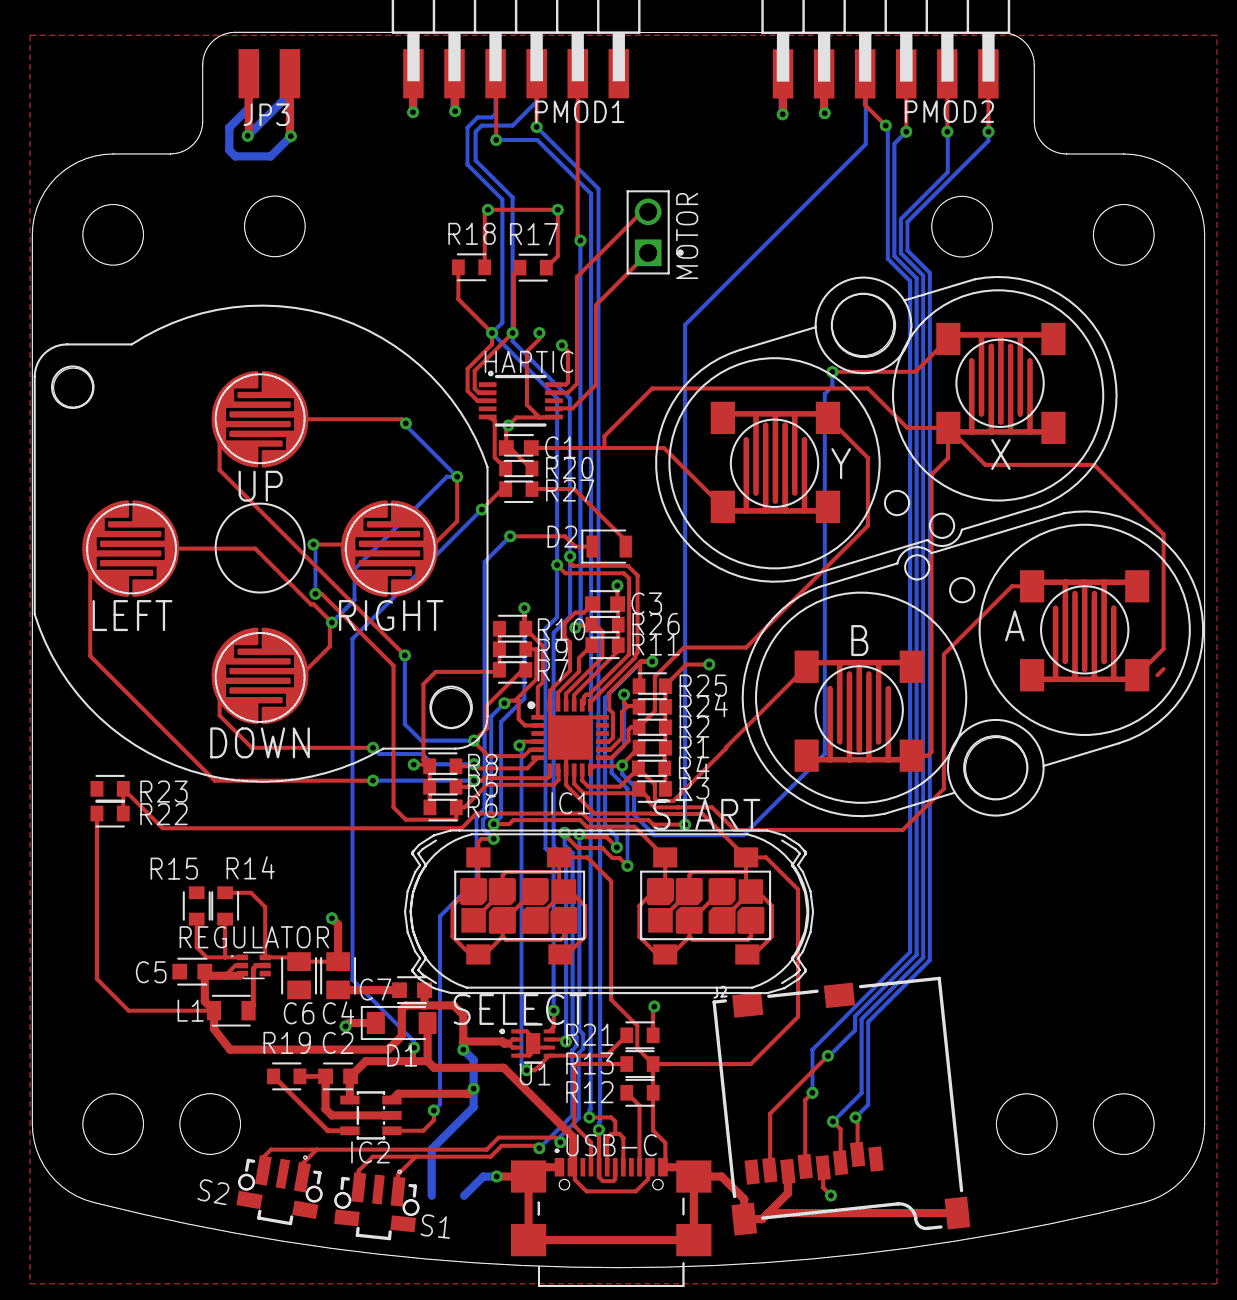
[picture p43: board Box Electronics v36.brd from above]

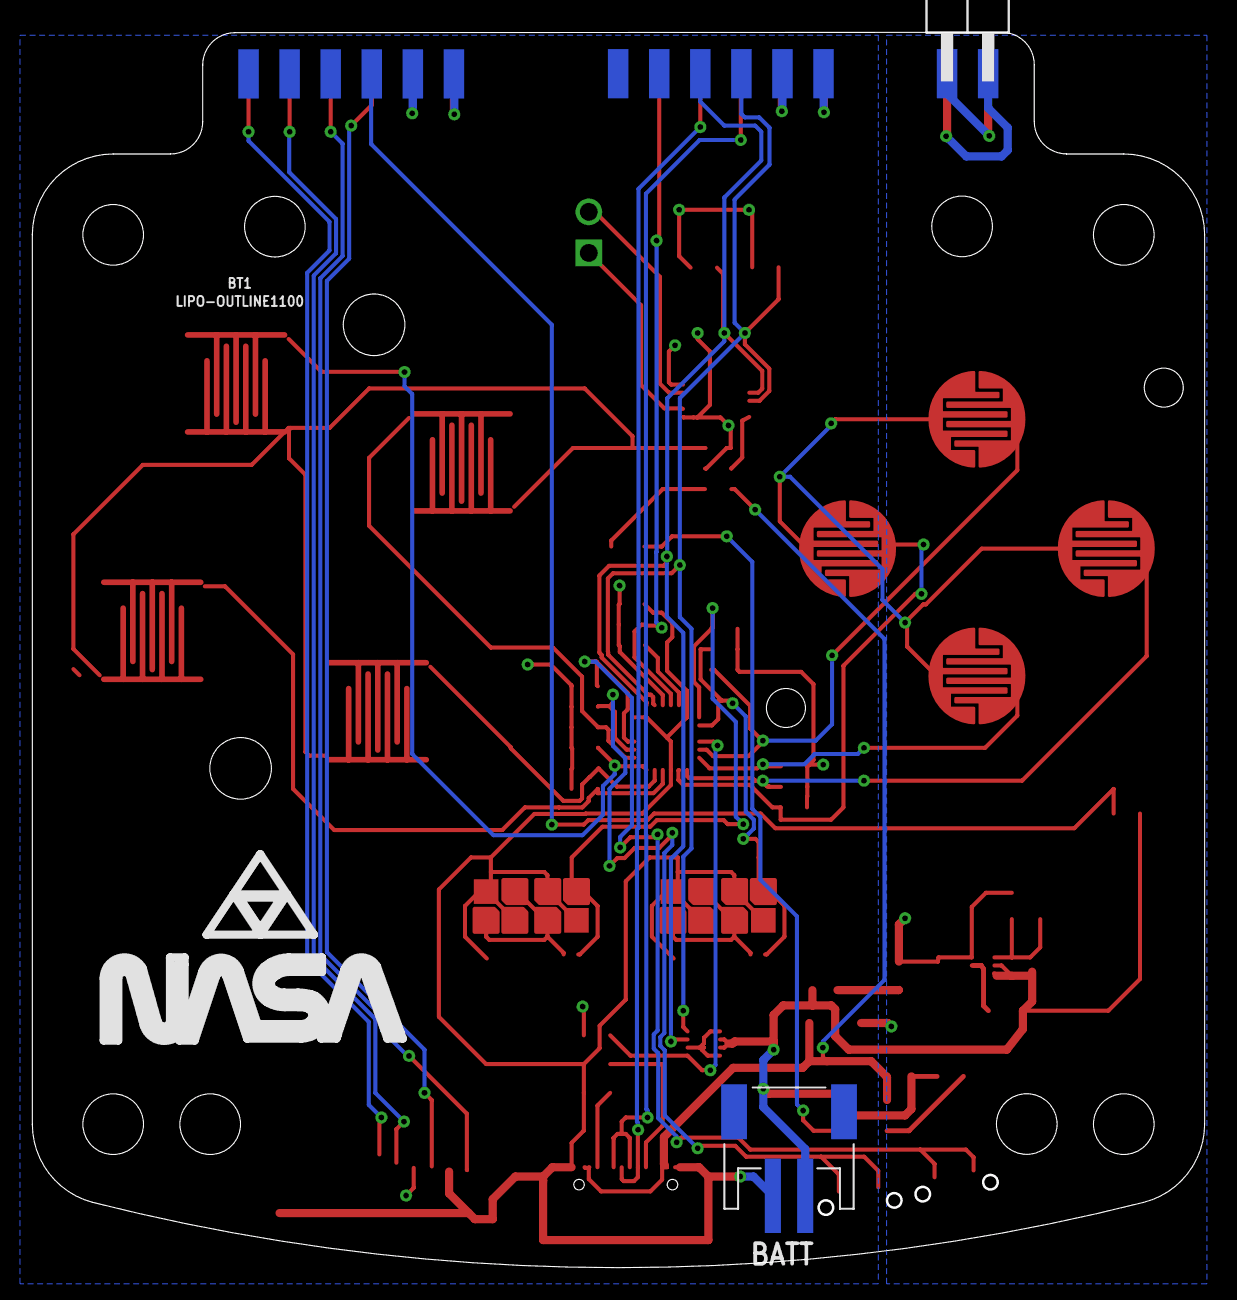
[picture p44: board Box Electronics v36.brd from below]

Board: 2 copper layers, 72.5 x 76.4 mm, 65 parts (3 on the bottom side), 39 nets.

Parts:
A: SWITCH_MOMENTARYDMG-BTN-A/B; DMG_BTN3
B: SWITCH_MOMENTARYDMG-BTN-A/B; DMG_BTN3
BATT: JSTPH2
BT1: LIPO-OUTLINE1100; LIPO-1000
C1, C3, C7: .1uF; CAPC1608X85
C2, C5: 10uF; CAPC1608X85
C4, C6: 22uF; CAPC2012X110
D1: MBR0520LT1G; SODFL3718X115
D2: LED_RED; LEDC2012X110N_FLAT-R
DOWN: SWITCH_MOMENTARYCONTACTIVE_6MM_2; BUTTON-CONDUCTIVE_6MM_2
HAPTIC: DRV2605L; VSSOP-10
IC1: AW9523BTQR; QFN50P400X400X80-25N
IC2: MCP73831/OT; SOT23-5L
J2: MICRO-SD_CARD_SOCKET; MICRO-SD-SOCKET
JP3: PINHD-2X2REVERSED; 2X02/EDGE_REVERSED
L1: 1uH; INDC2009X120
LEFT: SWITCH_MOMENTARYCONTACTIVE_6MM_2; BUTTON-CONDUCTIVE_6MM_2
MOTOR: 61300211121
PMOD1, PMOD2: PINHD-2X6REVERSED; 2X06/EDGE_REVERSED
R1, R2, R3, R4, R5, R6, R7, R8, R9, R10, R11, R20, R21, R22, R23, R24, R25, R26: 10k; RESC1608X60
R12, R13, R27: 5.1k; RESC1608X60
R14: 732k; RESC1608X60
R15: 100k; RESC1608X60
R17, R18: 1k; RESC1608X60
R19: 2.0k; RESC1608X60
REGULATOR: TPS61070; SOT563
RIGHT: SWITCH_MOMENTARYCONTACTIVE_6MM_2; BUTTON-CONDUCTIVE_6MM_2
S1, S2: TL3340AF160QG; TL3340
SELECT: SWITCH_MOMENTARYDMG-BTN-START/SELECT; DMG_BTN1_W2
START: SWITCH_MOMENTARYDMG-BTN-START/SELECT; DMG_BTN1_W2
U1: MAX17048G+T1021-0168E_T822-3_MXM; 21-0168E_T822-3_MXM
U$1: SILKSCREENGBC_D-PAD; GAMEBOY_COLOR_DPAD_SILK
U$2: SILKSCREENGBC_START/SELECT; GAMEBOY_COLOR_START_SELECT_SILK
U$3, U$4: SILKSCREENGBC_A/B; GAMEBOY_COLOR_A/B_BUTTON_MEMBRANE
UP: SWITCH_MOMENTARYCONTACTIVE_6MM_2; BUTTON-CONDUCTIVE_6MM_2
USB-C: 629722000214; USB4110GFA
X: SWITCH_MOMENTARYDMG-BTN-A/B; DMG_BTN3
Y: SWITCH_MOMENTARYDMG-BTN-A/B; DMG_BTN3

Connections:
3V3: C1.1, C3.1, HAPTIC.6, HAPTIC.10, IC1.21, J2.VCC, PMOD1.11, PMOD1.12, PMOD2.11, PMOD2.12, R1.2, R2.2, R3.2, R4.2, R5.2, R6.2, R7.2, R8.2, R9.2, R10.2, R11.2, R17.2, R18.2, R20.2, R21.1, R24.2, R25.2, R26.2
5V: C4.1, C6.1, D1.1, JP3.1, JP3.4, R14.2, REGULATOR.6
!BAT_ALERT: IC1.4, R21.2, U1.5
A: A.P$1, A.P$3, IC1.10, R3.1
B: B.P$1, B.P$3, IC1.11, R4.1
CLK: J2.SCLK, PMOD2.7
CS: J2.CS, PMOD2.1
DOWN: DOWN.1, IC1.6, R8.1
GND: A.P$2, A.P$4, B.P$2, B.P$4, BATT.1, C1.2, C2.2, C3.2, C4.2, C5.2, C6.2, C7.1, DOWN.2, HAPTIC.8, IC1.9, IC1.18, IC1.24, IC1.25, IC2.2, J2.GND, J2.GND1, J2.GND3, JP3.2, JP3.3, LEFT.2, PMOD1.9, PMOD1.10, PMOD2.9, PMOD2.10, R12.1, R13.2, R15.2, R19.1, R23.2, REGULATOR.4, RIGHT.2, S1.2, S2.2, SELECT.P$2, SELECT.P$4, START.P$2, START.P$4, U1.1, U1.4, U1.6, U1.9, UP.2, USB-C.A1, USB-C.A12, USB-C.B1, USB-C.B12, USB-C.MP1, USB-C.MP2, USB-C.MP3, USB-C.MP4, X.P$2, X.P$4, Y.P$2, Y.P$4
GPIO_INTN: IC1.22, PMOD1.3, R26.1
LEFT: IC1.7, LEFT.1, R5.1
M+: HAPTIC.7, MOTOR.1
M-: HAPTIC.9, MOTOR.2
unnamed: R12.2, USB-C.B5
unnamed: R13.1, USB-C.A5
unnamed: R14.1, R15.1, REGULATOR.1
unnamed: L1.2, REGULATOR.5
unnamed: IC2.5, R19.2
unnamed: HAPTIC.5, R20.1
unnamed: IC1.23, R11.1
unnamed: D2.A, R27.2
RIGHT: IC1.8, R6.1, RIGHT.1
SCK: HAPTIC.2, IC1.19, PMOD1.6, R17.1, U1.7
SDA: HAPTIC.3, IC1.20, PMOD1.8, R18.1, U1.8
SELECT: IC1.2, R9.1, SELECT.P$1, SELECT.P$3
SI: J2.DI, PMOD2.3
SO: J2.DO, PMOD2.5
START: IC1.1, R10.1, START.P$1, START.P$3
STAT2: D2.C, IC2.1
UP: IC1.5, R7.1, UP.1
USB_D+: PMOD1.7, USB-C.A6, USB-C.B6
USB_D-: PMOD1.5, USB-C.A7, USB-C.B7
VBAT: BATT.2, C5.1, C7.2, IC2.3, L1.1, R22.1, REGULATOR.2, REGULATOR.3, U1.2, U1.3
VBAT_SENSE: PMOD2.8, R22.2, R23.1
VBUS: C2.1, D1.2, IC2.4, R27.1, USB-C.A4, USB-C.A9, USB-C.B4, USB-C.B9
VOLUME_DOWN: IC1.15, R25.1, S2.1, S2.3
VOLUME_UP: IC1.14, R24.1, S1.1, S1.3
X: IC1.12, R1.1, X.P$1, X.P$3
Y: IC1.13, R2.1, Y.P$1, Y.P$3

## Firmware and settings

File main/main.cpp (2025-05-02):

#include <sdkconfig.h>

#include <chrono>
#include <memory>
#include <thread>
#include <vector>
#include <stdio.h>

#include "logger.hpp"
#include "task_monitor.hpp"
#include "timer.hpp"

#include "box-emu.hpp"
#include "carts.hpp"
#include "gui.hpp"
#include "heap_utils.hpp"
#include "rom_info.hpp"
#include "statistics.hpp"

using namespace std::chrono_literals;

extern "C" void app_main(void) {
  espp::Logger logger({.tag = "esp-box-emu", .level = espp::Logger::Verbosity::INFO});
  logger.info("Bootup");

  // initialize the hardware abstraction layer
  BoxEmu &emu = BoxEmu::get();
  logger.info("Box Emu version: {}", emu.version());

  // initialize
  if (!emu.initialize_box()) {
    logger.error("Failed to initialize box!");
    return;
  }

  if (!emu.initialize_sdcard()) {
    logger.warn("Failed to initialize SD card!");
    logger.warn("This may happen if the SD card is not inserted.");
  }

  if (!emu.initialize_memory()) {
    logger.error("Failed to initialize memory!");
    return;
  }

  if (!emu.initialize_gamepad()) {
    logger.warn("Failed to initialize gamepad!");
    logger.warn("This may happen if the gamepad is not connected.");
  }

  if (!emu.initialize_battery()) {
    logger.warn("Failed to initialize battery!");
    logger.warn("This may happen if the battery is not connected.");
  }

  if (!emu.initialize_video()) {
    logger.error("Failed to initialize video!");
    return;
  }

  if (!emu.initialize_haptics()) {
    logger.warn("Failed to initialize haptics!");
    logger.warn("This may happen if the gamepad is not connected.");
  }

  logger.info("initializing gui...");

  auto display = BoxEmu::Bsp::get().display();

  // initialize the gui
  Gui gui({
      .play_haptic = [&emu]() { emu.play_haptic_effect(); },
      .set_waveform = [&emu](uint8_t waveform) { emu.set_haptic_effect(waveform); },
      .log_level = espp::Logger::Verbosity::WARN
    });

  print_heap_state();

  // set the task priority (for main) to high
  vTaskPrioritySet(nullptr, 20);

  // main loop
  while (true) {
    // reset gui ready to play and user_quit
    gui.ready_to_play(false);
    while (!gui.ready_to_play()) {
      std::this_thread::sleep_for(50ms);
    }

    // have broken out of the loop, let the user know we're processing...
    emu.set_haptic_effect(gui.get_haptic_waveform());
    emu.play_haptic_effect();

    gui.pause();

    auto maybe_selected_rom = gui.get_selected_rom();
    if (maybe_selected_rom.has_value()) {
      auto selected_rom = maybe_selected_rom.value();
      logger.info("Selected rom:\n\t{}", selected_rom);

      print_heap_state();

      // Cart handles platform specific code, state management, etc.
      {
        std::unique_ptr<Cart> cart(make_cart(selected_rom, display));
        if (cart) {
          while (cart->run());
        } else {
          logger.error("Failed to create cart!");
        }
      }
    } else {
      logger.error("Invalid rom selected!");
    }

    // print the frame statistics from the previous run
    print_statistics();

    logger.info("Done playing, resuming gui...");

    logger.debug("Task table:\n{}", espp::TaskMonitor::get_latest_info_table());

    gui.resume();
    display->force_refresh();
  }
}

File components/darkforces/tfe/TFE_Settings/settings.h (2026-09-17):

#pragma once
//////////////////////////////////////////////////////////////////////
// The Force Engine Settings
// This is a global repository for program settings in an INI like
// format.
//
// This includes reading and writing settings as well as storing an
// in-memory cache to get accessed at runtime.
//////////////////////////////////////////////////////////////////////

#include <TFE_System/types.h>
#include <TFE_FileSystem/paths.h>
#include <TFE_Audio/midiDevice.h>
#include "gameSourceData.h"

enum SkyMode
{
	SKYMODE_VANILLA = 0,
	SKYMODE_CYLINDER,
	SKYMODE_COUNT
};

enum ColorMode
{
	COLORMODE_8BIT = 0,		// Default vanilla
	COLORMODE_8BIT_INTERP,	// Interpolate between colormap values.
	// COLORMODE_TRUE_COLOR,	// Will be enabled when the feature comes online.
	COLORMODE_COUNT,
};

#ifndef TFE_ESPBOX
static const char* c_tfeSkyModeStrings[] =
{
	"Vanilla",		// SKYMODE_VANILLA
	"Cylinder",		// SKYMODE_CYLINDER
};
#endif

struct TFE_Settings_Window
{
	s32 x = 0;
	s32 y = 64;
	u32 width = 1280;
	u32 height = 720;
	u32 baseWidth = 1280;
	u32 baseHeight = 720;
	bool fullscreen = true;
};

struct TFE_Settings_Graphics
{
	Vec2i gameResolution = { 320, 200 };
	bool  widescreen = false;
	bool  asyncFramebuffer = true;
	bool  gpuColorConvert = true;
	bool  colorCorrection = false;
	bool  perspectiveCorrectTexturing = false;
	bool  extendAjoinLimits = true;
	bool  vsync = true;
	bool  showFps = false;
	bool  fix3doNormalOverflow = true;
	bool  ignore3doLimits = true;
	s32   frameRateLimit = 0;
	f32   brightness = 1.0f;
	f32   contrast = 1.0f;
	f32   saturation = 1.0f;
	f32   gamma = 1.0f;
	s32   rendererIndex = 0;
	s32   colorMode = COLORMODE_8BIT;

	// 8-bit options.
	bool ditheredBilinear = false;

	// Reticle
	bool reticleEnable  = false;
	s32  reticleIndex   = 6;
	f32  reticleRed     = 0.25f;
	f32  reticleGreen   = 1.00f;
	f32  reticleBlue    = 0.25f;
	f32  reticleOpacity = 1.00f;
	f32  reticleScale   = 1.0f;

	// Bloom options
	bool bloomEnabled = false;
	f32  bloomStrength = 0.4f;
	f32  bloomSpread = 0.6f;

	// Sky (Ignored when using the software renderer)
	s32  skyMode = SKYMODE_CYLINDER;
};

enum TFE_HudScale
{
	TFE_HUDSCALE_PROPORTIONAL = 0,
	TFE_HUDSCALE_SCALED,
};

enum TFE_HudPosition
{
	TFE_HUDPOS_EDGE = 0,	// Hud elements on the edges of the screen.
	TFE_HUDPOS_4_3,			// Hud elements locked to 4:3 (even in widescreen).
};

enum PitchLimit
{
	PITCH_VANILLA = 0,
	PITCH_VANILLA_PLUS,
	PITCH_HIGH,
	PITCH_MAXIMUM,
	PITCH_COUNT
};

enum FontSize
{
	FONT_SMALL,
	FONT_MEDIUM,
	FONT_LARGE,
	FONT_XL
};

#ifndef TFE_ESPBOX
static const char* c_tfeHudScaleStrings[] =
{
	"Proportional",		// TFE_HUDSCALE_PROPORTIONAL
	"Scaled",			// TFE_HUDSCALE_SCALED
};

static const char* c_tfeHudPosStrings[] =
{
	"Edge",		// TFE_HUDPOS_EDGE
	"4:3",		// TFE_HUDPOS_4_3
};

static const char* c_tfePitchLimit[] =
{
	"Vanilla  (45 degrees)",
	"Vanilla+ (60 degrees)",
	"High     (75 degrees)",
	"Maximum"
};
#endif

struct TFE_Settings_Hud
{
	// Determines whether the HUD stays the same size on screen regardless of resolution or if it gets smaller with higher resolution.
	TFE_HudScale hudScale = TFE_HUDSCALE_PROPORTIONAL;
	// This setting determines how the left and right corners are calculated, which have an offset of (0,0).
	TFE_HudPosition hudPos = TFE_HUDPOS_EDGE;

	// Scale of the HUD, ignored if HudScale is TFE_HUDSCALE_PROPORTIONAL.
	f32 scale = 1.0f;
	// Pixel offset from the left hud corner, right is (-leftX, leftY)
	s32 pixelOffset[3] = { 0 };
};

struct TFE_Settings_Sound
{
	f32 masterVolume = 1.0f;
	f32 soundFxVolume = 0.75f;
	f32 musicVolume = 1.0f;
	f32 cutsceneSoundFxVolume = 0.9f;
	f32 cutsceneMusicVolume = 1.0f;
	s32 audioDevice = -1;			// Use the audio device default.
	s32 midiOutput  = -1;			// Use the midi type default.
	s32 midiType = MIDI_TYPE_DEFAULT;
	bool use16Channels = false;
	bool disableSoundInMenus = false;
};

struct TFE_Game
{
	char game[64] = "Dark Forces";
	GameID id;
};

struct TFE_GameHeader
{
	char gameName[64]="";
	char sourcePath[TFE_MAX_PATH]="";
	char emulatorPath[TFE_MAX_PATH]="";
};

struct TFE_Settings_Game
{
	TFE_GameHeader header[Game_Count];

	// Dark Forces
	s32  df_airControl = 0;				// Air control, default = 0, where 0 = speed/256 and 8 = speed; range = [0, 8]
	bool df_bobaFettFacePlayer = false;	// Make Boba Fett try to face the player in all his attack phases.
	bool df_smoothVUEs = false;			// Smooths VUE animations (e.g. the Moldy Crow entering and exiting levels)
	bool df_disableFightMusic  = false;	// Set to true to disable fight music and music transitions during gameplay.
	bool df_enableAutoaim      = true;  // Set to true to enable autoaim, false to disable.
	bool df_showSecretFoundMsg = true;  // Show a message when the player finds a secret.
	bool df_autorun = false;			// Run by default instead of walk.
	bool df_ignoreInfLimit = true;		// Ignore the vanilla INF limit.
	PitchLimit df_pitchLimit  = PITCH_VANILLA_PLUS;
};
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

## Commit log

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2022-10-17 copied and modified code from https://github.com/NiwakaDev/NIWAKA_NES into repo as esp component. still buggy, but getting better. only loads mario right now
    [main.cpp]
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2022-10-19 updated nes_lib so that it can use a provided pointer to memory containing the rom data. added mmap function to copy rom data from littlefs partition into a nesgame partition where it can be directly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
    [partitions.csv]
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2022-10-27 added gameboycore and gnuboy components; refactored main code to move various utils into separate files and to move rom_info into its own file; updated to support gameboy/color roms and to automatica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
    [main.cpp]
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2022-11-03 changed to no longer use esp-idf-cxx SPI subsystem for LCD because it abuses memory. updated with working controller input (new controller component using new espp::Joystick component)
    [main.cpp]
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2022-11-07 updated so that nes and gameboy emulators can coexist together; they can now also share the same framebuffer memory (which is nice) and that framebuffer is allocated in SPIRAM. Fixed the nes cpu to n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
    [main.cpp]
2022-11-08 updated so that there are two full NES-size (+overdraw) framebuffers in spiram that the NES emulator can use (one for the lcd color data and one for the sprite data) and the gameboy emulator uses the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
    [main.cpp]
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2022-11-14 allow for both scale and fill modes and updated emulation loop to cut down on cpu_emulate(...) call... which seems to have sped things up enough without introducing glitches..
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2022-11-29 Fixed minor bug in drv component (bad enum value); updated GUI to have haptic setting with play button for testing it out.
    [main.cpp]
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2023-04-09 feat(cart): WIP cart menu * Removed no longer needed Drv2605 component since espp submodule has it * Refactored main to use espp::Drv2605 and to configure it for LRA motor * Removed conflicting funct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
    [main.cpp]
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2023-05-07 feat(save): Refactor save state display * Updated save state display to move core logic into each emulator component / cart * Emulation state display now works for both the NES and GB/C emulators * U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
2023-05-08 bug(display): fix spi transmit failure * Remove IRAM_ATTR from lcd write functions, has no effect on the speed, but improves stability closes #12
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2023-06-27 feat(submodule): update espp * Pull in bugfixes and new features from latest espp submodule * Update mute button handling (i2s_audio, menu, gui) using event manager to use new std::vector api instead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
2023-10-16 closes #31 fix gameboy scaling * Update how gb/c scaling works (to make sure we always compute the right number of lines) * Revert removal of IRAM_ATTR since it dramatically slows down GBC emulation 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
2023-11-05 refactor: update peripheral (i2c) api to match new espp submodule update which allows for error management and propagation.
    [main.cpp]
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2023-11-11 feat(input): reworked input stack * Have touchscreen and gamepad input run consistently, within its own task - so that the getter functions merely return the latest data for more consistent performan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
    [main.cpp]
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2023-11-27 fix(cart): made destructor virtual to be overrided by subclasses * Fixed Cart base class so that destructor is virtual and can be overridden by derived classes and derived destructors will be properl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
    [main.cpp, sms_cart.hpp]
2023-11-28 fix(lcd): update lcd function to have write function also call wait lines and remove the no longer necessary sleeps when changing from lvgl to rom
    [main.cpp]
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2023-12-17 added missing bom
    [Box-3 Electronics v5.csv]
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2023-12-18 fixed inductor in bom
    [Box Electronics v25.xlsx, Box-3 Electronics v5.xlsx]
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2023-12-24 feat(gui): update gui to handle metadata * Moved rom_info related stuff to its own component so that it can be used by the gui * Moved metadata parsing from main into gui and have it run in construct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
    [main.cpp]
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2023-12-28 fix use of virtual functions in cart constructor / destructor
    [sms_cart.hpp]
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2023-12-28 feat(ui): add battery status indication * Update espp submodule to fix bug when unsubscribing from an event * Update menu to properly unsubscribe the menu component instead of the gui component (copy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
    [main.cpp]
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2023-12-30 reset sms to ensure state is good
    [main.cpp]
2023-12-31 fixed sms scaling and color palette
    [sms_cart.hpp]
2024-01-03 feat(sms): fleshing out SMS/GG * Added audio code to sms component * Fixed cache memory size issue * WIP sizing of SMS and GG displays (right now GG is boxed in)
    [sms_cart.hpp]
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2024-01-07 feat(sms): switch to smsplus from retro-go project * Working sound * Mostly working display (palette seems to be wrong for some colors?) * Working scaling * Working saving and loading of both gg and 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
    [sms_cart.hpp]
2024-01-07 fixed sms static analysis and updated defaults so that all DMA is saved for DMA and main task stack size is reduced by 2k
2024-01-08 fix(es7210): fix i2c write * Return proper success value from i2c write funtion to es7210
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2024-01-18 fix(gui): fix gui task stack size to be larger in the case of activating usb msc
2024-01-18 fix(ui): fix audio button handler * Fix mute button event handler in menu and gui for error introduced in #56
2024-01-21 fix(cad): update ecad / mcad * Updated ecad to have LED power come from VBUS instead of 3v3 so that it lights up even if the module is not plugged in * Upeated ecad to fix volume button switch footpr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
    [Box Electronics v25.xlsx, Box Electronics v26.sch, Box Electronics v36-smt.csv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]
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2024-03-04 felshing it out and trying to get power supply and battery measurement constraints input correctly
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2024-03-05 fleshing out more wiring and reworked pmod into separate module
    [esp-box-emu.kicad_pcb]
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2024-06-15 update charger to run off vbus (correctly) and to have programming resistor
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2024-06-21 replace tabs with spaces (damn you vscode) and add missing B18 pin; also fix wiring in box and box3
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2024-06-22 remove default and start fleshing out layouts. fixed issue with fab extending beyond edge cuts in box-3-connector footprint (CONN_5_)
    [box-3-connector.kicad_pcb, box-3-emu.kicad_pcb, box-emu-base.kicad_pcb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]
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2024-06-23 update so 3d models are configured correctly
    [box-3-emu.kicad_pcb, box-emu-base.kicad_pcb, box-emu.kicad_pcb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]
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2024-06-23 fix improper pin assignment / order that was copied from easyeda (which has the wrong config)
2024-06-23 update layouts to use latest footprints and fixed volume buttons and include address pins
    [box-emu-base.kicad_pcb, gbc-a-b-x-y.kicad_pcb, gbc-a-b.kicad_pcb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]
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2024-06-24 added diode from vbus to 5v rail; added qwiic connector for easier debugging; fixed names of jlcpcb components; added motor header
    [box-emu-base.kicad_pcb, qwiic-connectors.kicad_pcb, qwiic-connectors.kicad_sch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]
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2024-06-24 Revert "cleanup a bunch of extra files"
    This reverts commit 1960f419598b1dde5354d48905e1482de05d6a9a.
    [esp-box-emu.kicad_pcb, esp-box-emu.kicad_sch, gbc-start-select.kicad_pcb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]
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2024-06-26 fix box-3 connector pin configuration (lcsc / easyeda model was wrong). updated associated layouts
    [box-3-connector.kicad_pcb, box-3-emu.kicad_pcb]
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2024-06-26 fix dpad and a/b button footprints to have mask and paste on pads
    [box-3-emu.kicad_pcb, box-emu-base.kicad_pcb, box-emu.kicad_pcb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]
2024-06-28 fix led ato pin configuration; add some wiring for CTG / external pad on MAX17048; add pullup resistor and bypass capacitors; continue fleshing out routing
    [box-3-emu.kicad_pcb, box-emu-base.kicad_pcb, box-emu.kicad_pcb]
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2024-07-04 fix(touch): Initialize touch after display so it works with lvgl
    [box-emu.cpp]
2024-07-05 Only run atopile action on ecad changes and render 3d image output of ecad (#77)
    * update atopile action to only run on electrical changes and test render 3d with kibot
    * remove incorrect type
    * update other ci actions to only run when they should
    * remove custom data (nonexistent) from print pdf output
    * move zip to after kibot
    * separate out kibot outputs to make it easier to add them
    * remove -j for testing
    * add back -j and be explicit about which files to export. remove -r to not recurse subdirectories
    * switch from v2_k7 to just v2 to test
    * revert version change and add diff view
    * remove empty kicad_3d_url key
    * testing
    * fix duplicate
    * remove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
2024-07-15 fix: Update to better support case that the hardware isnt found (#80)
    [box-emu.cpp]
2024-07-27 Fix/atopile ecad (#82)
    * fix(ecad): Fix bugs in atopile version of the design
    * Add missing pullup resistors to AW9523 RSTN and INTN lines
    * Fix I/O configuration for AW9523 so that all the inputs go to the same port pins as the previous version of the electronics
    * minor cleanup to box3 after update to at 0.2.58
    * fix udpate max17038 pullup to properly go to alert line after other fix
    * typo
    * update layout
    * minor update to layout
    * fix(buttons): pulldown -> pullup (so they are active low)
    * update buttons to be pullup instead of pulldown; change led to be powered off VBUS instead of vbat
    * update button footprints - start/select better aligned and all buttons hav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
    [box-3-connector.kicad_pcb, box-3-emu.kicad_pcb, box-emu-base.kicad_pcb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]
2024-08-23 [BREAKING] Update espp for LVGL v9 and refactor some components (#87)
    * chore: Update to LVGL v9
    * wip trying to get it working...
    * update espp to latest main
    * update espp submodule
    * update to latest espp
    * move haptics into box-emu component
    * wip guis
    * update color format
    * fix sms color
    * added log about how many were loaded
    * update menu task management
    * update gui to use HRT for task and have roller use quick animation
    * update to use latest apis - use new haptics apis and such
    * decrease default transition time and refresh period, add 80mhz flash freq
    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
    [box-emu.cpp, box-emu.hpp, main.cpp]
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2024-10-14 Improve genesis emulation (#88)
    * wip some tests
    * reduce full frameskip back to 3 and fix sa
    * fix genesis some
    * working / good genesis audio
    * update sdkconfig
    * fix sa
    * update readme
    * minor update to patches
    [main.cpp]
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2025-03-09 feat: Update to remove display task (espp update) and fix sa for carts (#94)
    * feat: Update to remove display task (espp update) and fix sa for carts
    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
    [box-emu.cpp, main.cpp]
2025-03-20 feat(box-emu): Refactor to reduce deps on EspBox, instead depending on box-emu (#96)
    * Update `box-emu` component to include wrappers / accessors for some underlying audio and video functions from the EspBox
    * Update all other affected components to replace access of `EspBox::` with `BoxEmu::` wrappers, so that it would be easier / simpler to target other systems
    WIP to support #95
    Ensure the project still builds
    [box-emu.cpp, box-emu.hpp]
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2025-05-01 Feat/doom (#101)
    * wip doom
    * wip
    * add doom which compiles
    * fleshing out
    * wip audio video
    * working gfx display
    * fix inputs
    * wip moving doom over to shared memory
    * wip moving more into shared memory
    * add boxart
    * add doom ultimate boxart
    * update to latest tool
    * continue moving doom to shared memory
    * move more into shared memory
    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
    [box-emu.cpp, box-emu.hpp]
2025-05-02 feat(doom): Add haptic feedback to doom (#102)
    * feat(doom): Add haptic support to doom
    * Update doom to have callbacks for when the player is damaged and when they fire a weapon
    * Update doom implementation to trigger different haptic effects depending on the weapon fired and the amount of damage taken
    Haptics are awesome, and with doom we have the actual source code so we can do some fun stuff :)
    Build and run `main` on Box-Emu v0 which has haptics and ensure it feels good.
    * improve maintainability
    * more haptics
    * add player interaction haptics and fix sa
    * Update components/doom/src/doom.cpp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
    [main.cpp]
2025-11-03 chore: Update to use espp IDF components from component registry, also update some deps (#108)
    * chore: Update to use espp IDF components from component registry, also update some deps
    * update to esp-idf v5.5 and add delta action
    * simplify main manifest
    * fix build
    * fix example build
    [box-emu.cpp, box-emu.hpp]
2026-06-20 feat(genesis): Significantly improve performance, splitting emulation across both cores for 60fps with audio no frameskip required :rocket: (#110)
    * feat: Update deps to support esp-idf v6.0
    * test
    * improve perf some and fix audio issues
    * vdp improvement
    * test
    * 56 fps on sonic 1
    * 42.4 fps frameskip 1
    * 43 fps
    * improved performance some
    * turn off profiling
    * initial parallel emulation; working audio+gameplay for sonic 3; others somewhat broken
    * improve emulation to fully playable 60fps
    * high fps good sound genesis using dual core
    * clean up working code
    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
    [Z80.c, box-emu.cpp, box-emu.hpp]
2026-06-23 fix remaining issues with doom; ensure music plays on subsequent launches; ensure different doom titles can be launched back to back many times without crash or memory pressure (#114)
2026-09-17 feat: add Star Wars: Dark Forces (The Force Engine port) (#120)
    * feat(darkforces): port Dark Forces (The Force Engine) as a new system
    Add a `darkforces` component built on BSzili's Amiga branch of The Force
    Engine (TFE v1.09.410, commit d116b7a9), which already strips the desktop
    subsystems and provides low-spec code paths. The `__AMIGA__` guards are
    renamed to `TFE_ESPBOX`; provenance and the list of vendored changes are in
    components/darkforces/VENDOR.md.
    ESP32 platform layer (components/darkforces/src/platform):
    - esp_render: the classic fixed-point renderer draws into BoxEmu frame
    buffer 0 (8-bit 320x200) and the palette is converted to RGB565.
    - esp_audio: FreeRTOS task mixing the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
    [metadata.csv]
2026-10-01 feat: LVGL memory in PSRAM, espp sdcard/usb_device components, dependency update (#121)
    * feat: LVGL memory in PSRAM; use the espp sdcard / usb_device components; update dependencies
    - LVGL is built with CONFIG_LV_USE_CUSTOM_MALLOC: components/box-emu/src/lvgl_mem.c
    allocates from the PSRAM heap (falling back to internal RAM only if PSRAM is
    exhausted) instead of a fixed pool in internal RAM, and reports the PSRAM heap
    to lv_mem_monitor().
    - The uSD card is managed by espp::SdCard (card initialization and FAT mounting
    as separate steps), replacing the hand-rolled SDSPI + esp_vfs_fat_sdspi_mount
    code.
    - USB mass storage uses espp::UsbDevice's MSC function: the card's volume is
    un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
    [box-emu.cpp, box-emu.hpp]
2026-10-01 fix(darkforces): fit the post-mission cutscenes and level 2 on the 8MB box (#123)
    - Each cutscene scene's sounds are released when the scene ends (previously only
    when it was skipped): across the twelve post-mission scenes they added up to
    over 1MB in the game region.
    - The level, objects, goals and INF loaders parse through a 64KB window of the
    file (TFE_Parser::initFromFile) instead of reading the whole file into one
    buffer; TALAY.LEV alone needed 814KB contiguous. FileStream remembers its
    archive entry so the window can be refilled after other files from the same
    archive were opened.
    - The escape menu releases its frames whenever it closes (also through
    abort / next / quit),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
2026-10-04 feat(ecad): Update ECAD to support latest atopile and fix some bugs (#119)
    * feat(ecad): Update ecad / atopile and improve workflow
    * add step file to repo
    * add box-3 step file
    * improve workflow
    * update the action to latest and fix some bugs / spurious issues
    * remove legacy files
    * update deprecations
    * improve placement of components and robustness of scripts
    * nudge layouts some
    * further layout changes
    * fixing some issues
    * fix broken ci
    * minor update
    * simple layout
    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
    [2.STEP, C0402_L1.0-W0.5-H0.5.step, C0805_L2.0-W1.3-H1.3.step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]
2026-10-05 fix(darkforces): clear static-analysis findings in the ESP32 port layer (#124)
    * fix(darkforces): clear static-analysis findings in the ESP32 port layer
    cppcheck (run on the whole tree, report_pr_changes_only=false) flagged
    the Dark Forces ESP32 port layer. Fix the ones that are our own code,
    and suppress the rest, which are bound to the vendored TFE engine's API.
    Fixed in code:
    - esp_memory.cpp: default-initialize the internal MemoryBlock /
    MemoryRegion / CallerStat members (uninitMemberVarNoCtor).
    - esp_alloc.cpp, esp_audio.cpp: two live old-style C-casts -> C++
    reinterpret_cast (dangerousTypeCast).
    - esp_thread.cpp: const accessors (functionConst), m_done moved to the
    constructor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
2026-10-10 feat: add PICO-8 (femto8) (#126)
    * feat(pico8): add PICO-8 (femto8)
    Vendors femto8 (benbaker76/femto8 @ f9e5097) as components/pico8 with an
    esp-box-emu platform: the cart runs in its own task, frames are palette
    indices scaled by the emulator, audio is rendered on core 1, and the Lua
    instruction hook is the pause/quit point so the core stops cleanly and
    relaunches without a reboot (statics reset through linker SURROUND symbols).
    Claude-Session: https://claude.ai/code/session_01AWhoGwibqcKDhcG17mjVT1
    * fix(pico8): pace the audio task on the bytes the BSP actually queued
    Claud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
2026-10-12 feat(perf): memory census, Genesis frame-time breakdown, capture/report tools (#127)
    * feat(perf): memory census, Genesis frame-time breakdown, capture/report tools
    Phase 1 of the Sonic performance / memory plan: instrumentation only, no
    behaviour change.
    - components/statistics/memory_census: `[mem] phase=boot|menu|launch|quit`
    lines with internal/PSRAM free + largest block + low-water mark, and
    `[mem] delta` lines at launch and quit against the menu snapshot, so a leak
    or fragmentation across a play cycle is a number. Replaces main/heap_utils.
    - genesis: GENESIS_PERF (default on) cycle-counter buckets per scanline --
    68k, VDP render+convert, core-0 barrier wait, present/audio, pa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
2026-10-12 perf: internal RAM, display-aware frame skip, 60 Hz pacing, Sonic 3 Z80 V-int fix, PICO-8 fast paths (#128)
    * perf: reclaim internal RAM for the emulator cores
    Phase 2 of the Sonic performance / memory plan, driven by the Phase 1 census
    (PR #127). At the menu the largest contiguous internal block goes from 102 KB
    to 131 KB and free internal RAM from 147 KB to 174 KB:
    - CONFIG_SPIRAM_MALLOC_RESERVE_INTERNAL 256K -> 0. The reserve was realised by
    esp_psram carving the two largest free blocks (184 KB + 72 KB) out of the
    main heap and re-registering them as nested internal/DMA-only heaps, which
    capped the largest block at ~100 KB. Plain malloc() already goes to PSRAM
    first (ALWAYSINTER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
2026-10-13 ecad: rename a part symbol file whose name Windows cannot check out (#130)
    `ecad/elec/src/parts/Ckmtw_B_2100S02P_A110/210S-1*2PL=11.6MMGold-platedblack.kicad_sym`
    contains `*`, which is not a legal path character on Windows. Every run of
    "Build and Package Main" since the ecad update has failed in the package job:
    its action checks the repository out on windows-latest, and git aborts with
    `error: invalid path 'ecad/elec/src/parts/.../210S-1*2PL=...kicad_sym'`.
    Rename it to `210S-1x2PL_11.6MMGold-platedblack.kicad_sym` (also dropping `=`)
    and update the symbol names inside it and the `symbol=` reference in the
    part's `.ato` trait. It is the only tracked path with a Windows-illegal
    character.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
2026-11-11 Use the shared gwenesis and femto8 cores as submodules (#132)
    * Use the shared gwenesis and femto8 cores as submodules
    The Genesis core and glue now live in esp-cpp/gwenesis (branch esp32) and
    the PICO-8 core and glue in esp-cpp/femto8 (branch esp32), both shared with
    tab5-emu. Board differences are compile-time gates in the port/ glue
    (GENESIS_HOT_IN_PSRAM, GENESIS_DUAL_CORE, PICO8_AUDIO_VIA_EMU, ...), so the
    ESP32-S3 build is unchanged.
    The Genesis core also gains two line-interrupt fixes:
    - V-int is asserted 788 master cycles into line 224, so an H-int raised at
    the end of line 223 is taken first (Sonic 2 Chemical Plant was drawn
    entirely with the underwater palette whenever the wat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
2026-11-13 Launcher features, USB link (console, test control, SD drive, OTA), emulink (#133)
    * launcher: games grouped by console, console badge, saved settings, resume
    - The rom roller is grouped by console (NES, SNES, Game Boy, Game Boy
    Color, Master System, Game Gear, Genesis, MSX, PC, PICO-8) with a header
    row per console that selection steps over; metadata.csv order within one.
    - The selected game's console replaces the title in the launcher's header:
    boxart/consoles/<key>.jpg from the SD card if present, else a badge drawn
    from LVGL objects (a generic icon and the short name, no logos).
    - Settings survive a power cycle in /sdcard/settings.bin (espp
    persistent_data, versioned): volume,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
2026-11-13 Move the NES, GB/GBC, MSX, SMS/GG, Doom and Dark Forces cores to submodules
    Each core now lives in its own esp-cpp repo with its port/ glue to BoxEmu,
    split out of this repo with its history, so tab5-emu can share it:
    - components/nes/nofrendo -> esp-cpp/nofrendo
    - components/gbc/gnuboy -> esp-cpp/gnuboy
    - components/msx/fmsx -> esp-cpp/fmsx
    - components/sms/smsplus -> esp-cpp/smsplus (Master System and Game Gear)
    - components/doom/prboom -> esp-cpp/prboom (with data/)
    - components/darkforces/TheForceEngine -> esp-cpp/TheForceEngine
    The component CMakeLists.txt and linker fragments stay here as the board's
    wrappers. Static analysis skips the submodules, as it does gwenesis and
    femto8.
    Co-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
2026-11-13 Pin esp_tinyusb to 3.0.0
    esp_tinyusb 3.0.1 (TinyUSB 0.21.0~6, the DWC2 SETUP-DMA erratum
    workaround) corrupts the PSRAM heap on esp-box-emu while a Genesis game
    runs: the link task's next allocation hits a tlsf assert or an MMU entry
    fault. With 3.0.0 the same firmware is fine (checked on the box with the
    same commit built both ways). A fresh build resolves '>=3.0.0' to 3.0.1,
    so CI would have shipped it.
    Claude-Session: https://claude.ai/code/session_01SFCMzomCZ5wRHJN4sxwkvY
2026-11-13 Revert "Pin esp_tinyusb to 3.0.0"
    The heap corruption seen with Sonic 2 on the box turned out to be
    intermittent: the same builds that failed also pass repeated trials, so
    the runs that blamed esp_tinyusb 3.0.1 were not evidence of a cause. The
    corruption is tracked separately; no pin until it is understood.
    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
2026-11-13 Fix the audio pop on game start / exit and Genesis save-state sound
    - BoxEmu::audio_sample_rate(): skip a switch to the current rate, and hold
    the speaker amplifier off across a real switch (the I2S clocks stop and the
    ES8311 dividers are reprogrammed, which popped every time a core set its
    rate and again when it restored 48 kHz)
    - gwenesis: rebuild the YM2612 operator routing / detune pointers and keep
    this build's audio rates after loading a save state; a save from another
    build left the FM output silent and wrote to stray memory
    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

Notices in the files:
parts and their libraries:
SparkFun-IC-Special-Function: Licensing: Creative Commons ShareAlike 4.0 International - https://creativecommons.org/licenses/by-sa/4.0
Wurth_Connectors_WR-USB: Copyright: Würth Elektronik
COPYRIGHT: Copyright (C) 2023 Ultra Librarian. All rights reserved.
